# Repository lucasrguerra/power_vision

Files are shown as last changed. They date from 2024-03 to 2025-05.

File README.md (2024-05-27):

# Power Vision

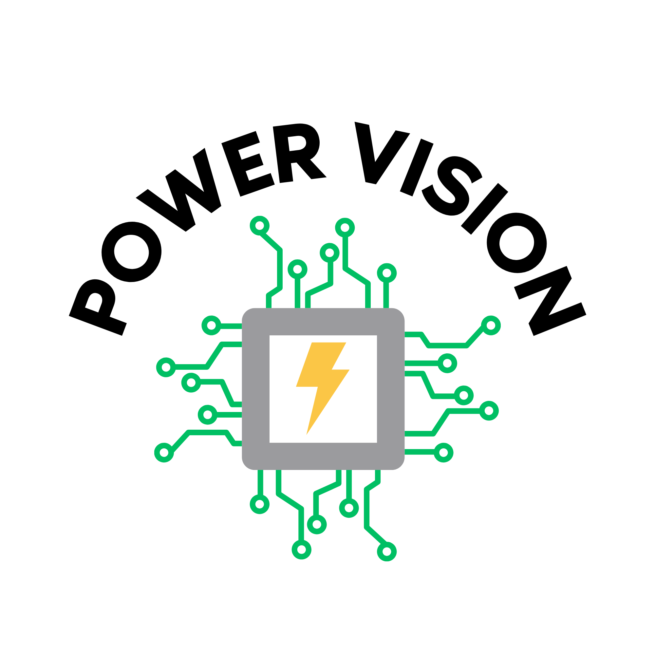
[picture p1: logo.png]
Power Vision


## Descrição

O Power Vision é um projeto de código aberto destinado ao desenvolvimento de um analisador de qualidade da energia elétrica em tempo real utilizando um hardware de baixo custo com o microcontrolador ESP32-S3. Este analisador é capaz de medir e calcular uma variedade de parâmetros elétricos em sistemas monofásicos e trifásicos, fornecendo informações cruciais para análise e monitoramento de consumo de energia.

O projeto foi desenvolvido como Trabalho de Conclusão de Curso (TCC) do curso de Ciência da Computação da Universidade Federal Rural de Pernmabuco (UFRPE) e orientado pelo Prof. Dr. Abner Corrêa Barros. O projeto tem como objetivo principal a implementação de um analisador de energia elétrica de baixo custo e alta precisão, que possa ser utilizado em residências, empresas e indústrias para monitoramento e análise de consumo de energia.

## Funcionalidades

O Power Vision atualmente tem na teoria as seguintes funcionalidades:

- **Frequência (Hz)**: Medição da frequência do sistema.
- **Tensão True RMS (Vac)**: Medição precisa da tensão eficaz do sistema.
- **Corrente True RMS (A)**: Medição precisa da corrente eficaz do sistema.
- **Potência Aparente (kVA)**: Cálculo da potência aparente do sistema.
- **Distorção Harmônica Total (%)**: Avaliação da distorção harmônica no sistema.
- **Cosseno φ**: Cálculo do cosseno do ângulo de fase.
- **Fator de Potência (%)**: Determinação do fator de potência do sistema.
- **Potência Ativa (kW)**: Cálculo da potência ativa consumida pelo sistema.
- **Potência Reativa (kVAr)**: Cálculo da potência reativa do sistema.
- **Potência de Distorção (kVAD)**: Cálculo da potência de distorção do sistema.

## Limites de medição

Assim como qualquer equipamento de medição, o Power Vision possui limites de medição para cada parâmetro elétrico. Abaixo estão os limites de medição que este projeto visa alcançar:

### Frequência
O dispositivo possiu uma forma versátil de calcular a frequência, se mas o intervalo de leitura esperado é entre 45Hz e 60Hz.

### Tensão
O dispositivo é destinado a medições em sistemas residenciais, comerciais e industriais de pequeno e médio porte, para isso, o dispositivo conta com 4 níveis possíveis de tensão de fase (não confundir com tensão de linha, que é a tensão entre fases), sendo eles:

Nível 0 = 0-475Vac (Padrão 440V)  
Nível 1 = 0-440Vac (Padrão 380V)  
Nível 2 = 0-275Vac (Padrão 220V)  
Nível 3 = 0-175Vac (Padrão 127V)  

### Corrente
O dispositivo é destinado a medições em sistemas residenciais, comerciais e industriais de pequeno e médio porte, para isso, o dispositivo conta com 7 níveis possíveis de corrente, sendo eles:

Nível 0 = Até 1000A  
Nível 1 = Até 750A  
Nível 2 = Até 500A  
Nível 3 = Até 300A  
Nível 4 = Até 200A  
Nível 5 = Até 120A  
Nível 6 = Até 80A  

## Estrutura do Projeto

O projeto está organizado da seguinte forma:

- **[`src/`](./src/)**: Contém o código fonte principal do analisador de energia, que vai no Microcontrolador. (Em desenvolvimento 🛠️)

- **[`docs/`](./docs/)**: Documentação do projeto, incluindo manuais de usuário, especificações técnicas e outras informações relevantes.

- **[`theory/`](./theory/)**: Esta pasta contém implementações em Python das fórmulas utilizadas antes de serem integradas ao código principal do microcontrolador. (Sendo atualizado para a transformada Wavelet 🛠️)

- **[`boards/`](./boards/)**: Contém informações sobre as placas desenvolvidas para o projeto e os arquivos de fabricação no formato Gerber.

## Como Contribuir

Sinta-se à vontade para contribuir com o projeto! Você pode:

- Reportar problemas encontrados.
- Propor melhorias e novas funcionalidades.
- Enviar correções ou otimizações de código.
- Compartilhar suas experiências e ideias.

## Como Utilizar

Para utilizar o Power Vision, siga estas etapas:

1. Clone o repositório para o seu ambiente de desenvolvimento com o PlatformIO instalado.
2. Instale as dependências necessárias:
    (Atenção: Este projeto ainda não possui dependências)
3. Compile e carregue o código no seu ESP32-S3.
4. Monte o circuito conforme o esquemático disponível na pasta [`docs/`](./docs/).
4. Conecte o analisador de energia ao sistema que deseja analisar.
5. Inicie o analisador e visualize os resultados pela interface serial.

## Créditos

Este projeto foi criador por [Lucas Rayan](https://www.linkedin.com/in/lucasrguerra/) (vulgo "eu") e continua sendo mantido por ele.

## Agradecimentos

A minha mãe, que sempre lutou muito para que eu e minha irmã tivéssemos uma boa educação, e que sempre me apoiou em todas as minhas decisões. E que é sem dúvida a pessoa mais importante da minha vida.

Ao [Prof. Dr. Abner Corrêa Barros](https://www.linkedin.com/in/abner-barros-5b86409/), meu orientador, que sempre esteve disposto a ajudar e doar seu tempo e conhecimento para contribuir com o desenvolvimento do projeto.

A minha grande amiga e companheira de vida, [Vitória das Dores](https://www.linkedin.com/in/vitoria-das-dores/), que sempre esteve ao meu lado me apoiando e me ajudando a superar todos os desafios.

Ao meu grande amigo e grande Engenheiro Eletrônico, [João Pontes](https://www.linkedin.com/in/joão-victor-b-pontes-b37006116/), que sempre esteve disposto a ajudar e ouvir minhas ideias e dúvidas.

## Licença

Este projeto está licenciado sob a Licença MIT. Consulte o arquivo [LICENSE](./LICENSE) para obter mais detalhes.

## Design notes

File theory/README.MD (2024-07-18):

# Teoria do Power Vision

Bem-vindo à documentação da teoria por trás do Power Vision. Este documento fornece informações detalhadas sobre a matemática e os cálculos utilizados no projeto para medir e calcular parâmetros elétricos, como tensão, corrente, potência ativa, potência reativa, fator de potência e muito mais.

## Componentes de Hardware

### Resistores para a corrente (Rcurr)

Para calcular a corrente do sistema, é necessário utilizar resistores de baixa resistência, e essa resistência é calculada levando em consideração a tensão máxima que pode ser medida pelo microcontrolador com uma margem de erro. Para simplificar os cálculos, o Jupyter Notebook [calculate_limits_of_current.ipynb](./calculate_limits_of_current.ipynb) foi criado para calcular os parâmetros de acordo com os resistores utilizados.

| Corrente Máxima do Sistema | Relação do Sensor | Corrente no Secundário | Tensão Pico a Pico no Secundário | Resistência (±1%) | Relação da Transformação |
| --- | --- | --- | --- | --- | --- |
| 1000A | 3000:1 | 0.33333A | 2.3094V  | 2Ω | 1500 |
| 750A  | 3000:1 | 0.25A | 2.33827V | 2.7Ω | 1111.11 |
| 500A  | 3000:1 | 0.16667A | 2.48261V | 4.3Ω | 697.674 |
| 300A  | 3000:1 | 0.1A | 2.35559V | 6.8Ω | 441.176 |
| 200A  | 3000:1 | 0.06667A | 2.3094V  | 10Ω  | 300 |
| 120A  | 3000:1 | 0.04A | 2.49415V | 18Ω  | 166.667 |
| 80A | 3000:1 | 0.02667A | 2.49415V | 27Ω  | 111.111 |
| 100A  | 2000:1 | 0.05A | 2.07846V | 12Ω  | 166.667 |
| 20A | 2000:1 | 0.01A | 2.35559V | 68Ω  | 29.4118 |

### Resistores para a tensão (Rvolt)

Para calcular a tensão do sistema, é necessário utilizar resistores de baixa e alta resistência, e essa resistência é calculada levando em consideração a tensão máxima que pode ser medida pelo microcontrolador com uma margem de erro e respeitando os limites do transfomador utilizado. Para simplificar os cálculos, o Jupyter Notebook [calculate_limits_of_voltage.ipynb](./calculate_limits_of_voltage.ipynb) foi criado para calcular os parâmetros de acordo com os resistores utilizados.

_**Nota:** Os valores de resistência foram calculados considerando o transformador de corrente ZMPT101B com uma relação de transformação de 2mA:2mA._

#### Resistores para o Primário (RPvolt) do Transformador de Tensão

| Tensão do Sistema | Tensão Máxima do Sistema | Corrente no Transformador | Resistência RPvolt (±1%) | Tensão Pico a Pico no Secundário | Relação da Transformação |
| --- | --- | --- | --- | --- | --- | --- |
| 440Vac | 475Vac | 0.00161A | 510kΩ | 2.40294V | 1186.05 |
| 380Vac | 440Vac | 0.00162A | 470kΩ | 2.41532V | 1093.02 |
| 220Vac | 275Vac | 0.00159A | 300kΩ | 2.365V | 697.674 |
| 127Vac | 175Vac | 0.00168A | 180kΩ | 2.50833V | 418.605 |

## Matemática por trás do projeto

O Power Vision utiliza uma série de fórmulas e conceitos matemáticos para calcular com precisão os parâmetros elétricos do sistema. Abaixo estão alguns dados sobre os cálculos utilizados no projeto e as suas versões convertidas em funções na linguagem de programação Python.

_**Nota:** As fórmulas e cálculos a utilizados consideram que você tenha a mesma quantidade de amostras da tensão e da corrente. E que essa quantidade de amostras sejam um multiplo de 2, para ficilitar a utilização da FFT._

### Filtragem do sinal

Para remover os ruídos do sinal de corrente e tensão, é utilizado um filtro digital de média móvel. A função para calcular a média móvel é dada por:

```python
def filtro_media_movel(sinal, janela):
    sinal_filtrado = []
    fator_de_normalizacao = 1.0 / janela
    quantidade_de_amostras = len(sinal)

    for i in range(quantidade_de_amostras):
        inicio = max(0, i - (janela // 2))
        fim = min(quantidade_de_amostras, i + (janela // 2))
        media = sum(sinal[inicio:fim]) * fator_de_normalizacao
        sinal_filtrado.append(media)

    return sinal_filtrado
```

### Frequência (Hz)

A frequência é a quantidade de ciclos por segundo em um sinal elétrico. A função para calcular a frequência é dada por:

```python
def frequencia(sinal, milissegundos_entre_amostras):
    quantidade_de_amostras = len(sinal)
    duracoes_dos_ciclos = []
    momento_da_ultima_amostra = 0

    for i in range(quantidade_de_amostras):
        amostra = sinal[i]

        if amostra > 0 :
            momento_atual = i * milissegundos_entre_amostras
            if momento_da_ultima_amostra >= 0 and sinal[i - 1] < 0:
                duracoes_dos_ciclos.append(momento_atual - momento_da_ultima_amostra)
                momento_da_ultima_amostra = momento_atual

    return 1000 / (sum(duracoes_dos_ciclos) / len(duracoes_dos_ciclos))
    
```

### Tensão True RMS (Vac)

A tensão eficaz é a calculada pela raiz quadrada da média dos quadrados das amostras do sinal de tensão, em inglês conhecida como Root Mean Square (RMS). A função para calcular a tensão eficaz é dada por:

```python
def tensao_rms(sinal_da_tensao):
    return math.sqrt(sum([amostra ** 2 for amostra in sinal_da_tensao]) / len(sinal_da_tensao))
```

### Corrente True RMS (A)

A corrente eficaz é a calculada pela raiz quadrada da média dos quadrados das amostras do sinal de corrente, ou em inglês, Root Mean Square (RMS). A função para calcular a corrente eficaz é dada por:

```python
def corrente_rms(sinal_da_corrente):
    return math.sqrt(sum([amostra ** 2 for amostra in sinal_da_corrente]) / len(sinal_da_corrente))
```

### Potência Aparente (VA)

A potência aparente é a potência total em um circuito elétrico, e é dada pelo produto da tensão eficaz e da corrente eficaz. A função para calcular a potência aparente é dada por:

```python
def potencia_aparente(tensao_eficaz, corrente_eficaz):
    return tensao_eficaz * corrente_eficaz
```

### Distorção Harmônica Total (THD)

A distorção harmônica total é uma medida da distorção harmônica em um sinal elétrico. E no projeto é calculada pelo sinal da corrente. Para fazer a análisa da distorção harmônica total, é necessário transformar o sinal do domínio do tempo para o domínio da frequência, e para isso foi utilizado a Transformada Rápida de Fourier, ou em inglês, Fast Fourier Transform (FFT). A função para calcular a distorção harmônica total é dada por:

```python
def thd(sinal_da_corrente, frequencia, corrente_eficaz, quantidade_de_harmonicas_analisadas, amplitude_minima_da_harmonica):
    quantidade_de_amostras = len(sinal_da_corrente)
    fft_da_corrente = np.fft.fft(sinal_da_corrente)
    amplitudes_da_fft_da_corrente = (2 / quantidade_de_amostras) * np.abs(fft_da_corrente)
    integral_do_quadrado_das_correntes = []

    segunda_harmonica = 2
    for i in range(segunda_harmonica, quantidade_de_harmonicas_analisadas + 2):
        frequencia_da_harmonica = int(i * frequencia)
        frequecias_proximas = [
            amplitudes_da_fft_da_corrente - 2,
            amplitudes_da_fft_da_corrente - 1,
            amplitudes_da_fft_da_corrente,
            amplitudes_da_fft_da_corrente + 1,
            amplitudes_da_fft_da_corrente + 2
        ]
        hamonica_real = max(frequencias_proximas)

        if hamonica_real > amplitude_minima_da_harmonica:
            integral_do_quadrado_das_correntes.append(hamonica_real ** 2)

    return math.sqrt(integral_do_quadrado_das_correntes) / corrente_eficaz
```

### Potência Ativa (W)

A potência ativa é a potência que se converte em trabalho útil, e é dada pela soma do produto das amostras do sinal de tensão e corrente dividido pelo número de amostras. A função para calcular a potência ativa é dada por:

```python
def potencia_ativa(tensao, corrente):
    return sum([tensao[i] * corrente[i] for i in range(len(tensao))]) / len(tensao)
```

### Cosseno da Fase (cos(θ))

O cosseno da fase é a medida do deslocamento angular entre a tensão e a corrente em um circuito elétrico. A função para calcular o cosseno da fase é dada por:

```python
def cosseno_da_fase(potenca_ativa, potencia_aparente):
    return potencia_ativa / potencia_aparente
```

### Fator de Potência (FP)

O fator de potência é a medida da eficiência de um circuito elétrico, e é dada pelo cosseno da fase. A função para calcular o fator de potência é dada por:

```python
def fator_de_potencia(cosseno_da_fase, distorcao_harmonica_total):
    return cosseno_da_fase / math.sqrt(1 + distorcao_harmonica_total ** 2)
```

### Potência Reativa (VAr)

A potência reativa é a potência que não se converte em trabalho útil, mas é necessária para manter os campos eletricos e magnéticos em um circuito elétrico. A função para calcular a potência reativa é dada por:

```python
def potencia_reativa(potencia_aparente, fator_de_potencia):
    return math.sin(math.acos(fator_de_potencia)) * potencia_aparente
```

### Potência de Distorsão (VAD)

A potência de distorção é a potência que é perdida devido a distorção harmônica em um circuito elétrico. A função para calcular a potência de distorção é dada por:

```python
def potencia_de_distorsao(potencia_aparente, potencia_ativa, potencia_reativa):
    return math.sqrt(abs((potencia_aparente ** 2) - (potencia_ativa ** 2) - (potencia_reativa ** 2)))
```

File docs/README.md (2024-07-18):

# Documentação do Power Vision

Bem-vindo à documentação oficial do Power Vision. Este documento fornece informações detalhadas sobre como usar, configurar e estender o analisador de energia de baixo custo desenvolvido com o microcontrolador ESP32-S3.

## Conteúdo

1. [Introdução](#introdução)
2. [Simulação do Circuito](#simulação-do-circuito)
3. [Configuração do Ambiente de Desenvolvimento](#configuração-do-ambiente-de-desenvolvimento)
4. [Componentes utilizados](#componentes-utilizados)
5. [Diagrama esquemático](#diagrama-esquemático)
6. [Placa do projeto](#placa-do-projeto)

## Introdução

O Power Vision é um projeto de código aberto que visa fornecer uma solução acessível e eficaz para análise de energia em sistemas elétricos. Ele busca oferecer uma variedade de funcionalidades para medição e cálculo de parâmetros elétricos, como tensão, corrente, potência ativa, potência reativa, fator de potência e muito mais com um custo acessível. O projeto é baseado no microcontrolador ESP32-S3 e utiliza sensores de corrente e tensão populares e de baixo custo para realizar as medições.

## Simulação do Circuito

Para simular o circuito do Power Vision, você pode usar o software [Falstad Circuit Simulator](https://www.falstad.com/circuit/). Basta abrir o arquivo [simulation.falstad](./simulation.falstad) no simulador e você poderá visualizar e simular o circuito do projeto.

## Configuração do Ambiente de Desenvolvimento

Para configurar o ambiente de desenvolvimento e começar a trabalhar com o Power Vision, basta ter o [PlatformIO](https://platformio.org) instalado em seu ambiente de desenvolvimento. Eu recomendo usar o [VSCode](https://code.visualstudio.com) com a extensão PlatformIO.

Depois de instalar o PlatformIO, basta clonar este repositório e abrir o projeto no VSCode. O PlatformIO irá instalar automaticamente todas as dependências necessárias para o projeto.

## Componentes utilizados (Considerando um sistema com 3 fases e 1 neutro)

- **1x Microcontrolador - ESP32-S3 DevKitC**
- **8x Amplificador Operacional - TL082**
- **8x Socket DIP-8**
- **4x Tranformador de corrente (não invasivo) - 3000:1 (Até 1000A)**
- **3x Tranformador de potencial - ZMPT101B**
- **1x Regulador de Tensão - LM1117T-3.3**
- **1x Fonte de Tensão - HLK-5M12**
- **6x Terminal de parafuso - 2 Pinos P5.08mm**
- **1x Microswitch - SS-12D00G4**
- **1x Capacitor de Tântalo 35v 47uF**
- **1x Capacitor de Tântalo 16v 100uF**
- **14x Diodo Zener 3V3 1W - IN4733A**
- **1x Pin Header 2.54mm (01x01P)**
- **2x Pin Header 2.54mm (01x03P)**
- **1x Pin Header 2.54mm (01x04P)**
- **1x Pin Header 2.54mm (01x06P)**
- **2x Pin Socket 2.54mm (01x22P)**
- **4x Resistor (Rcurr) - 1/4W 1%**
- **3x Resistor (RPvolt) - 1/4W 1%**
- **3x Resistor (RSvolt) - 1/4W 1%**
- **2x Resistor 10kΩ - 1/4W 0.1%**
- **7x Resistor 50Ω - 1/4W 1%**
- **1x Cartão microSD - Módulo de Cartão SD (SPI) - Opcional**

### Tabelas Importantes

#### Tipo de Sistema Elétrico (SYSTEM_TYPE)

| Tipo de Sistema | Valor da Variável (SYSTEM_TYPE) |
| --- | --- |
| Monofásico (P+N) | 0 |
| Bifásico (2P) | 0 |
| Bifásico (2P+N)  | 1 |
| Trifásico (3P+N) | 2 |

_**Nota:** Lembre-se de mudar o valor da variável `SYSTEM_TYPE` no código do projeto para o valor correspondente na tabela acima_

#### Resistores para a corrente (Rcurr)

| Corrente Máxima (A) | Relação do Sensor | Resistência (Ω) | Valor da Variável (CURRENT_TYPE) |
| --- | --- | --- | --- |
| 1000 | 3000:1 | 2 | 0 |
| 750  | 3000:1 | 2.7 | 1 |
| 500  | 3000:1 | 4.3 | 2 |
| 300  | 3000:1 | 6.8 | 3 |
| 200  | 3000:1 | 10  | 4 |
| 120  | 3000:1 | 28  | 5 |
| 80 | 3000:1 | 27  | 6 |
| 100  | 2000:1 | 12  | 7 |
| 20 | 2000:1 | 68  | 8 |

_**Nota:** Lembre-se de mudar o valor da variável `CURRENT_TYPE` no código do projeto para o valor correspondente na tabela acima_

#### Resistores para a tensão (RPvolt)

| Tensão de Operação (Vac) | Resistência do Primário (Ω) | Valor da Variável (VOLTAGE_TYPE) |
| --- | --- | --- |
| 440 | 510k | 0 |
| 380 | 470k | 1 |
| 220 | 300k | 2 |
| 127 | 180k | 3 |

_**Nota:** Lembre-se de mudar o valor da variável `VOLTAGE_TYPE` no código do projeto para o valor correspondente na tabela acima_

## Diagrama esquemático

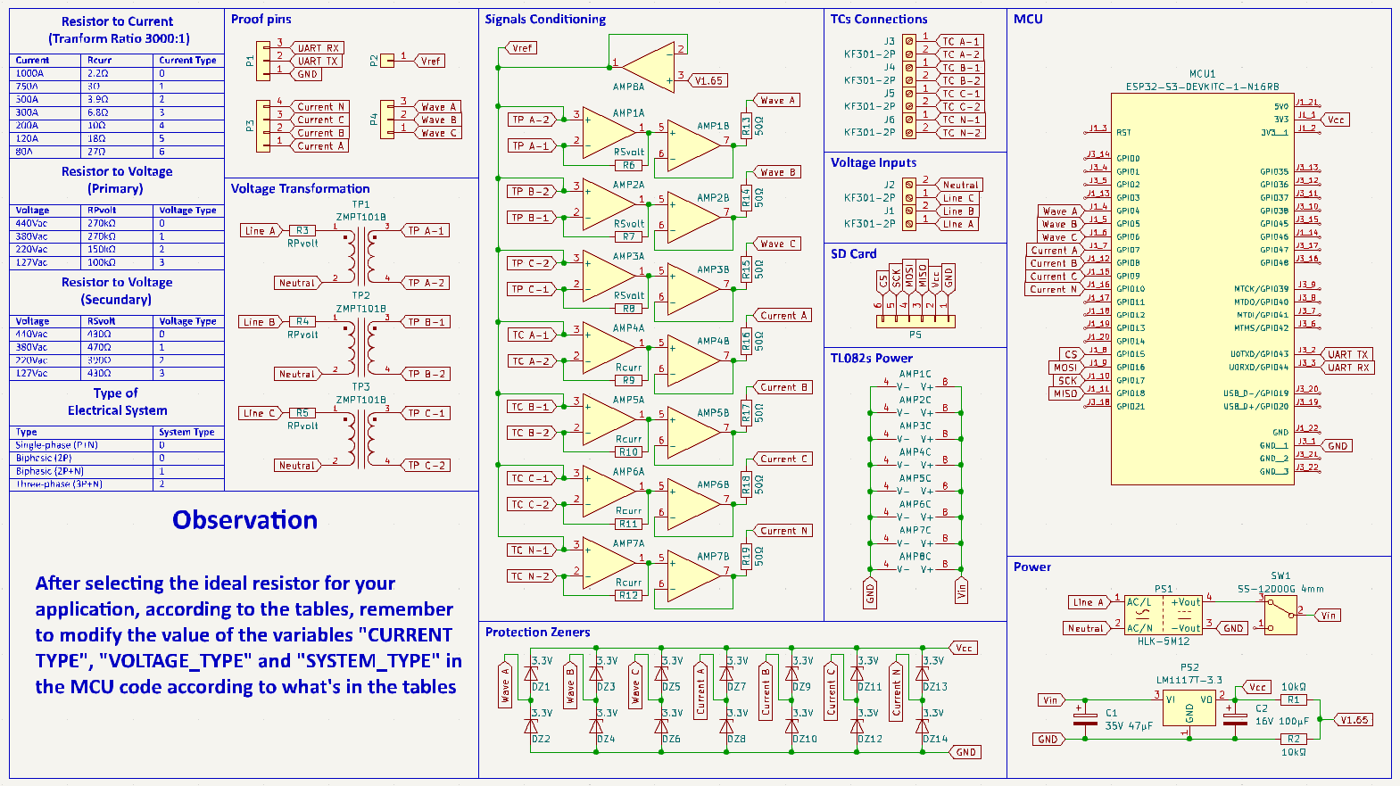
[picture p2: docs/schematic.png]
Diagrama esquemático


## Placa do projeto

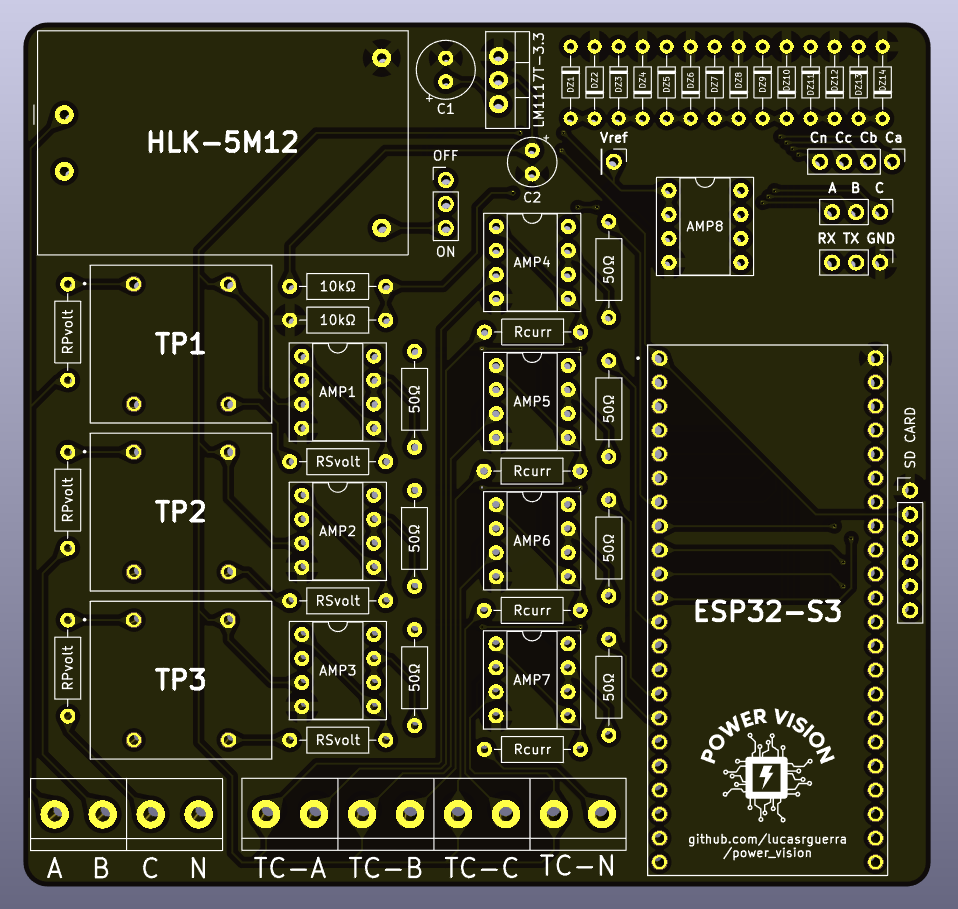
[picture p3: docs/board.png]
Placa do projeto


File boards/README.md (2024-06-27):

# Placas do projeto

## Descrição

Nesta pasta estão todos os arquivos das placas desenvolvidas para este projeto utilizando o software KiCAD. Dentre esses arquivos, estão o esquemático, o layout da placa e seus arquivos de fabricação no formato Gerber.

## Versões Disponíveis

- **[`v4.0`](./v4.0/)**: Essa é a 12ª versão da placa e no modelo SMT (Surface-Mount Technology).
- **[`v3.4`](./v3.4/)**: Essa é a 11ª versão da placa e no modelo SMT (Surface-Mount Technology).
- **[`v3.3`](./v3.3/)**: Essa é a 10ª versão da placa e no modelo THT (Through-Hole Technology).
- **[`v3.2`](./v3.2/)**: Essa é a 9ª versão da placa e no modelo THT (Through-Hole Technology).
- **[`v3.1`](./v3.1/)**: Essa é a 8ª versão da placa e no modelo THT (Through-Hole Technology).
- **[`v3.0`](./v3.0/)**: Essa é a 7ª versão da placa e no modelo THT (Through-Hole Technology).
- **[`v2.1`](./v2.1/)**: Essa é a 6ª versão da placa e no modelo THT (Through-Hole Technology).
- **[`v2.0`](./v2.0/)**: Essa é a 5ª versão da placa e no modelo THT (Through-Hole Technology).
- **[`v1.1`](./v1.1/)**: Essa é a 4ª versão da placa e no modelo THT (Through-Hole Technology).
- **[`v1.0`](./v1.0/)**: Essa é a 3ª versão da placa e no modelo THT (Through-Hole Technology).
- **[`v0.7`](./v0.7/)**: Essa é a 2ª versão da placa e no modelo SMT (Surface-Mount Technology).
- **[`v0.5`](./v0.5/)**: Essa é a 1ª versão da placa e no modelo THT (Through-Hole Technology).

## Dados das Placas

### Placa v4.0 (SMT) - 75,438mm de largura x 74,930mm de altura

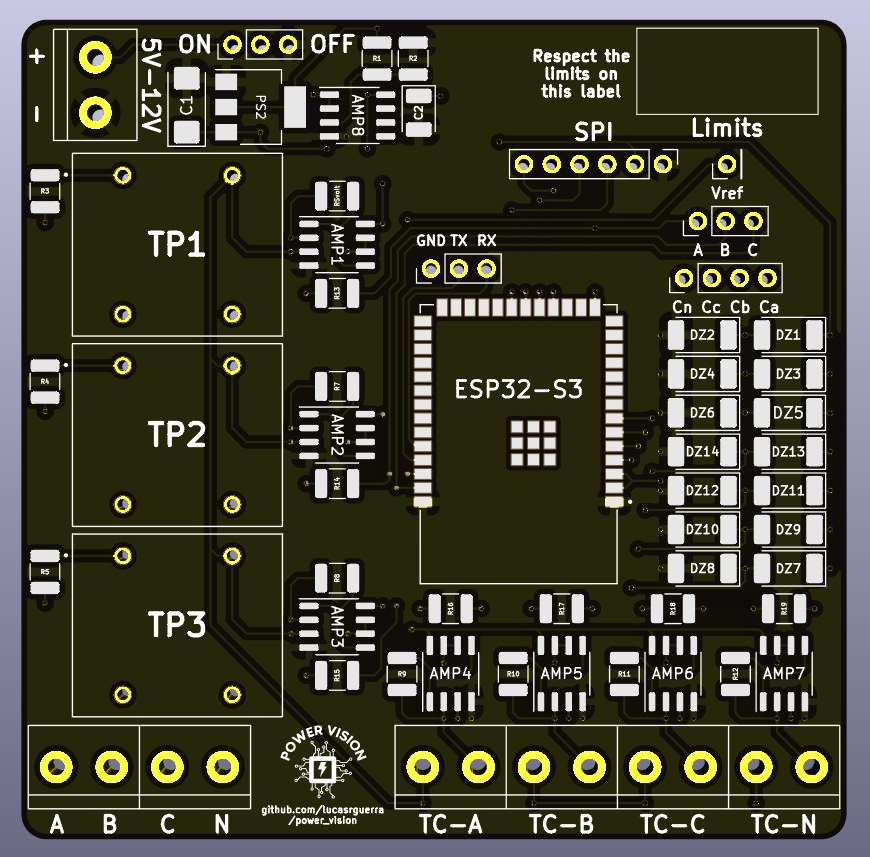
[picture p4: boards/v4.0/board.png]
Placa v4.0


Essa placa foi desenvolvida com um design mais compacto e organizado da versão anterior. Ela possui apenas 2 camadas de cobre para manter o baixo custo. Essa placa pussui ainda mais cuidado com a simetria das trilhas diferenciais para garantir o menor erro de impedância o possível nas medições. Além disso, a possui o plano terra em ambas as camadas, garantindo uma melhor dissipação de calor e reduzindo a interferência eletromagnética. Por fim, a fonte de alimentação interna foi removida, pois ela era um limitante de tensão de operação do circuito.

### Placa v3.4 (SMT) - 77,6358mm de largura x 89,3210mm de altura

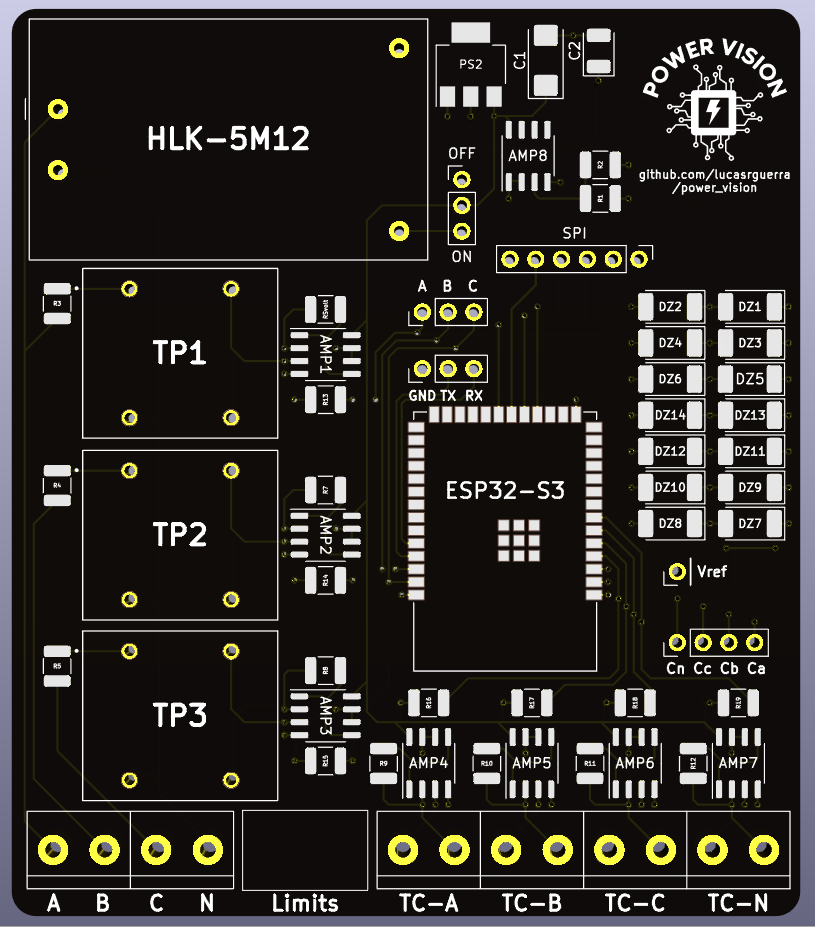
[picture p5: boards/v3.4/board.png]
Placa v3.4


Essa placa foi desenvolvida com um design mais compacto e organizado da versão anterior. Ela possui 4 camadas de cobre, tornando mínima a impedância do GND e da tensão de referência para as medições. Essa placa também possui um cuidado com a simetria das trilhas diferenciais para garantir o menor erro de impedância o possível nas medições. Além disso, a possui uma camada dedicada ao plano terra, garantindo uma melhor dissipação de calor e reduzindo a interferência eletromagnética.

### Placa v3.3 (THT) - 96,012mm de largura x 91,440mm de altura (Atual THT)

Placa v3.3

Essa placa foi desenvolvida mantendo o design compacto e organizado da versão anterior. Ela possui além dos circuitos de transimpedância, os buffers de tensão, garantindo uma maior precisão nas medições. A placa também possui resistores de 50Ω para aumentar a estabilidade dos sinais vindos dos buffers de tensão e limitar a corrente que passa pelos diodos zener de proteção. Além disso, a placa é a primeira a possuir um plano de terra, garantindo uma melhor dissipação de calor e reduzindo a interferência eletromagnética.

### Placa v3.2 (THT) - 94,448mm de largura x 92,710mm de altura

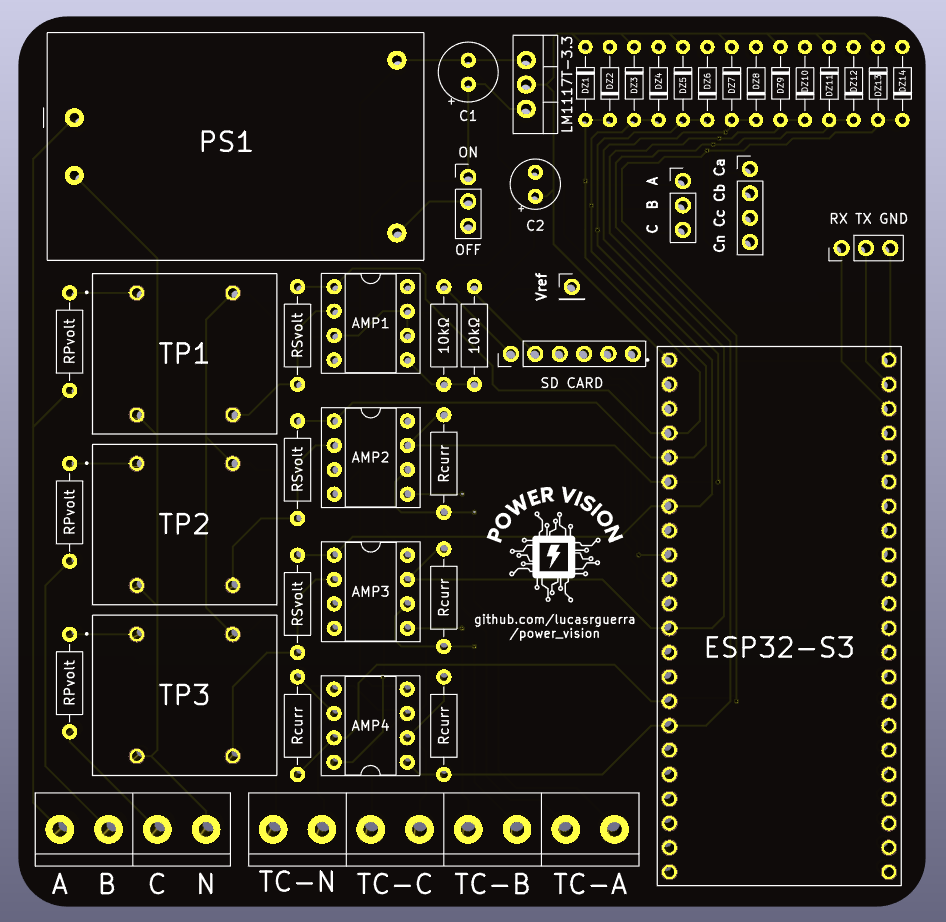
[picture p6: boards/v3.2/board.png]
Placa v3.2


Essa placa foi desenvolvida para ser mais compacta e organizada que a anterior. Ela não usa mais os buffers de tensão, que foram substituidos pelo mesmo amplificadores operacionais, mas agora em uma configuração de transimpedância, garantiando uma maior precisão nas medições. A placa também não necessita mais do circuito de seleção do tipo de sistema elétrico, deixando essa opção para o software. Além disso, a placa possui um layout mais compacto e organizado que as anteriores.

### Placa v3.1 (THT) - 99,842mm de largura x 91,948mm de altura

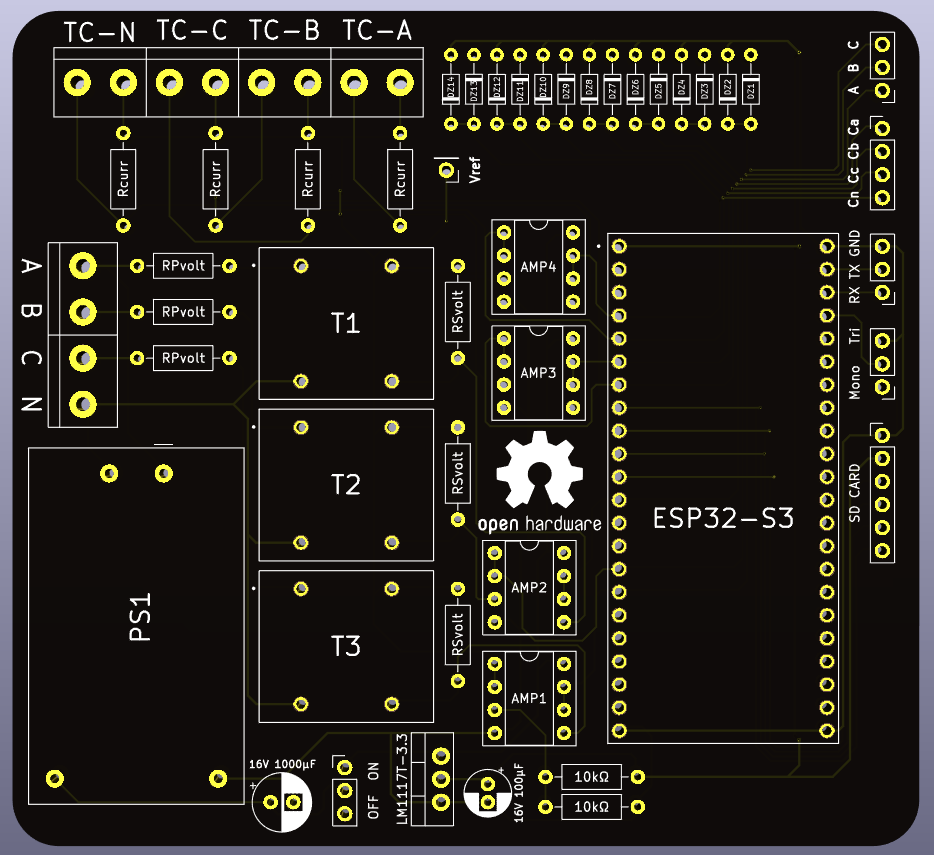
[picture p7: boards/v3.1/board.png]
Placa v3.1


Essa placa foi desenvolvida sem a necessidade da leitura das tensões de linha. Ela possui em seu esquemático as tabelas de resistores para cada nível de tensão e corrente no qual se deseja operar. Vale ressaltar que todos os resistores shunt utilizados foram recalculados para melhorar a precisão das medições e aproveitar melhor a faixa de operação do ADC do ESP32-S3, assim como, todos os sinais agora estão conectados a canais do ADC 1 do ESP32-S3, trazendo uma maior precisão as leituras. Além disso, a placa possui um layout mais compacto que as anteriores.

### Placa v3.0 (THT) - 113,284mm de largura x 98,044mm de altura

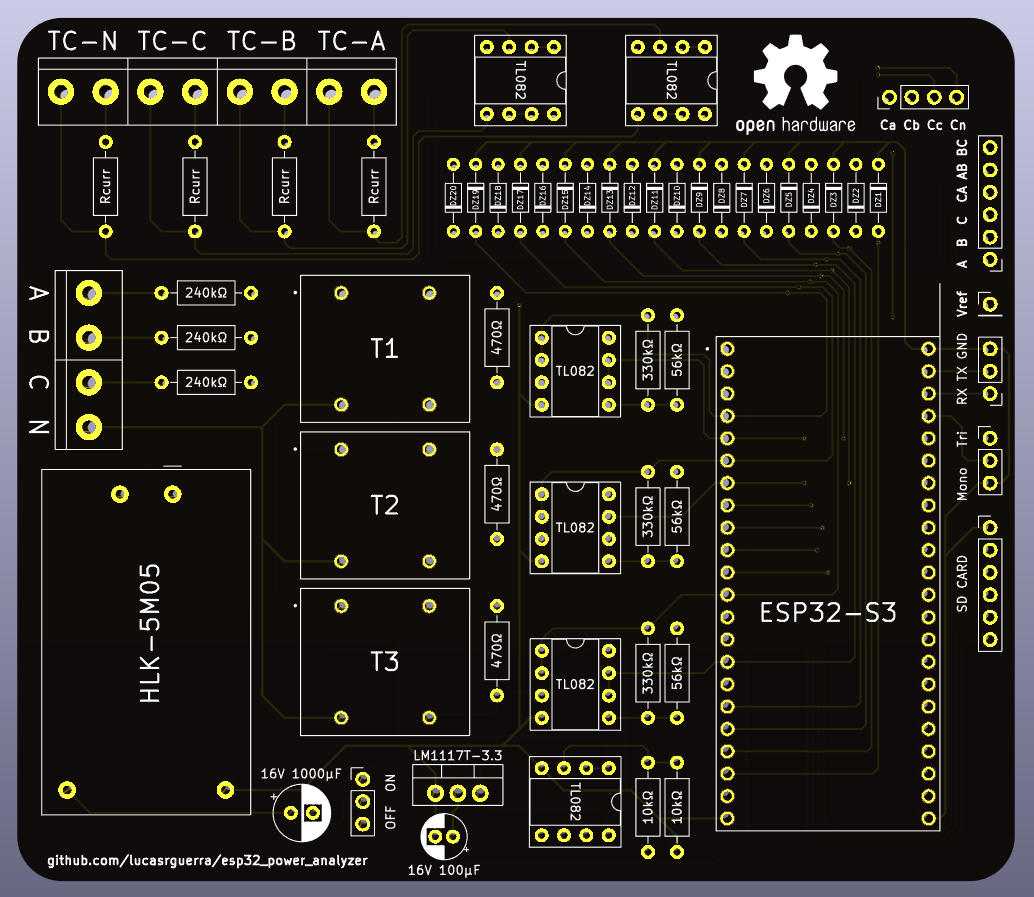
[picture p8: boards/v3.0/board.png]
Placa v3.0


Essa placa foi desenvolvida para ser condicionar melhor os sinais de corrente e tensão, utilizando diversos buffers para isso. Ela não possui mais um circuito de seleção de níveis de corrente, operando de acordo com a resistor shunt utilizado. Ela também não possui mais um circuito de gerenciamento de bateria. Vale ressaltar que todos os resistores shunt utilizados foram recalculados para melhorar a precisão das medições e aproveitar melhor a faixa de operação do ADC do ESP32-S3. Além disso, a placa possui um layout mais compacto e organizado que as anteriores.

### Placa v2.1 (THT) - 139,700mm de largura x 116,840mm de altura

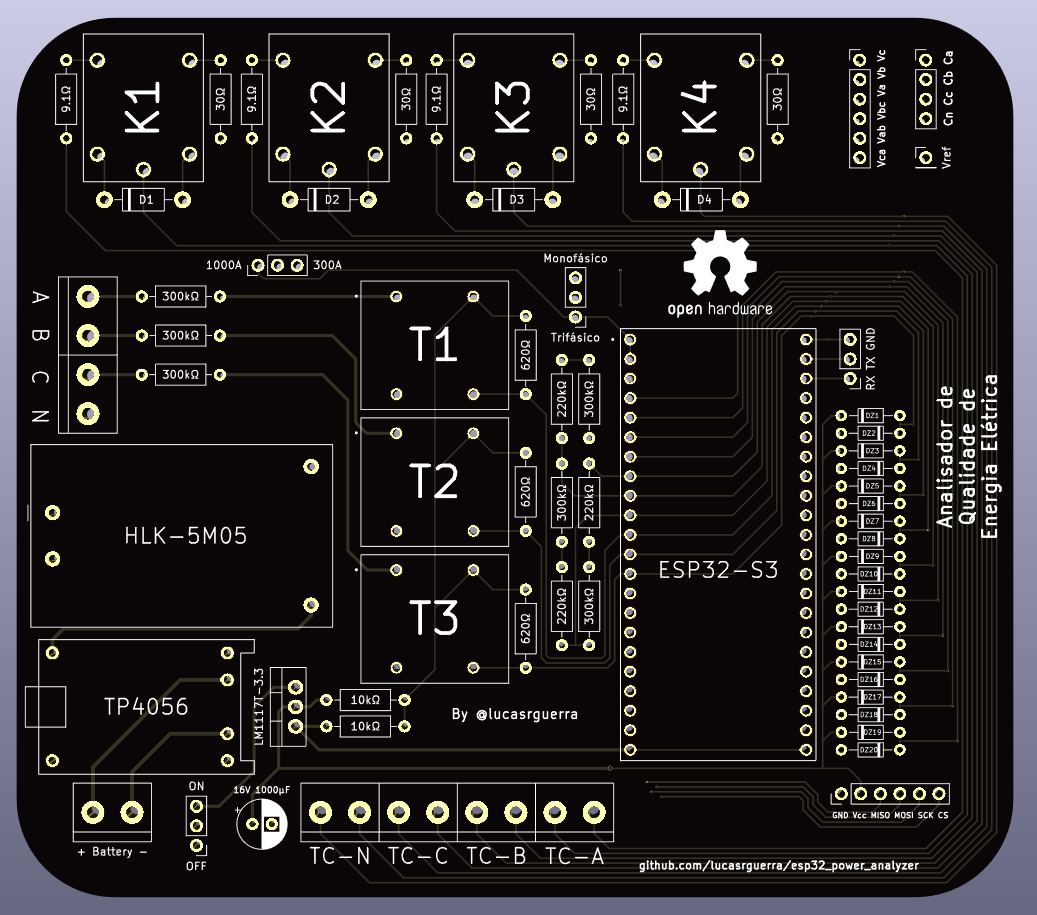
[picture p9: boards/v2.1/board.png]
Placa v2.1


Essa placa foi desenvolvida para ser mais compacta e organizada que a anterior. Além disso, ela possui pequenas correções, como a seleção manual do nível de corrente a ser utilizado nas medições e também  a largura de cada trilha da placa, aumentando a largura de trilhas com maior corrente. Nessa placa a cor da placa também foi alterada para preto.

### Placa v2.1 (THT) - 144,780mm de largura x 101,419mm de altura

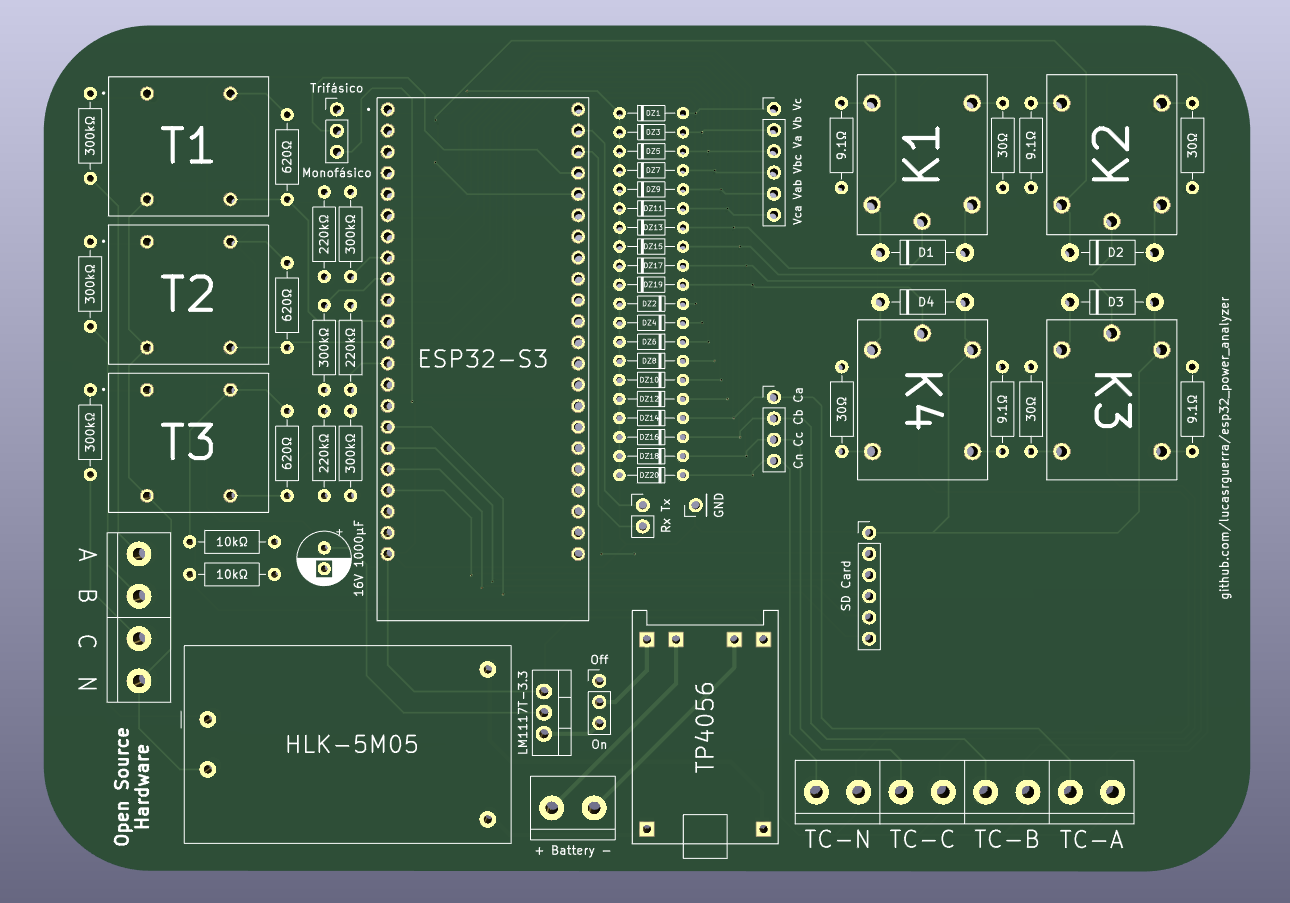
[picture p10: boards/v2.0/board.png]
Placa v2.0


Essa placa possui um menos transformadores de potencial, mas tem agora um circuito resposável pelo gerenciamento da energia utilizada na placa, com suporte para baterias 18650 de Ion-Lítion, um seleção de níveis de corrente, sendo eles 300A e 1000A, e suporte a módulos de cartão SD. Além disso, a placa possui um layout mais organizado que as anteriores. Além disso, ela possui pequenas correções, como a adição de um diodo retificador para proteção do circuito de seleção de níveis de corrente e a correção do identificador de todos os componentes no Footprint.

### Placa v1.1 (THT) - 143,510mm de largura x 73,025mm de altura

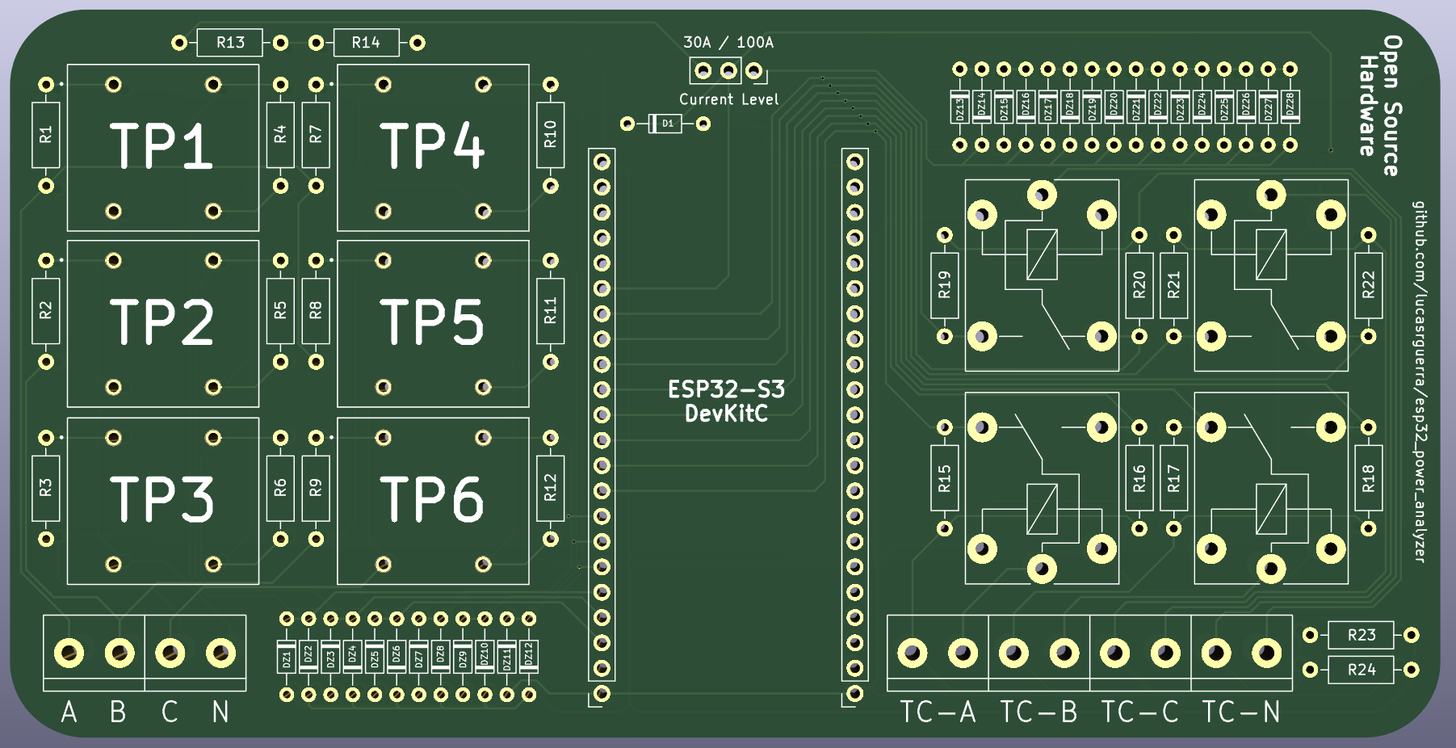
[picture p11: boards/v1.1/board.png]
Placa v1.1


Essa placa possui o mesmo layout da anterior. Porém, foram corrigidos os nomes dos Diodos Zener no Footprint e foi adicionado um Diodo Retificador para proteção do circuito de seleção de níveis de corrente.

### Placa v1.0 (THT) - 143,510mm de largura x 73,025mm de altura

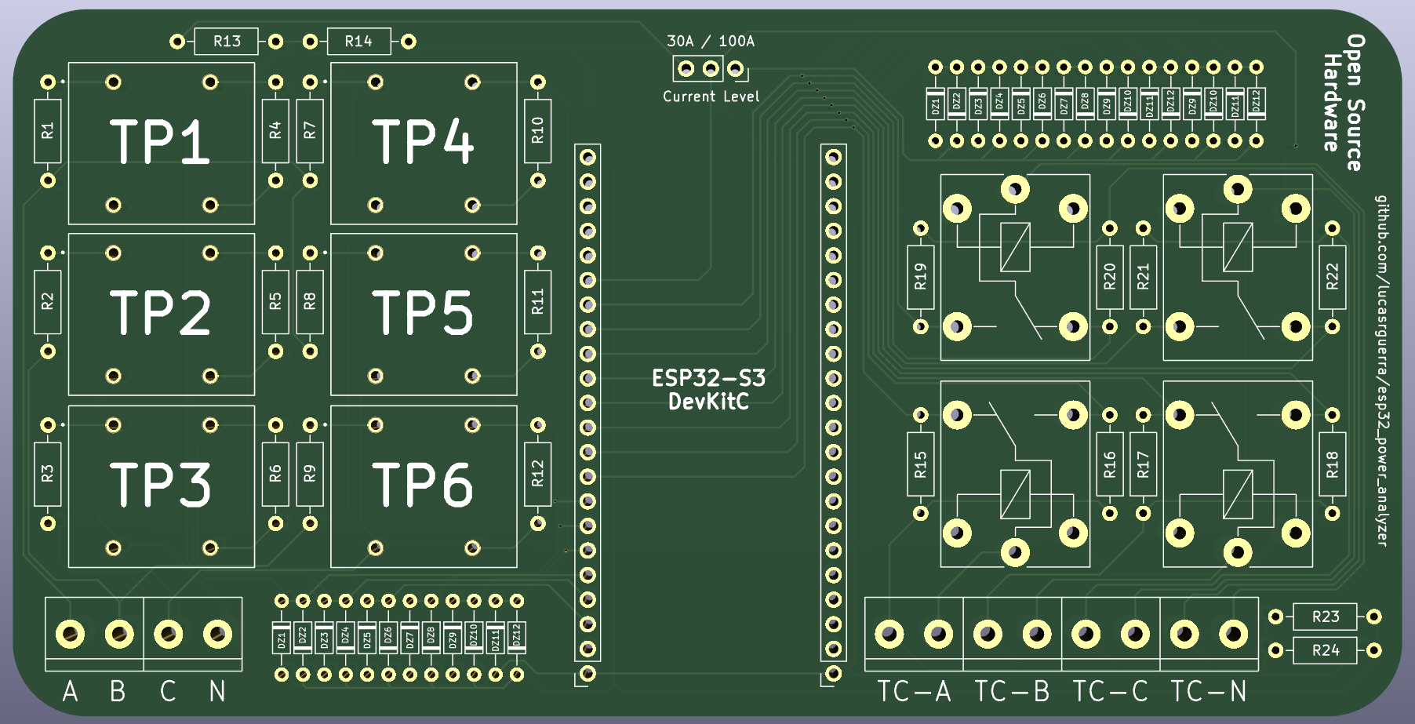
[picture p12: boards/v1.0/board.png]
Placa v1.0


Essa placa possui um layout mais compacto e organizado que as anteriores, além de ter a conexão entre o ESP32-S3 e o módulo de interrupção de níveis de corrente. E os níveis de corrente dessa placa são 30A e 100A, possibilitando uma leiura mais precisa e adequada ao sensor utilizado, especialmente em baixas correntes.

### Placa v0.7 (SMT) - 90,170mm de largura x 82,423mm de altura

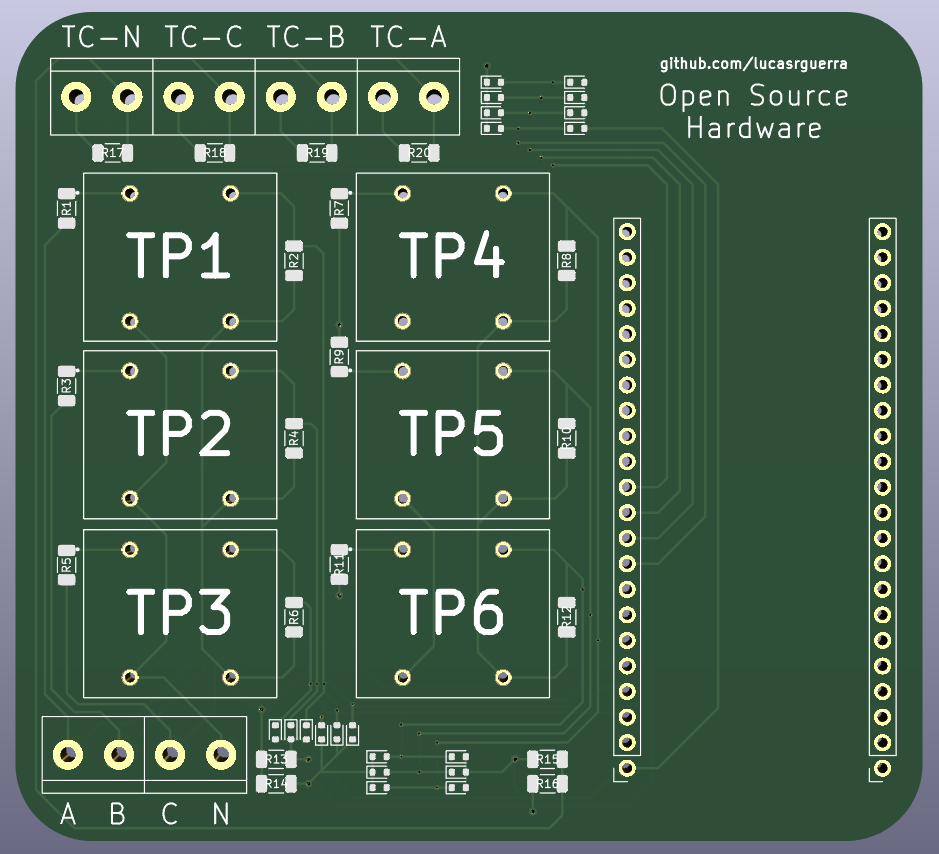
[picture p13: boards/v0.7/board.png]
Placa v0.7


Essa placa possui um layout mais compacto e organizado que a primeira versão. Porém, ele não possui a seleção de níveis de corrente, lendo apenas na escala de 100A.

### Placa v0.5 (THT) - 119,380mm de largura x 116,840mm de altura

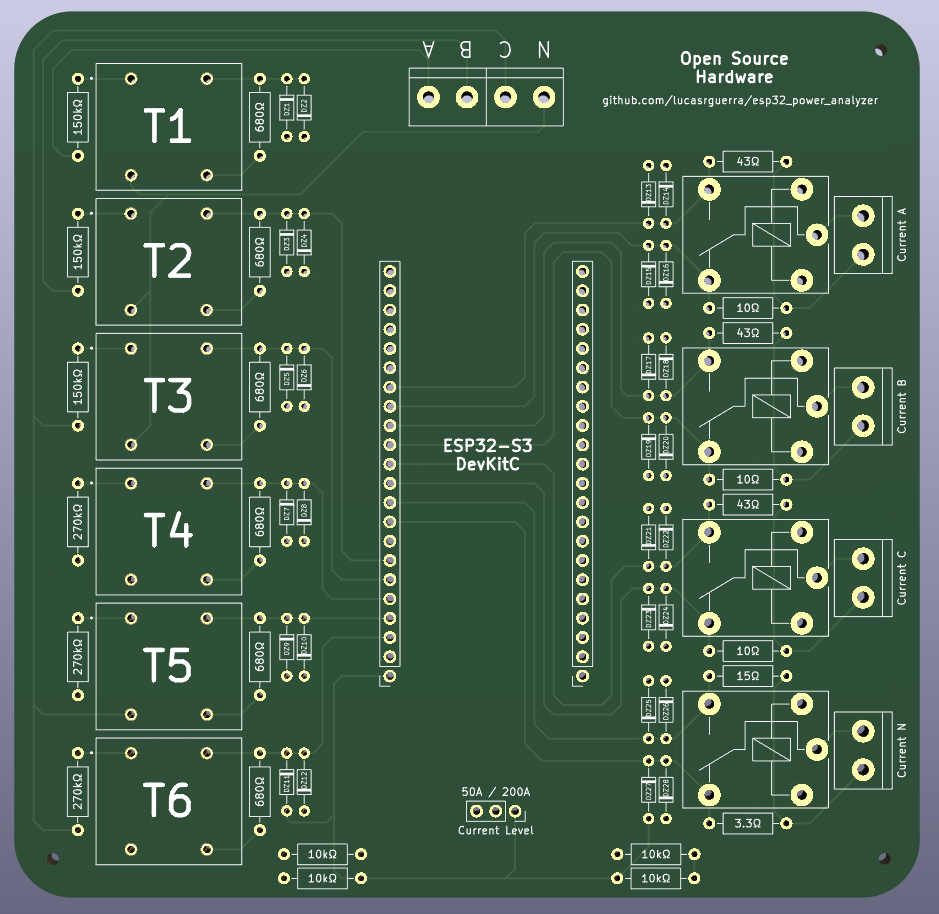
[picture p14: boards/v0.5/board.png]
Placa v0.5


Essa placa possui um layout menos compacto e organizado. Além disso, ela possui a seleção de níveis de corrente, lendo na escala de 50A e 200A.

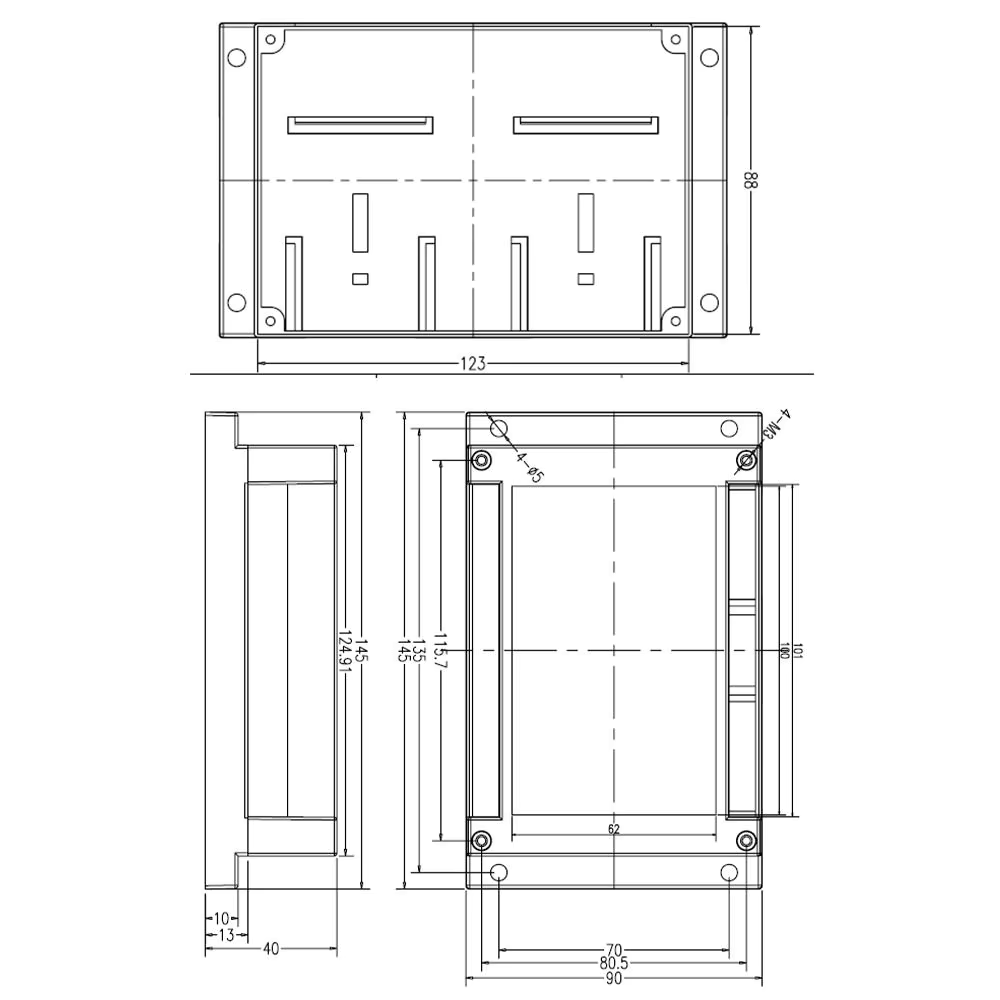
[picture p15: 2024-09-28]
docs/case.png

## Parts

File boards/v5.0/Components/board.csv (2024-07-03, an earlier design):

Id | Designador | Footprint | Quantidade | Designação | Fornecedor e referência
1 | R20,R16,R17,R18,R19,R15,R13,R14 | R_1210_3225Metric | 8 | 50Ω | Resistor 50Ω 1% 1210
2 | AMP3,AMP8,AMP6,AMP4,AMP7,AMP5,AMP2,AMP1 | SO-8_3.9x4.9mm_P1.27mm | 8 | TL082 | TL082C
3 | DZ14,DZ2,DZ13,DZ6,DZ5,DZ11,DZ3,DZ12,DZ9,DZ7,DZ4,DZ1,DZ8,DZ10 | D_MELF | 14 | 3.3V | Diode Zener ZM4728 3.3V
4 | R9,R11,R10,R12 | R_1210_3225Metric | 4 | Rcurr | Resistor 24Ω 1% 1210
5 | TP2,TP1,TP3 | XFMR_ZMPT101B | 3 | ZMPT101B | ZMPT101B
6 | R7,R6,R8 | R_1210_3225Metric | 3 | RSvolt | Resistor 620Ω 1% 1210
7 | MCU1 | XCVR_ESP32-S3-WROOM-2-N32R8V | 1 | ESP32-S3-WROOM-1-N16R8 | ESP32-S3-WROOM-1-N16R8
8 | J7,J4,J3,J6,J2,J5,J1 | TerminalBlock_bornier-2_P5.08mm | 7 | KF301-2P | KF301-2P
9 | R4,R3,R5 | R_1210_3225Metric | 3 | RPvolt | Resistor 180kΩ 1% 1210
10 | P1,P4 | PinHeader_1x03_P2.54mm_Vertical | 2 | Pin Header | Pin Header 1x03 2.54mm
11 | R2,R1 | R_1210_3225Metric | 2 | 10kΩ | Resistor 10kΩ 0.1% 1210
12 | SW1 | PinHeader_1x03_P2.54mm_Vertical | 1 | SS-12D00G 4mm | SS-12D00G 4mm Switch
13 | C2 | CP_EIA-3528-15_AVX-H | 1 | 10V 100µF | Tantalum Capacitor 10V 100µF 3528
14 | P5 | PinHeader_1x06_P2.54mm_Vertical | 1 | Pin Header | Pin Header 1x06 2.54mm
15 | P3 | PinHeader_1x04_P2.54mm_Vertical | 1 | Pin Header | Pin Header 1x04 2.54mm
16 | C1 | CP_EIA-6032-20_AVX-F | 1 | 25V 47µF | Tantalum Capacitor 25V 47µF 6032
17 | P2 | PinHeader_1x01_P2.54mm_Vertical | 1 | Pin Header | Pin Header 1x01 2.54mm
18 | PS1 | SOT-223-3_TabPin2 | 1 | AMS1117-3.3 | AMS1117 1A Fixed 3.3V

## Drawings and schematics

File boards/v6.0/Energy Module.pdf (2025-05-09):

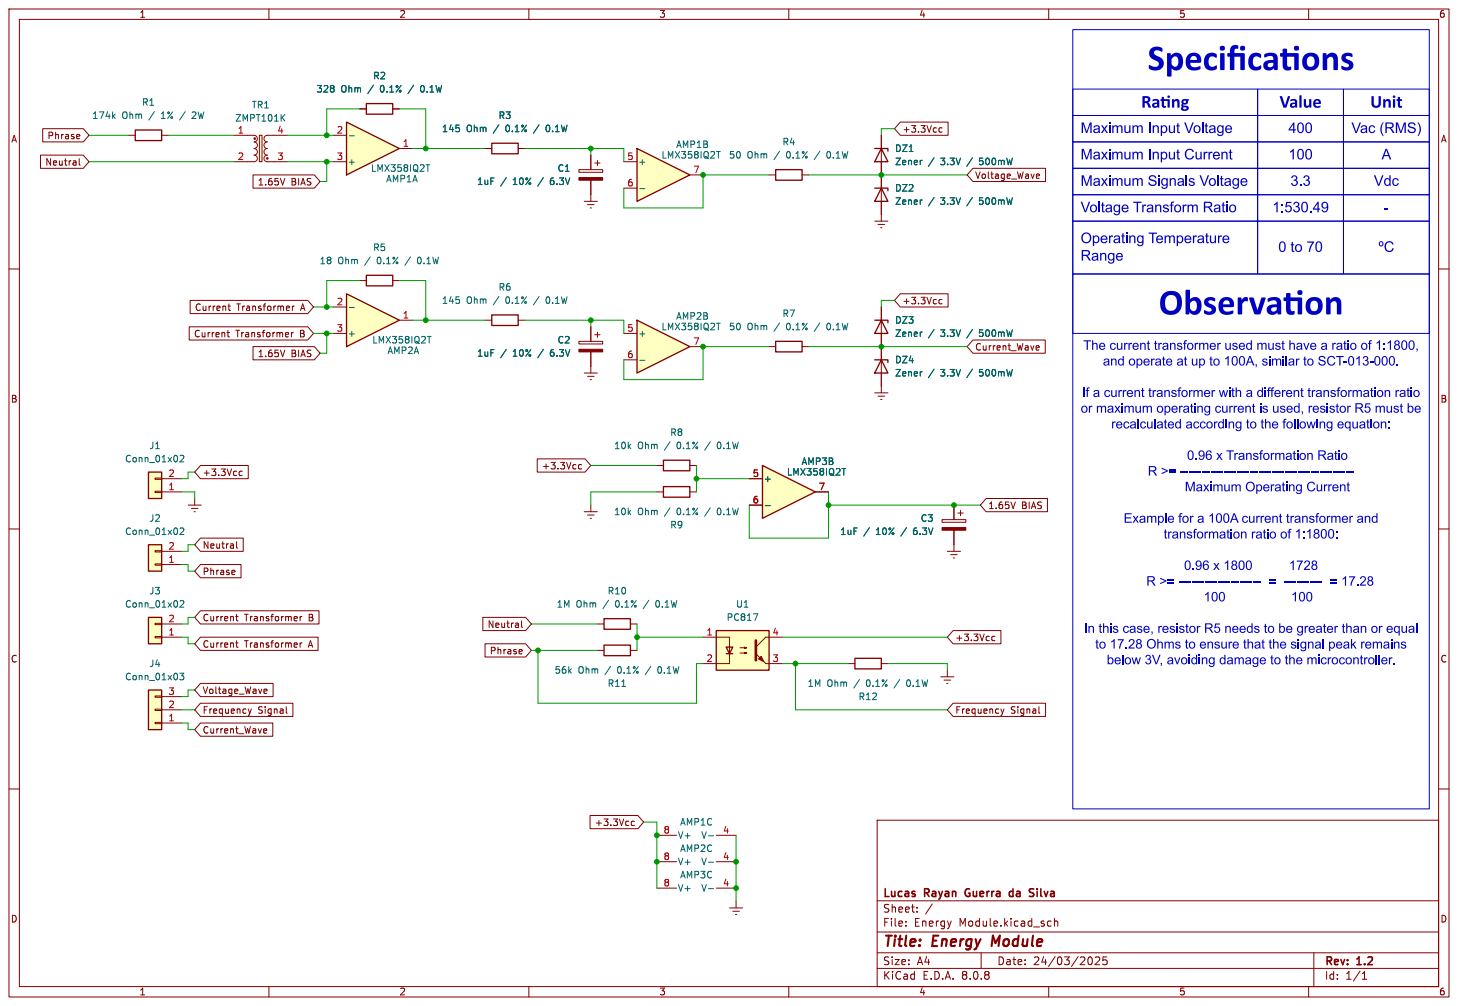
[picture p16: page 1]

The current transformer used must have a ratio of 1:1800,
and operate at up to 100A, similar to SCT-013-000.

If a current transformer with a different transformation ratio
or maximum operating current is used, resistor R5 must be
recalculated according to the following equation:

Example for a 100A current transformer and
transformation ratio of 1:1800:

In this case, resistor R5 needs to be greater than or equal
to 17.28 Ohms to ensure that the signal peak remains
below 3V, avoiding damage to the microcontroller.

Id: 1/1 Title: Energy Module

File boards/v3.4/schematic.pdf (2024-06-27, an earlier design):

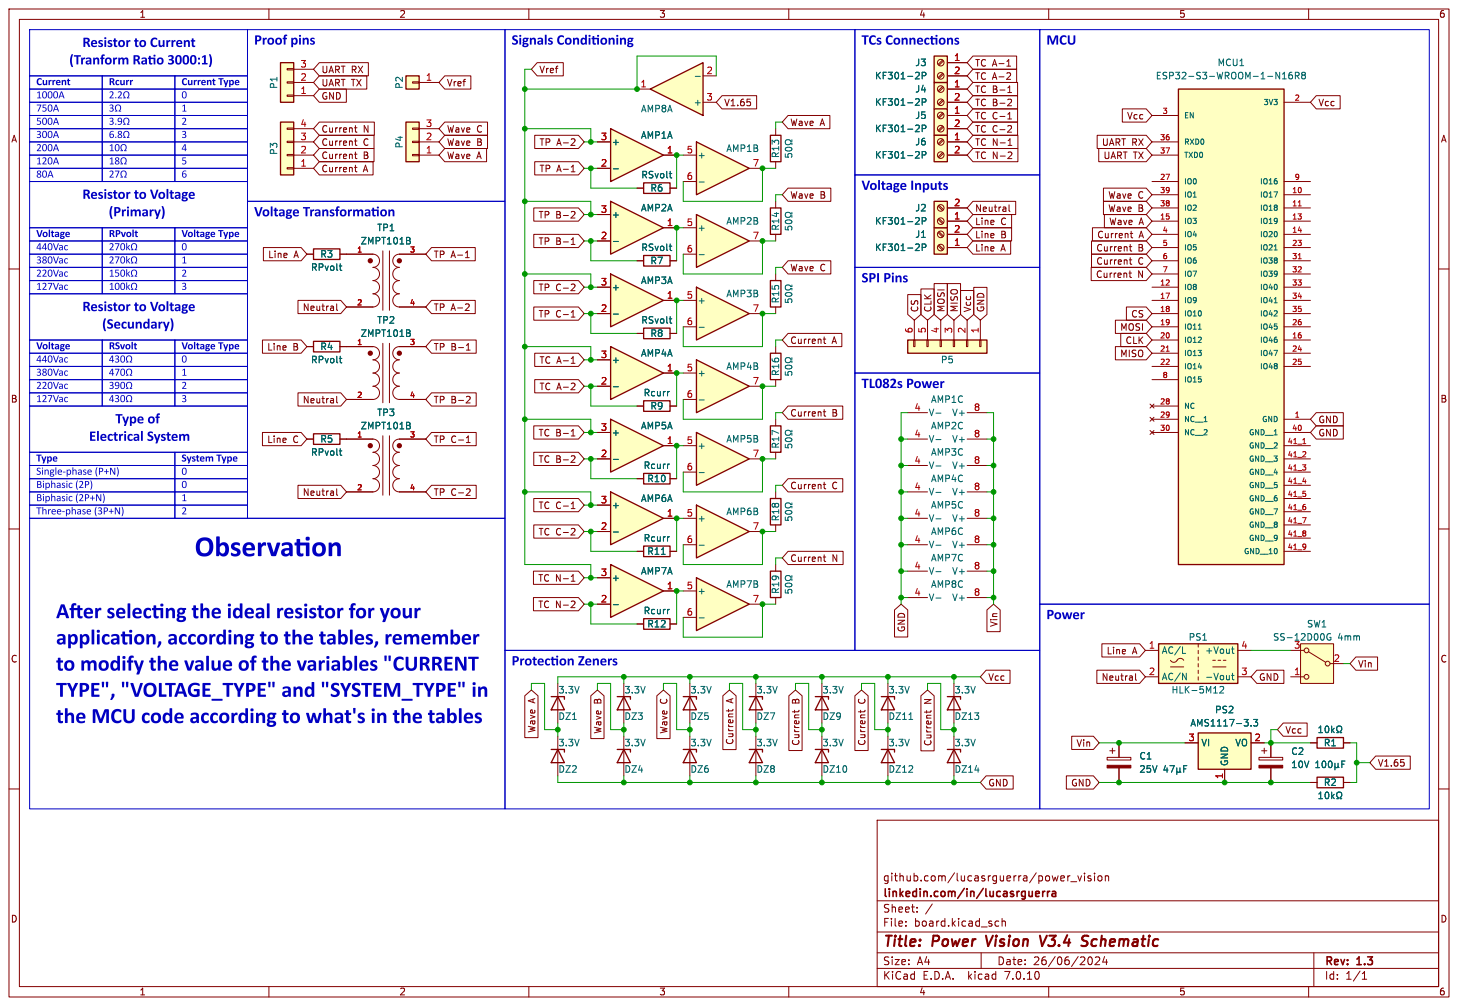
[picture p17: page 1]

TC C-1 TC N-2 TC C-2 Current N
Line C Wave B Wave A Wave C

Line A Neutral Current B Current A

Afterselectingtheidealresistorforyour
application,accordingto thetables,remember
to modifythevalueofthevariables"CURRENT
TYPE","VOLTAGE_TYPE" and"SYSTEM_TYPE" in
theMCUcodeaccordingto what'sinthetables

linkedin.com/in/lucasrguerra
File: board.kicad_sch Sheet: /
Id: 1/1 Title: Power Vision V3.4 Schematic

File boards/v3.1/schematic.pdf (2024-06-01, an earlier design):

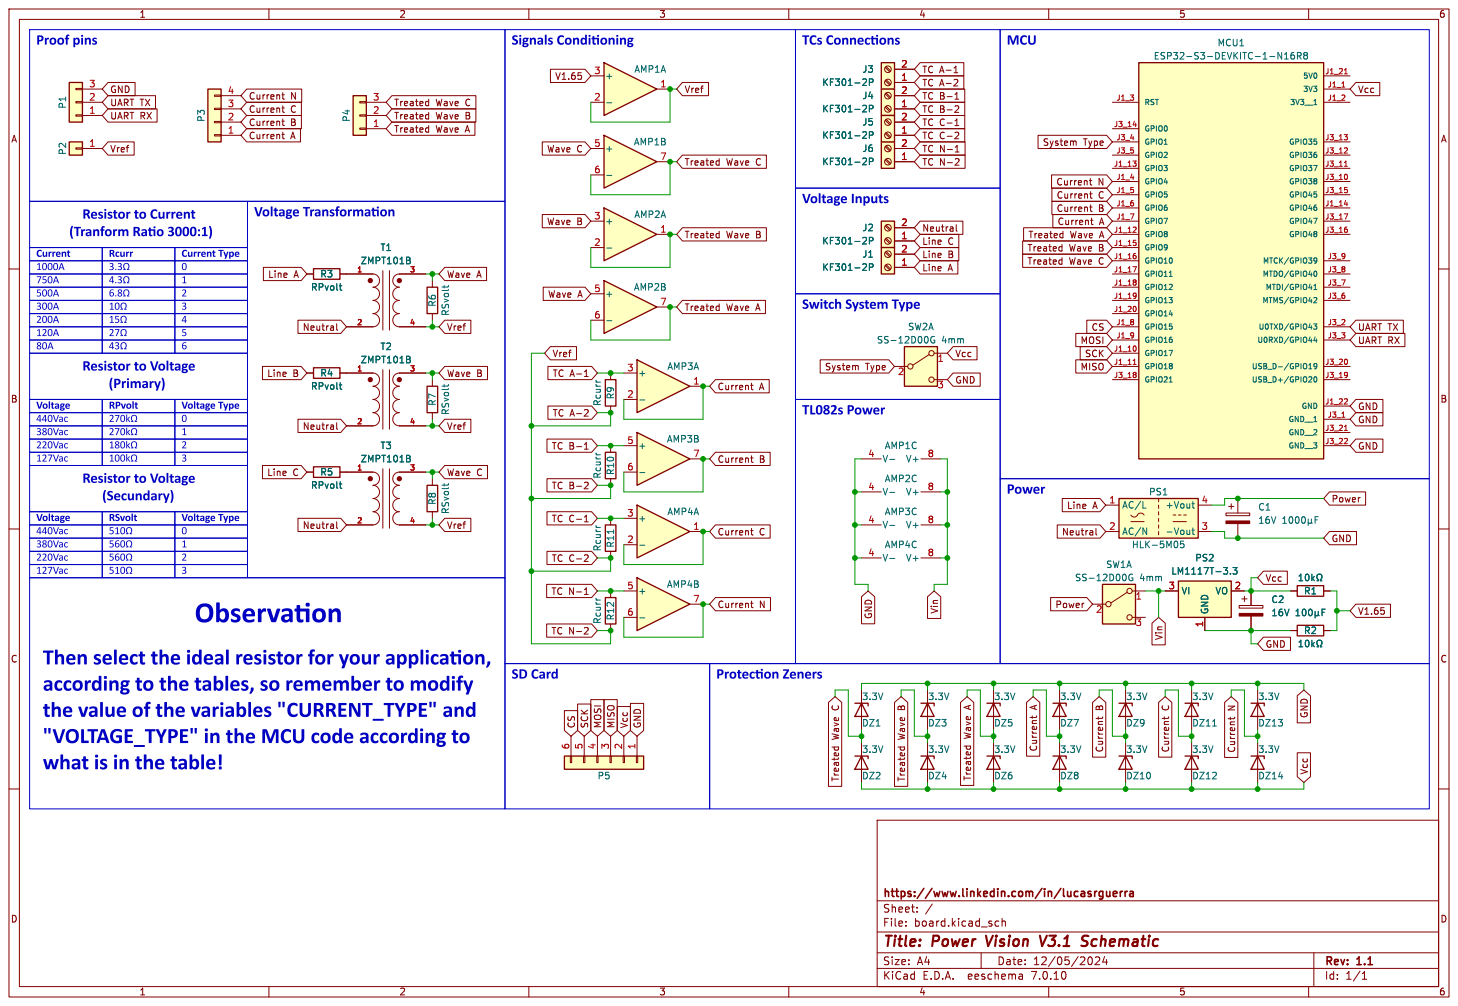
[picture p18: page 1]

1000A Proofpins
TC B-1 TC N-1 TC B-2 TC C-1 Current N

TC C-2 System Type Current B Current N

System Type Treated Wave A

Vcc Current A Wave B Wave C

2 T2 ZMPT101B
Neutral Neutral Neutral Line B

Power Neutral Line A GND

accordingto thetables,sorememberto modify
thevalueofthevariables"CURRENT_TYPE" and
"VOLTAGE_TYPE" intheMCUcodeaccordingto
whatisinthetable!

File: board.kicad_sch Sheet: / https://www.linkedin.com/in/lucasrguerra

Id: 1/1 Title: Power Vision V3.1 Schematic

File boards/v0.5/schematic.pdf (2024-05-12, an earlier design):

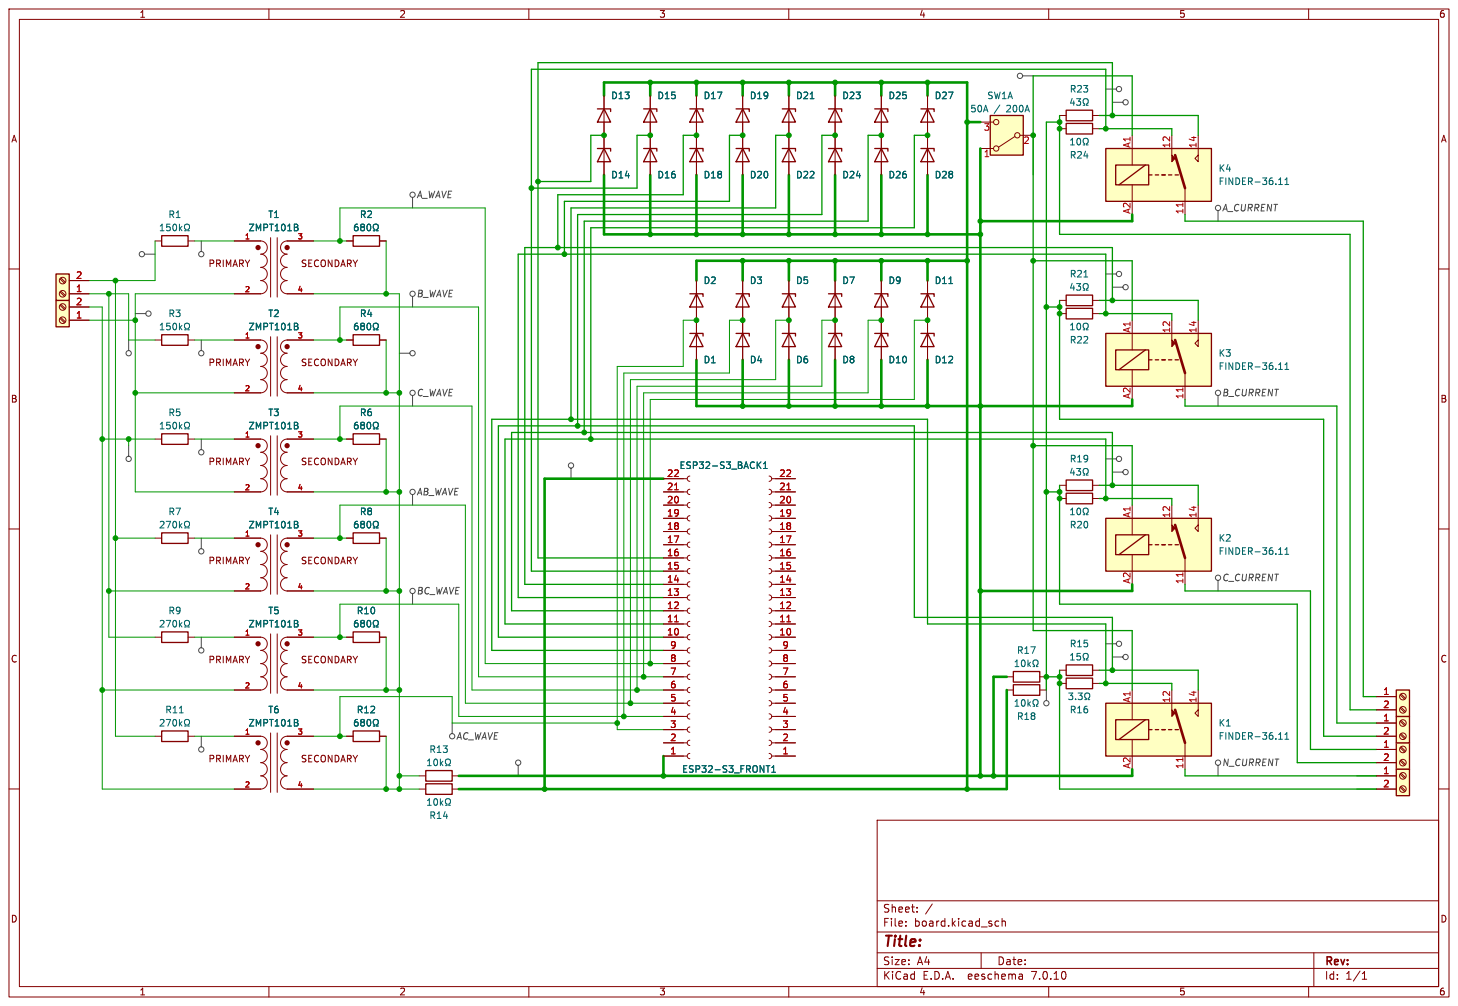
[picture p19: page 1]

Id: 1/1 Title: File: board.kicad_sch Sheet: / R10

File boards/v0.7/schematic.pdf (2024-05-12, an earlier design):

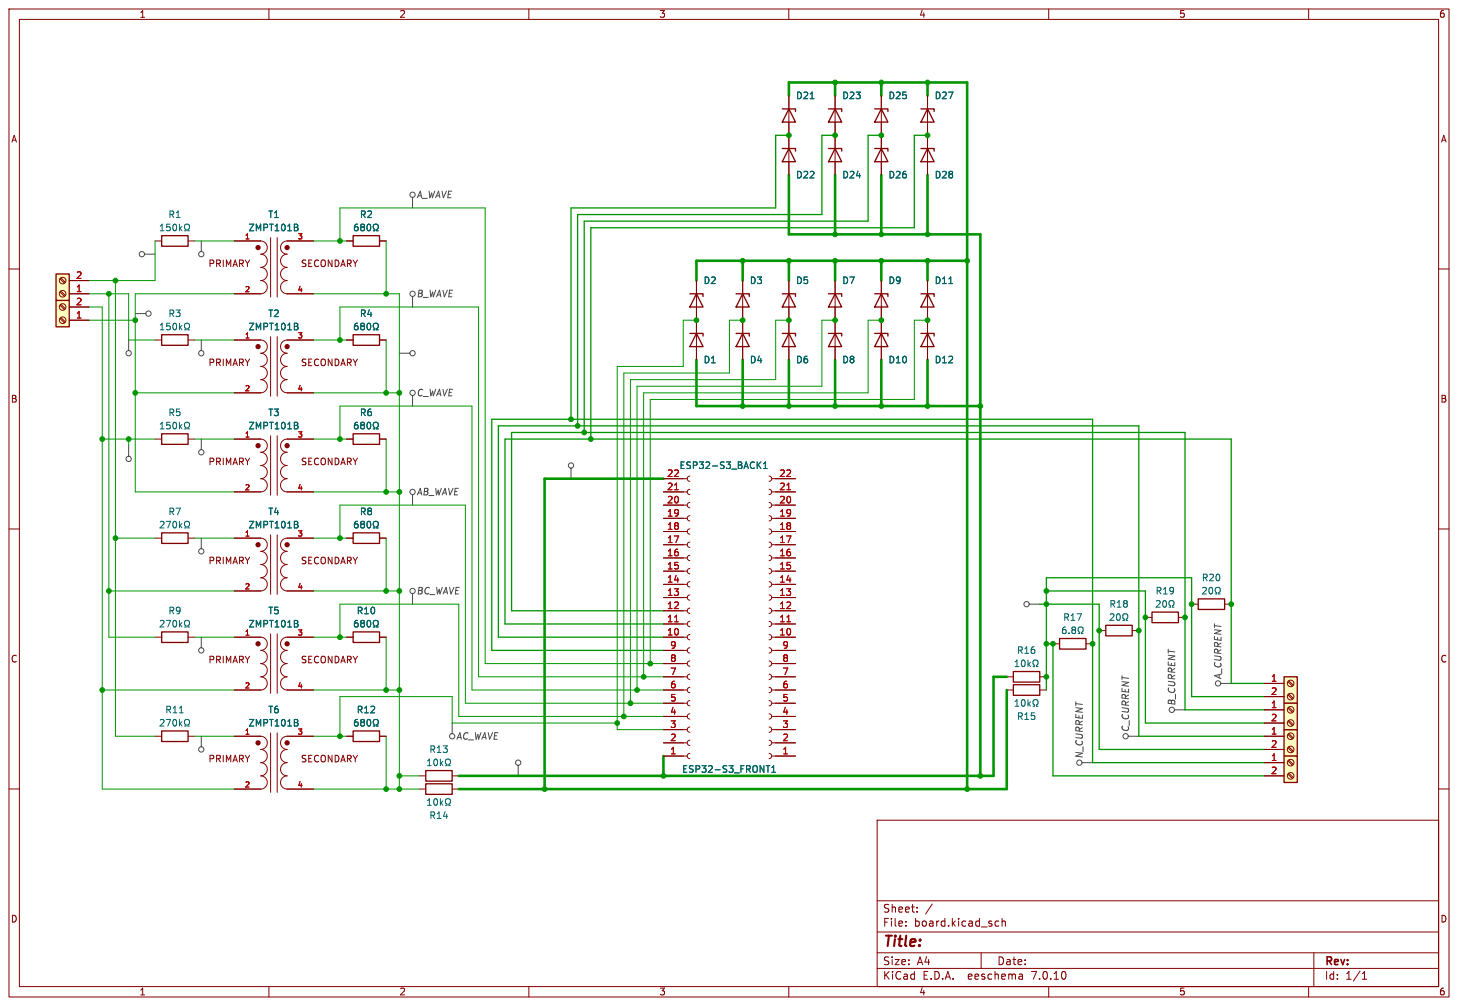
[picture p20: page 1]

Id: 1/1 Title: File: board.kicad_sch Sheet: /

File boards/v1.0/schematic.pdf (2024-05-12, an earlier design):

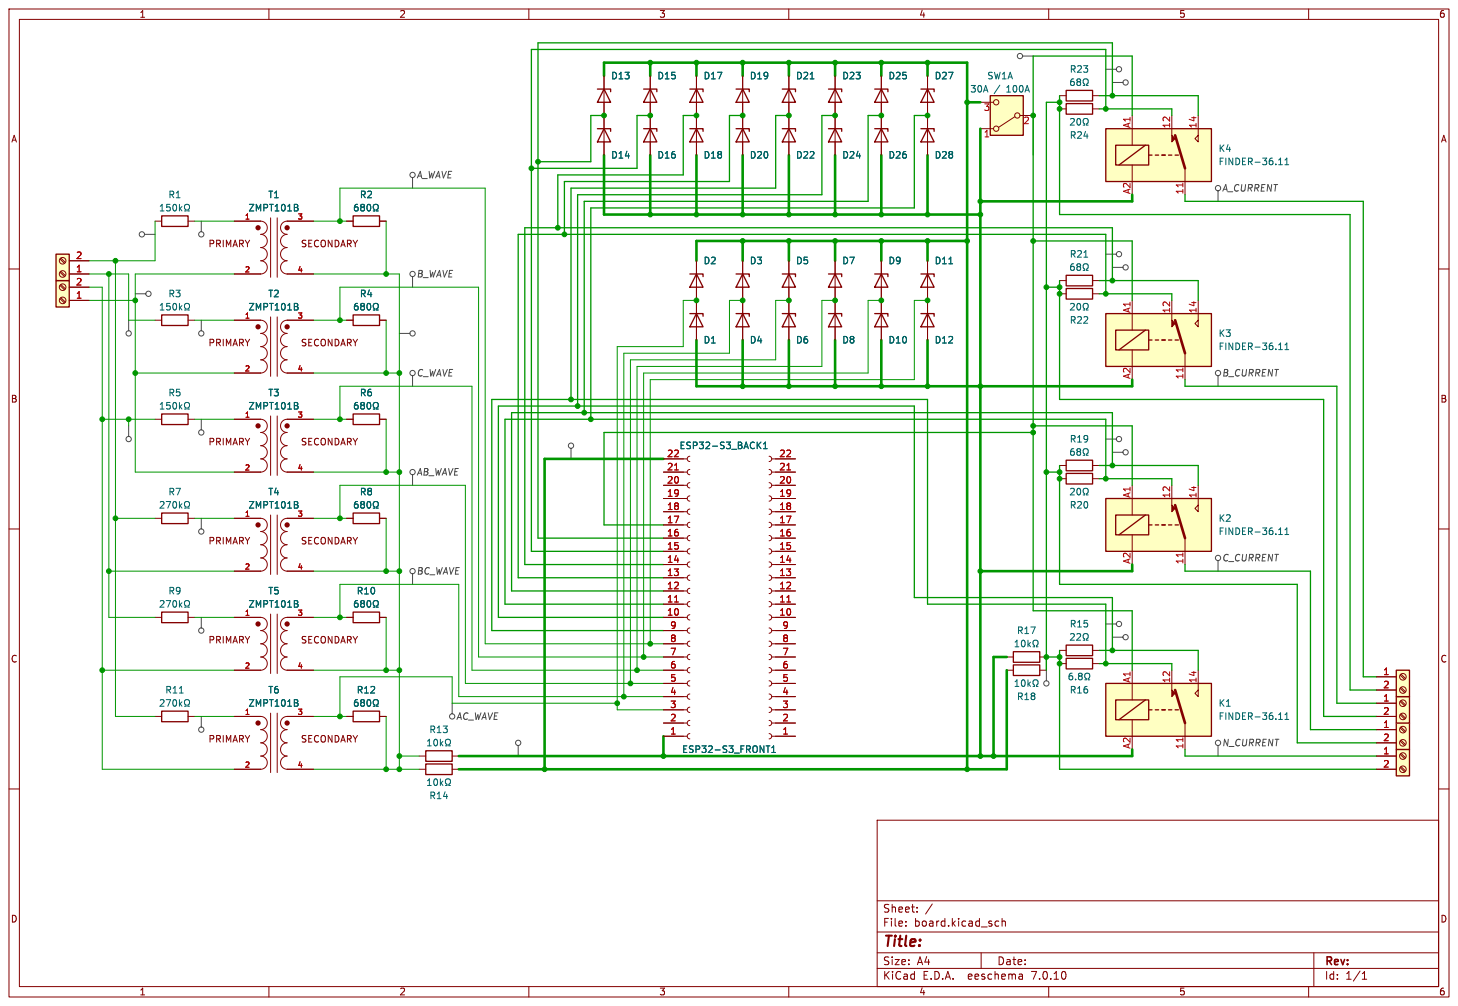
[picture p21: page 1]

Id: 1/1 Title: File: board.kicad_sch Sheet: / R11

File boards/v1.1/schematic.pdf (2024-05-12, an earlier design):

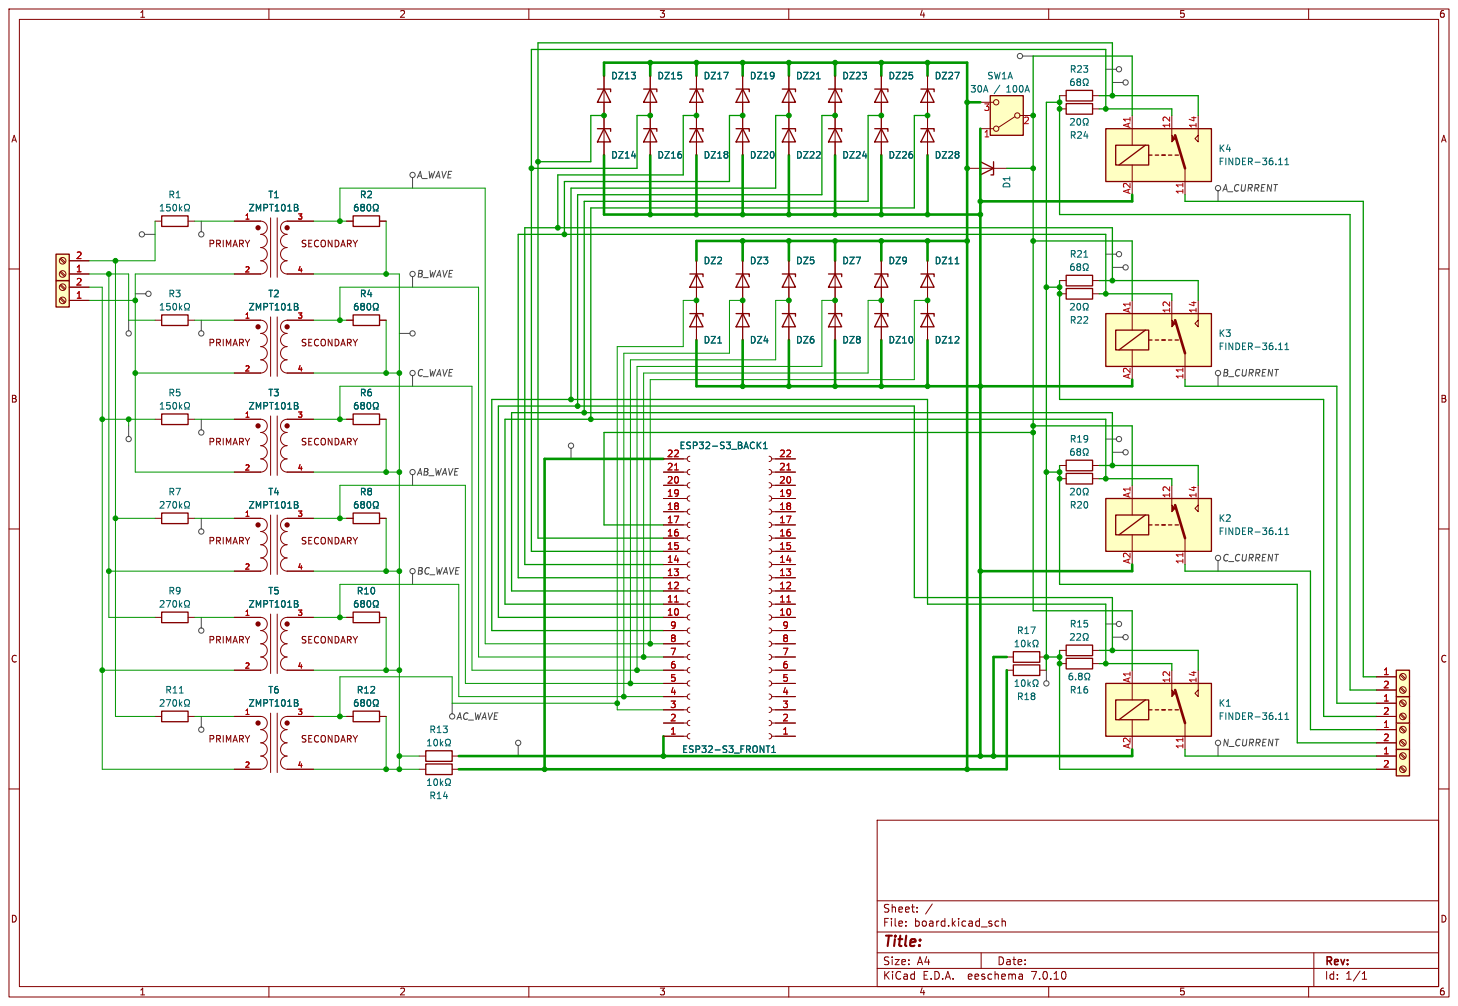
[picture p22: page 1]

Id: 1/1 Title: File: board.kicad_sch Sheet: /

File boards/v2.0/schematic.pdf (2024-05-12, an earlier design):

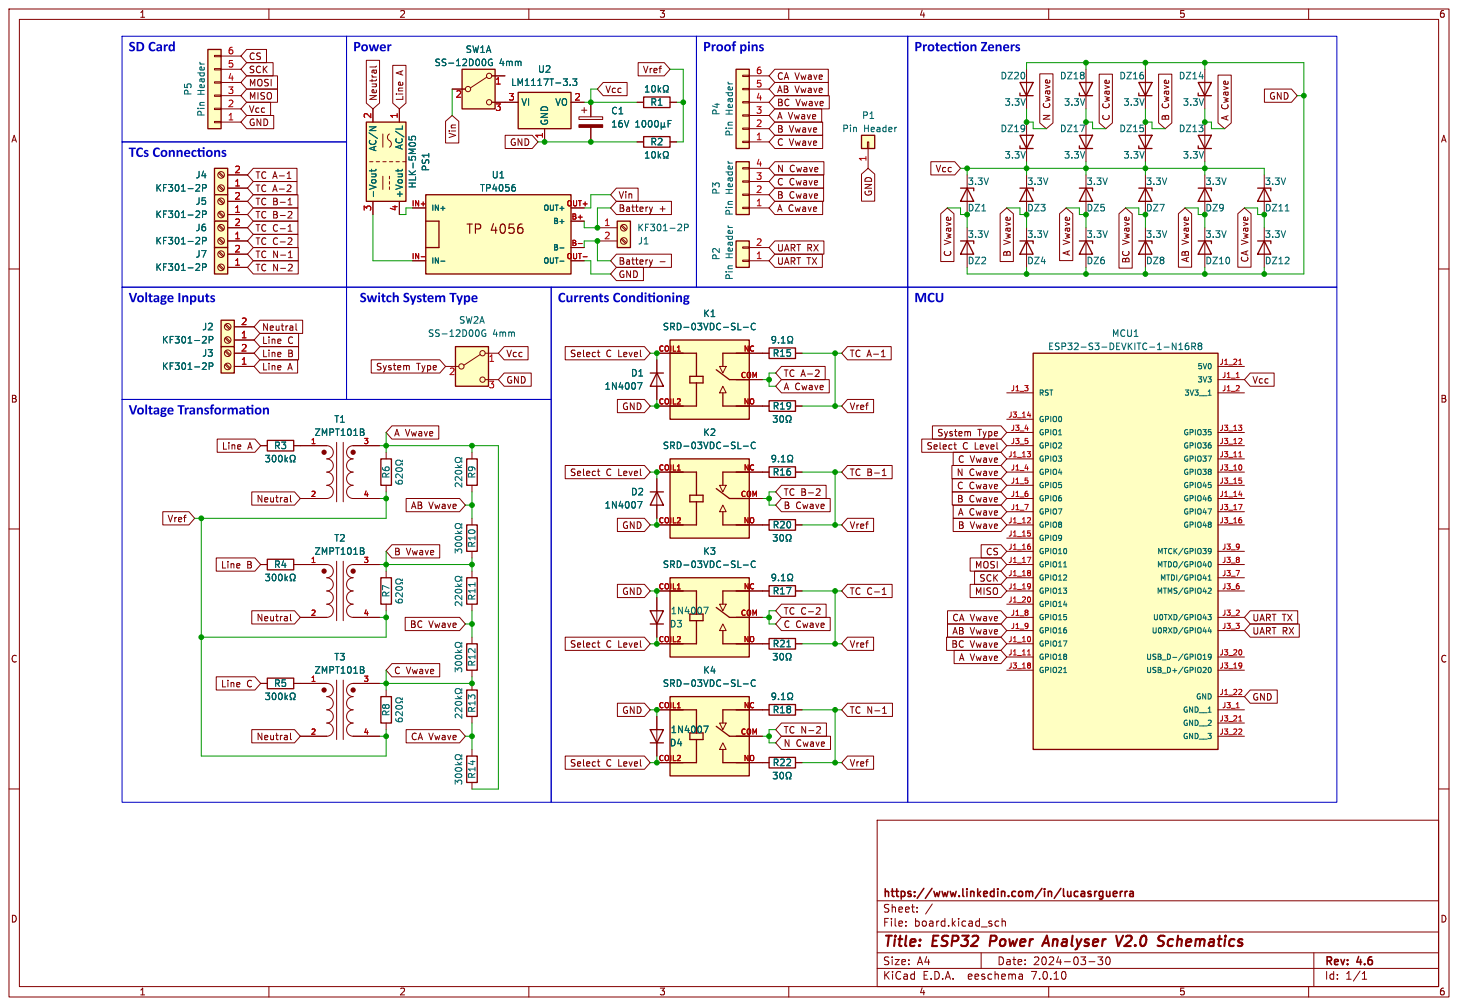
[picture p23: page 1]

CA Vwave AB Vwave ProtectionZeners

N Cwave BC Vwave A Vwave C Vwave B Vwave A Vwave

1 P1 Pin Header R13 þÿ220k© R14 þÿ300k©

2 P2 Pin Header R12 þÿ300k©
Select C Level Select C Level GND GND GND

4 T1 ZMPT101B
C Vwave AB Vwave B Vwave BC Vwave CA Vwave

Select C Level Select C Level GND

File: board.kicad_sch Sheet: / https://www.linkedin.com/in/lucasrguerra

Id: 1/1 Title: ESP32 Power Analyser V2.0 Schematics

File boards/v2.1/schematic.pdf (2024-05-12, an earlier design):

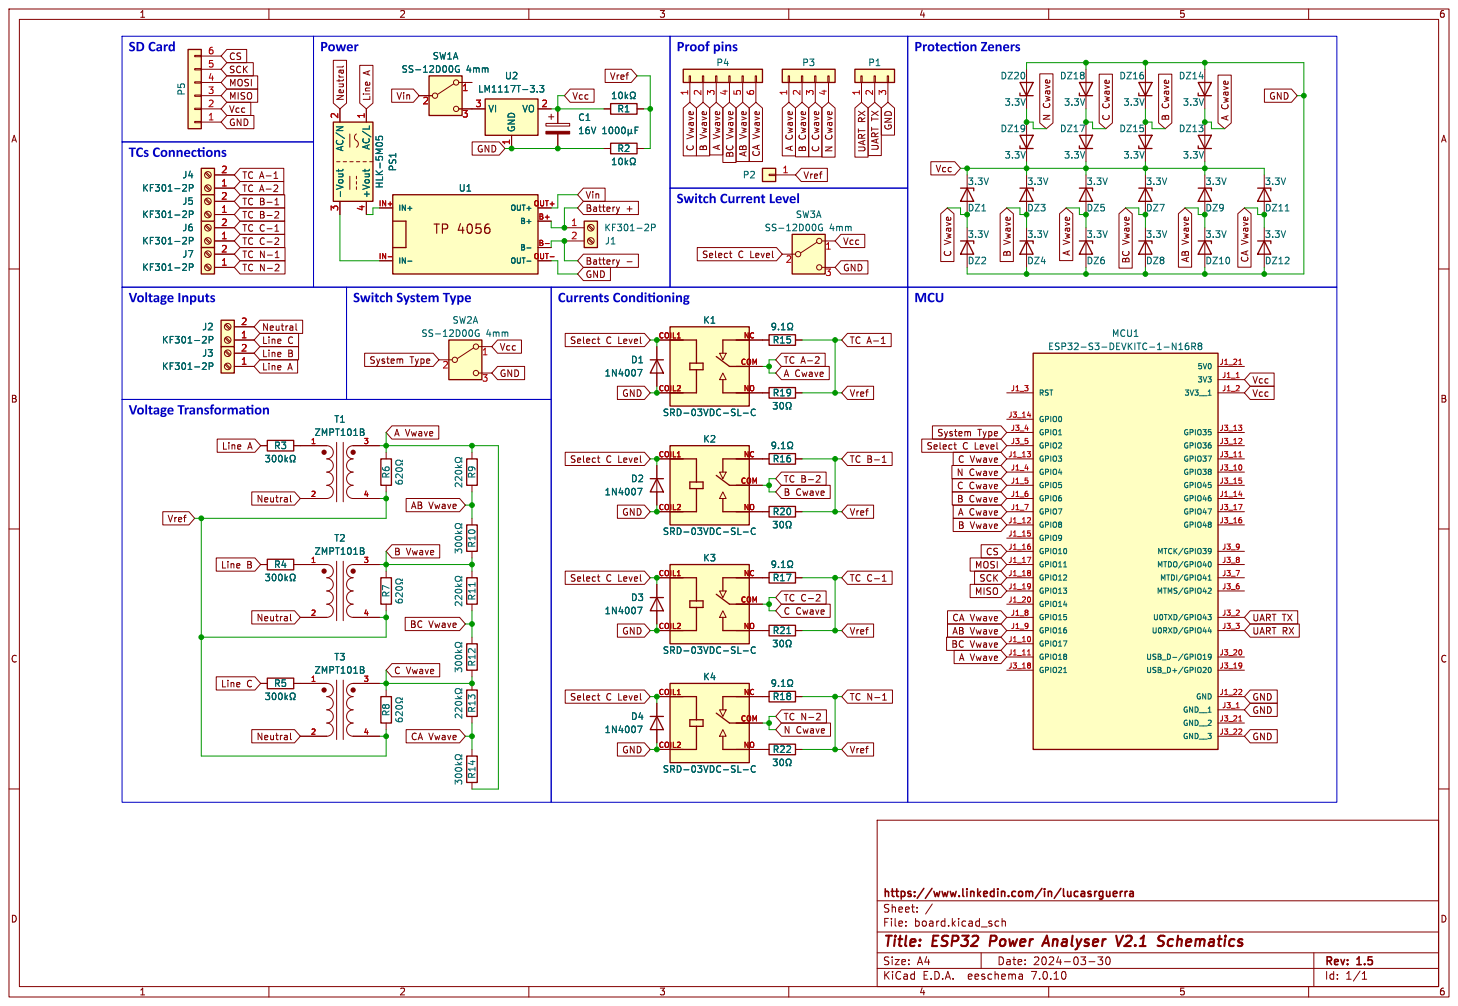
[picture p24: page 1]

A Cwave A Cwave Vref TC B-1 B Cwave TC B-2 Vref TC A-1 UART RX

System Type Select C Level GND

UART TX GND GND

File: board.kicad_sch Sheet: / https://www.linkedin.com/in/lucasrguerra R21

Id: 1/1 Title: ESP32 Power Analyser V2.1 Schematics

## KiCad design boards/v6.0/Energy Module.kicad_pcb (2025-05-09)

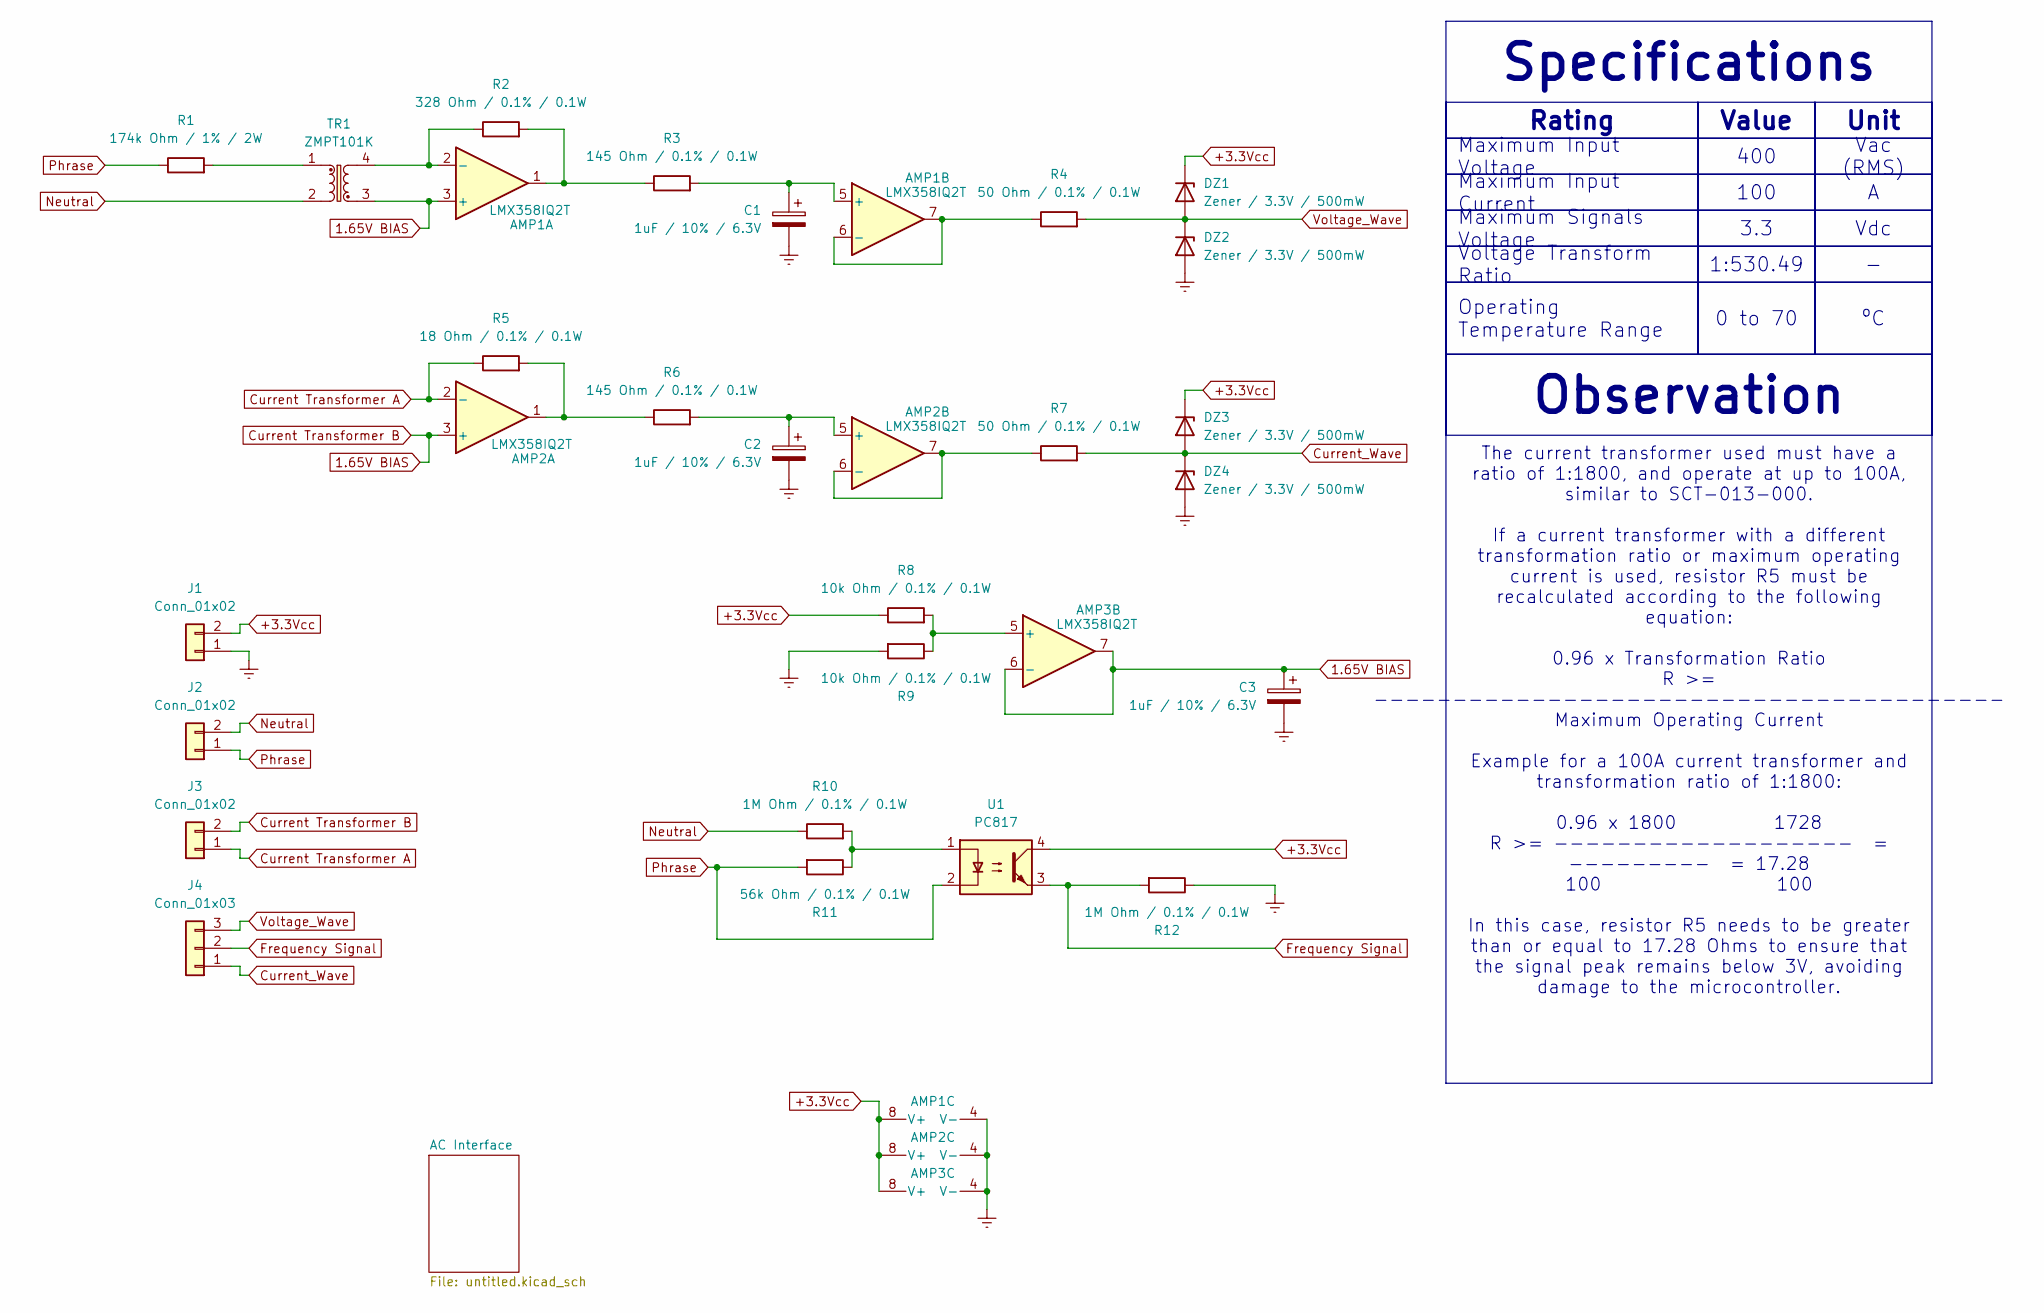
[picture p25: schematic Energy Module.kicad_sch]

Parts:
AMP1, AMP2, AMP3: LMX358IQ2T; DFN-8-1EP_6x5mm_P1.27mm_EP2x2mm
C1, C2, C3: 1uF / 10% / 6.3V; C_0201_0603Metric
DZ1, DZ2, DZ3, DZ4: Zener / 3.3V / 500mW; D_SOD-123
J1: Conn_01x02; PinHeader_1x02_P2.54mm_Vertical
J2, J3: Conn_01x02; PhoenixContact_MC_1,5_2-G-3.81_1x02_P3.81mm_Horizontal
J4: Conn_01x03; PinHeader_1x03_P2.54mm_Vertical
R1: 174k Ohm / 1% / 2W; R_2512_6332Metric
R2: 328 Ohm / 0.1% / 0.1W; R_0603_1608Metric
R3, R6: 145 Ohm / 0.1% / 0.1W; R_0603_1608Metric
R4, R7: 50 Ohm / 0.1% / 0.1W; R_0603_1608Metric
R5: 18 Ohm / 0.1% / 0.1W; R_0603_1608Metric
R8, R9: 10k Ohm / 0.1% / 0.1W; R_0603_1608Metric
R10, R12: 1M Ohm / 0.1% / 0.1W; R_0603_1608Metric
R11: 56k Ohm / 0.1% / 0.1W; R_0603_1608Metric
TR1: ZMPT101K; Transformer_Zeming_ZMPT101K
U1: PC817; DIP-4_W7.62mm_SMDSocket_SmallPads

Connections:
1.65V BIAS: AMP1.3 (+), AMP2.3 (+), AMP3.6 (-), AMP3.7, C3.1, J3.2, TR1.3
+3.3Vcc: AMP1.8 (V+), AMP2.8 (V+), AMP3.8 (V+), DZ1.1 (K), DZ3.1 (K), J1.2, R8.1, U1.4
Current Transformer A: AMP2.2 (-), J3.1, R5.1
Current_Wave: DZ3.2 (A), DZ4.1 (K), J4.1, R7.2
Earth: AMP1.4 (V-), AMP2.4 (V-), AMP3.4 (V-), C1.2, C2.2, C3.2, DZ2.2 (A), DZ4.2 (A), J1.1, R9.2, R12.1
Frequency Signal: J4.2, R12.2, U1.3
unnamed: AMP1.1, R2.2, R3.1
unnamed: AMP1.2 (-), R2.1, TR1.4
unnamed: AMP1.5 (+), C1.1, R3.2
unnamed: AMP1.6 (-), AMP1.7, R4.1
unnamed: AMP2.1, R5.2, R6.1
unnamed: AMP2.5 (+), C2.1, R6.2
unnamed: AMP2.6 (-), AMP2.7, R7.1
unnamed: AMP3.5 (+), R8.2, R9.1
unnamed: R1.2, TR1.1
unnamed: R10.2, R11.1, U1.1
Neutral: J2.2, R10.1, TR1.2
Phrase: J2.1, R1.1, R11.2, U1.2
Voltage_Wave: DZ1.2 (A), DZ2.1 (K), J4.3, R4.2

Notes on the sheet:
Value
Maximum Signals Voltage
1:530.49
Operating Temperature Range
The current transformer used must have a ratio of 1:1800, and operate at up to 100A, similar to SCT-013-000. If a current transformer with a different transformation ratio or maximum operating current is used, resistor R5 must be recalculated according to the following equation: 0.96 x Transformati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
Observation
Maximum Input Voltage
100
Voltage Transform Ratio
Unit
Vac (RMS)
3.3
0 to 70
400
Rating
Specifications
Vdc
Maximum Input Current

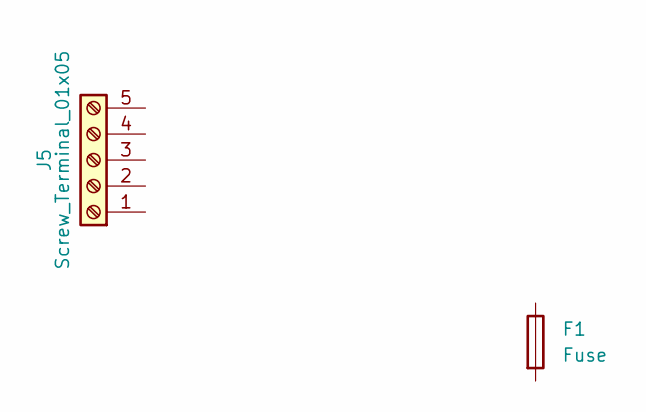
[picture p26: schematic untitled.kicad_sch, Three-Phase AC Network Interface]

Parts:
F1: Fuse; Fuseholder_Clip-5x20mm_Keystone_3512_Inline_P23.62x7.27mm_D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
J5: Screw_Terminal_01x05; TerminalBlock_bornier-5_P5.08mm

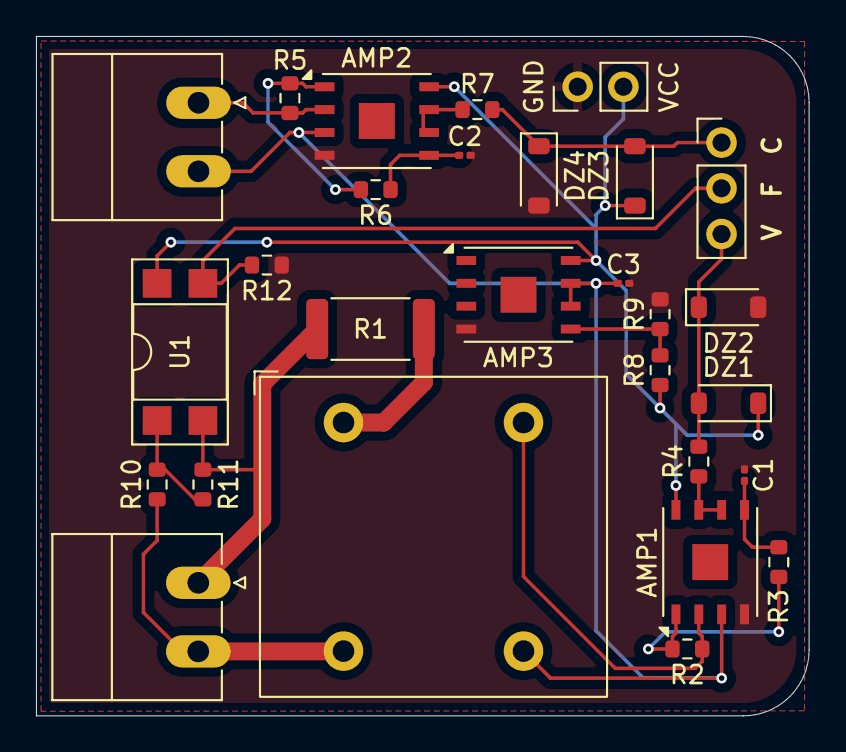
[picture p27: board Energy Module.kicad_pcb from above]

Board: 2 copper layers, 42.9 x 37.7 mm, 28 parts (0 on the bottom side), 19 nets.

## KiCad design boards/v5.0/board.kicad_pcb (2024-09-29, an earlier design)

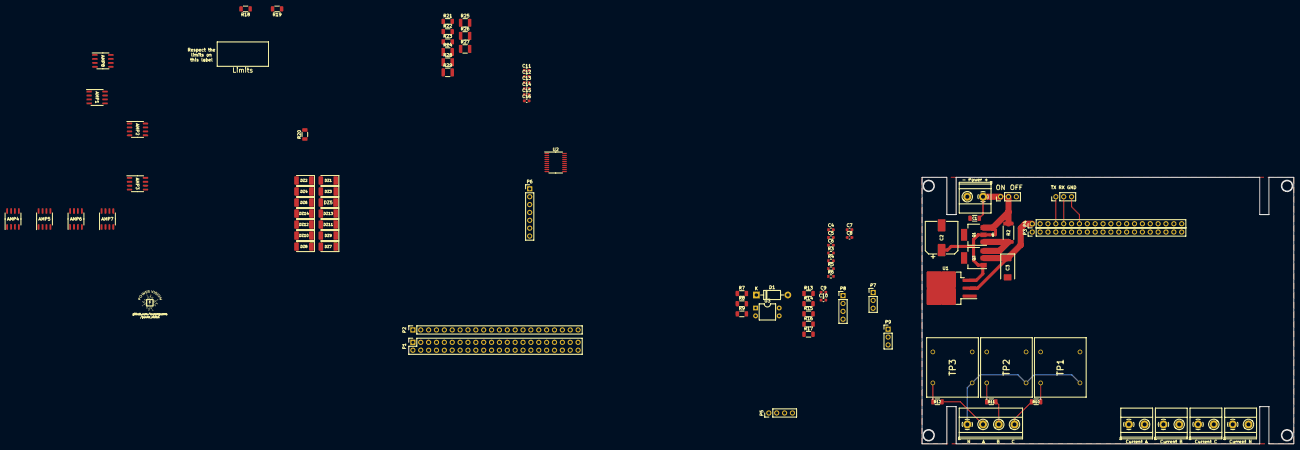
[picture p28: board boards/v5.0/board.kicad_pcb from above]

Board: 2 copper layers, 120.0 x 86.0 mm, 93 parts (0 on the bottom side), 68 nets.

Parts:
AMP1, AMP2, AMP3, AMP4, AMP5, AMP6, AMP7, AMP8: TL082; SO-8_3.9x4.9mm_P1.27mm
C1: 100V 0.1µF; C_1206_3216Metric
C2: 50V 100µF; CP_Elec_10x10
C3: 10V 47µF; CP_EIA-7343-31_Kemet-D
C4, C5, C6, C7, C8: 10V 0.1µF; C_0603_1608Metric
C9, C10, C11, C12, C13, C14, C15, C16: 10V 0.1uF; C_0603_1608Metric
D1: 1N4007; D_DO-41_SOD81_P10.16mm_Horizontal
DZ1, DZ2, DZ3, DZ4, DZ5, DZ6, DZ7, DZ8, DZ9, DZ10, DZ11, DZ12, DZ13, DZ14: 3.3V; D_MELF
J1, J3, J4, J5, J6: Screw_Terminal_01x02; TerminalBlock_Phoenix_MKDS-1,5-2-5.08_1x02_P5.08mm_Horizont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
J2: Screw_Terminal_01x04; TerminalBlock_Phoenix_MKDS-1,5-4-5.08_1x04_P5.08mm_Horizont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
P1: Pin Socket 2.54mm 02x22; PinSocket_2x22_P2.54mm_Vertical
P2: Pin Socket 2.54mm 01x22; PinSocket_1x22_P2.54mm_Vertical
P3, P4: Conn_01x20; PinHeader_1x20_P2.54mm_Vertical
P5, P8: Pin Header; PinHeader_1x04_P2.54mm_Vertical
P6: Conn_01x07; PinHeader_1x07_P2.54mm_Vertical
P7, P9, P10: Pin Header; PinHeader_1x03_P2.54mm_Vertical
Q1, Q2: FZT948TA; SOT-223
R1: 2Ω; R_0603_1608Metric
R2: 0.2Ω; R_2512_6332Metric
R3, R4, R5, R6: 1kΩ; R_0603_1608Metric
R7, R13, R14: 10kΩ; R_1206_3216Metric
R8, R9: 1MΩ; R_1206_3216Metric
R10, R11, R12: RVolt; R_1206_3216Metric
R15, R17, R19, R21, R23: 50Ω; R_1206_3216Metric
R16, R18, R20: 430Ω; R_1206_3216Metric
R22: Rcurr; R_1206_3216Metric
R24, R26, R28: Rcurr; R_1210_3225Metric
R25, R27, R29: 50Ω; R_1210_3225Metric
SW1: SS-12D00G 4mm; PinHeader_1x03_P2.54mm_Vertical
TP1, TP2, TP3: ZMPT101B; XFMR_ZMPT101B
U1: LD1086#50; TO-263-3_TabPin2
U2: TXS0108EPW; TSSOP-20_4.4x6.5mm_P0.65mm
U3: PC817; DIP-4_W7.62mm

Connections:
/Microcomputer/3.3V: C4.1, C6.1, C7.1, DZ2.1 (K), DZ3.1 (K), DZ5.1 (K), DZ7.1 (K), DZ9.1 (K), DZ11.1 (K), DZ13.1 (K), P1.1, P1.2, P1.43, P1.44, P3.1, P3.9, R5.2, R6.1, R13.1, U2.19 (VCCB), U3.4
/Microcomputer/5V: AMP1.8 (V+), AMP2.8 (V+), AMP3.8 (V+), AMP4.8 (V+), AMP5.8 (V+), AMP6.8 (V+), AMP7.8 (V+), AMP8.8 (V+), C3.1, C5.1, C8.1, P1.21, P1.24, P4.1, P4.2, P5.3, P6.6, Q2.2 (C), R3.2, R4.1, U1.2 (OUT), U2.2 (VCCA), U2.10 (OE)
/Microcomputer/I2C SCL_1: P3.3, P5.2
/Microcomputer/I2C SDA_1: P3.2, P5.1
/Microcomputer/RX_0: P4.5, P10.2
/Microcomputer/RX_3: P3.14, U2.1 (A1)
/Microcomputer/SPI CLK: P3.12, P6.3
/Microcomputer/SPI CS: P4.12, P6.2
/Microcomputer/SPI DC: P4.13, P6.1
/Microcomputer/SPI MISO: P3.11, P6.4
/Microcomputer/SPI MOSI: P3.10, P6.5
/Microcomputer/TX_0: P4.4, P10.1
/Microcomputer/TX_3: P4.14, U2.3 (A2)
/Microcontroller/ADC1_0: DZ1.1 (K), DZ2.2 (A), P2.4, P7.1, R17.2
/Microcontroller/ADC1_1: DZ3.2 (A), DZ4.1 (K), P2.5, P7.2, R19.2
/Microcontroller/ADC1_2: DZ5.2 (A), DZ6.1 (K), P1.13, P7.3, R21.2
/Microcontroller/ADC1_3: DZ7.2 (A), DZ8.1 (K), P1.4, P1.32, P8.1, R23.2
/Microcontroller/ADC1_4: DZ11.2 (A), DZ12.1 (K), P1.5, P8.3, R27.2
/Microcontroller/ADC1_5: DZ9.2 (A), DZ10.1 (K), P1.6, P8.2, R25.2
/Microcontroller/ADC1_6: DZ13.2 (A), DZ14.1 (K), P1.7, P8.4, R29.2
/Microcontroller/GPIO_17: P1.8, R9.1, U3.3
/Microcontroller/I2C SCL: R4.2, U2.9 (A8)
/Microcontroller/I2C SDA: R3.1, U2.8 (A7)
/Microcontroller/I2C_SCL: P1.15, P1.30, R6.2, U2.12 (B8)
/Microcontroller/I2C_SDA: P1.12, P1.33, R5.1, U2.13 (B7)
/Microcontroller/RESET: P1.3, P1.42
/Microcontroller/RX_0: P2.3, P9.2
/Microcontroller/RX_1: P1.11, P1.34, U2.18 (B2)
/Microcontroller/TX_0: P2.2, P9.1
/Microcontroller/TX_1: P1.10, P1.35, U2.20 (B1)
/Power/IN+: C1.1, J1.1, SW1.1 (C)
/Signals Acquisition/Line A: D1.1 (K), J2.4, R10.2
/Signals Acquisition/Line B: J2.3, R11.2
/Signals Acquisition/Line C: J2.2, R12.2
/Signals Acquisition/Neutral: J2.1, R7.2, TP1.2, TP2.2, TP3.2, U3.1
/Signals Acquisition/PT A-1: AMP1.3 (+), AMP2.3 (+), AMP3.3 (+), AMP4.3 (+), AMP5.3 (+), AMP6.3 (+), AMP7.3 (+), C9.1, J3.1, J4.2, J5.2, J6.2, R15.1, TP1.3, TP2.3, TP3.3
/Signals Acquisition/PT A-2: AMP1.2 (-), R16.1, TP1.4
/Signals Acquisition/PT B-2: AMP2.2 (-), R18.1, TP2.4
/Signals Acquisition/PT C-2: AMP3.2 (-), R20.1, TP3.4
/Signals Conditioning/CT A-2: AMP4.2 (-), J3.2, R22.2
/Signals Conditioning/CT B-2: AMP5.2 (-), J4.1, R24.2
/Signals Conditioning/CT C-2: AMP6.2 (-), J5.1, R26.2
/Signals Conditioning/CT N-2: AMP7.2 (-), J6.1, R28.2
Earth: AMP1.4 (V-), AMP2.4 (V-), AMP3.4 (V-), AMP4.4 (V-), AMP5.4 (V-), AMP6.4 (V-), AMP7.4 (V-), AMP8.4 (V-), C1.2, C2.2, C3.2, C4.2, C5.2, C6.2, C7.2, C8.2, C9.2, C10.2, C11.2, C12.2, C13.2, C14.2, C15.2, C16.2, DZ1.2 (A), DZ4.2 (A), DZ6.2 (A), DZ8.2 (A), DZ10.2 (A), DZ12.2 (A), DZ14.2 (A), J1.2, P1.22, P1.23, P2.21, P2.22, P3.5, P3.13, P3.20, P4.3, P4.7, P4.10, P4.15, P4.17, P5.4, P6.7, P9.3, P10.3, R9.2, R14.1, SW1.3 (A), U1.1 (ADJ/GND), U2.11 (GND)
unnamed: AMP1.1, AMP1.5 (+), C10.1, R16.2
unnamed: AMP1.6 (-), AMP1.7, R17.1
unnamed: AMP2.1, AMP2.5 (+), C11.1, R18.2
unnamed: AMP2.6 (-), AMP2.7, R19.1
unnamed: AMP3.1, AMP3.5 (+), C12.1, R20.2
unnamed: AMP3.6 (-), AMP3.7, R21.1
unnamed: AMP4.1, AMP4.5 (+), C13.1, R22.1
unnamed: AMP4.6 (-), AMP4.7, R23.1
unnamed: AMP5.1, AMP5.5 (+), C14.1, R24.1
unnamed: AMP5.6 (-), AMP5.7, R25.1
unnamed: AMP6.1, AMP6.5 (+), C15.1, R26.1
unnamed: AMP6.6 (-), AMP6.7, R27.1
unnamed: AMP7.1, AMP7.5 (+), C16.1, R28.1
unnamed: AMP7.6 (-), AMP7.7, R29.1
unnamed: AMP8.3 (+), R13.2, R14.2
unnamed: AMP8.1, AMP8.2 (-), R15.2
unnamed: D1.2 (A), R8.2
unnamed: Q1.1 (B), Q2.3 (E), R2.2
unnamed: C2.1, Q1.2 (C), Q2.1 (B), R1.2, U1.3 (IN)
unnamed: Q1.3 (E), R1.1, R2.1, SW1.2 (B)
unnamed: R7.1, R8.1, U3.2
unnamed: R10.1, TP1.1
unnamed: R11.1, TP2.1
unnamed: R12.1, TP3.1

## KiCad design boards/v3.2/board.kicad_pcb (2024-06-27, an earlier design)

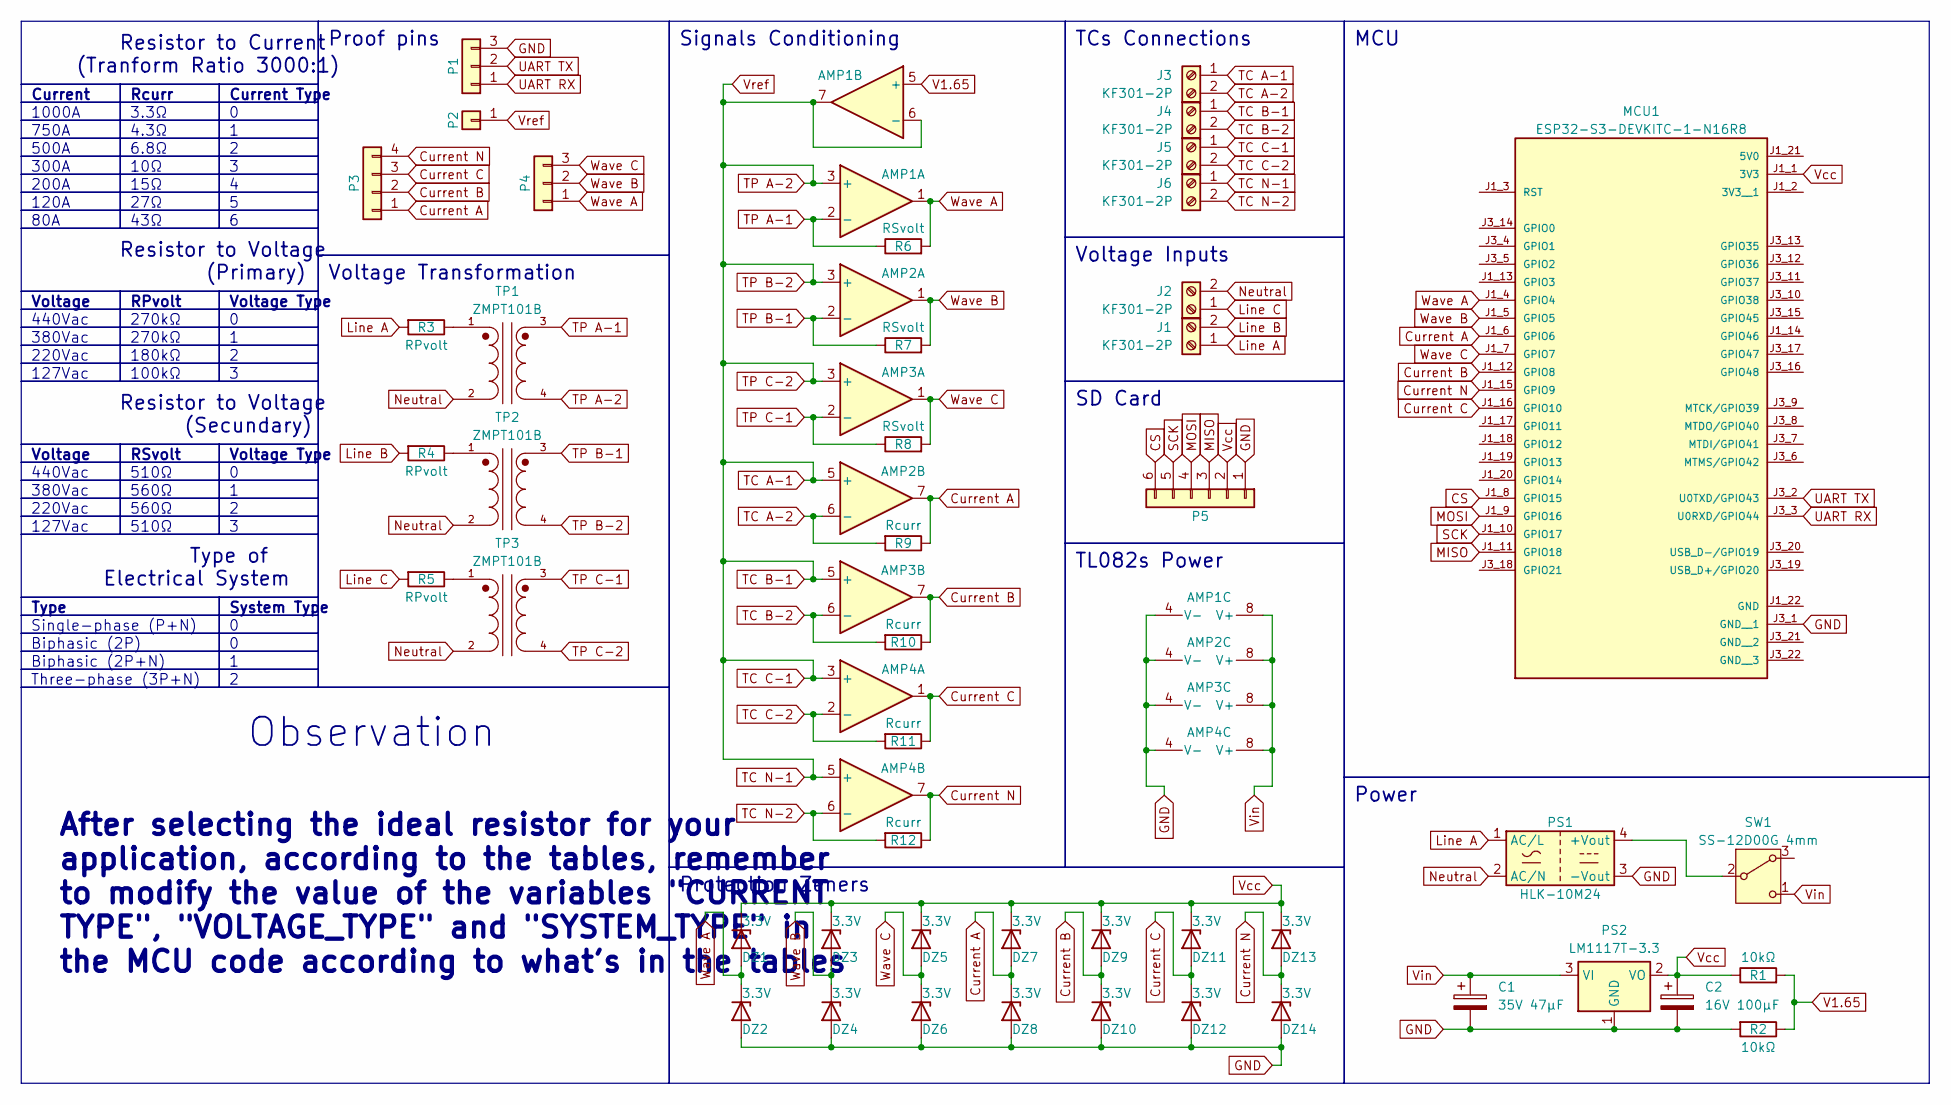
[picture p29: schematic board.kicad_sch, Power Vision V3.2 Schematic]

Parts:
AMP1, AMP2, AMP3, AMP4: TL082; DIP-8_W7.62mm_Socket
C1: 35V 47µF; CP_Radial_Tantal_D6.0mm_P2.50mm
C2: 16V 100µF; CP_Radial_Tantal_D5.0mm_P2.50mm
DZ1, DZ2, DZ3, DZ4, DZ5, DZ6, DZ7, DZ8, DZ9, DZ10, DZ11, DZ12, DZ13, DZ14: 3.3V; D_DO-34_SOD68_P7.62mm_Horizontal
J1, J2, J3, J4, J5, J6: KF301-2P; TerminalBlock_bornier-2_P5.08mm
MCU1: ESP32-S3-DEVKITC-1-N16R8; XCVR_ESP32-S3-DEVKITC-1-N8R2; PARTREV V1
P1, P4: Pin Header; PinHeader_1x03_P2.54mm_Vertical
P2: Pin Header; PinHeader_1x01_P2.54mm_Vertical
P3: Pin Header; PinHeader_1x04_P2.54mm_Vertical
P5: Pin Header; PinHeader_1x06_P2.54mm_Vertical
PS1: HLK-10M24; Converter_ACDC_HiLink_HLK-5Mxx
PS2: LM1117T-3.3; TO-220-3_Vertical
R1, R2: 10kΩ; R_Axial_DIN0207_L6.3mm_D2.5mm_P10.16mm_Horizontal
R3, R4, R5: RPvolt; R_Axial_DIN0207_L6.3mm_D2.5mm_P10.16mm_Horizontal
R6, R7, R8: RSvolt; R_Axial_DIN0207_L6.3mm_D2.5mm_P10.16mm_Horizontal
R9, R10, R11, R12: Rcurr; R_Axial_DIN0207_L6.3mm_D2.5mm_P10.16mm_Horizontal
SW1: SS-12D00G 4mm; PinHeader_1x03_P2.54mm_Vertical
TP1, TP2, TP3: ZMPT101B; XFMR_ZMPT101B; PARTREV NA

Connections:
CS: MCU1.J1_8 (GPIO15), P5.6
Current A: AMP2.7, DZ7.2 (A), DZ8.1 (K), MCU1.J1_6 (GPIO6), P3.1, R9.1
Current B: AMP3.7, DZ9.2 (A), DZ10.1 (K), MCU1.J1_12 (GPIO8), P3.2, R10.1
Current C: AMP4.1, DZ11.2 (A), DZ12.1 (K), MCU1.J1_16 (GPIO10), P3.3, R11.1
Current N: AMP4.7, DZ13.2 (A), DZ14.1 (K), MCU1.J1_15 (GPIO9), P3.4, R12.1
GND: AMP1.4 (V-), AMP2.4 (V-), AMP3.4 (V-), AMP4.4 (V-), C1.2, C2.2, DZ2.2 (A), DZ4.2 (A), DZ6.2 (A), DZ8.2 (A), DZ10.2 (A), DZ12.2 (A), DZ14.2 (A), MCU1.J3_1 (GND__1), P1.3, P5.1, PS1.3 (-Vout), PS2.1 (GND), R2.2
Line A: J1.1, PS1.1 (AC/L), R3.2
Line B: J1.2, R4.2
Line C: J2.1, R5.2
MISO: MCU1.J1_11 (GPIO18), P5.3
MOSI: MCU1.J1_9 (GPIO16), P5.4
unnamed: PS1.4 (+Vout), SW1.2 (B)
unnamed: R3.1, TP1.1
unnamed: R4.1, TP2.1
unnamed: R5.1, TP3.1
Neutral: J2.2, PS1.2 (AC/N), TP1.2, TP2.2, TP3.2
SCK: MCU1.J1_10 (GPIO17), P5.5
TC A-1: AMP1.3 (+), AMP1.6 (-), AMP1.7, AMP2.3 (+), AMP2.5 (+), AMP3.3 (+), AMP3.5 (+), AMP4.3 (+), AMP4.5 (+), J3.1, J4.1, J5.1, J6.1, P2.1, TP1.4, TP2.4, TP3.4
TC A-2: AMP2.6 (-), J3.2, R9.2
TC B-2: AMP3.6 (-), J4.2, R10.2
TC C-2: AMP4.2 (-), J5.2, R11.2
TC N-2: AMP4.6 (-), J6.2, R12.2
TP A-1: AMP1.2 (-), R6.1, TP1.3
TP B-1: AMP2.2 (-), R7.1, TP2.3
TP C-1: AMP3.2 (-), R8.1, TP3.3
UART RX: MCU1.J3_3 (U0RXD/GPIO44), P1.1
UART TX: MCU1.J3_2 (U0TXD/GPIO43), P1.2
V1.65: AMP1.5 (+), R1.2, R2.1
Vcc: C2.1, DZ1.1 (K), DZ3.1 (K), DZ5.1 (K), DZ7.1 (K), DZ9.1 (K), DZ11.1 (K), DZ13.1 (K), MCU1.J1_1 (3V3), P5.2, PS2.2 (VO), R1.1
Vin: AMP1.8 (V+), AMP2.8 (V+), AMP3.8 (V+), AMP4.8 (V+), C1.1, PS2.3 (VI), SW1.1 (C)
Wave A: AMP1.1, DZ1.2 (A), DZ2.1 (K), MCU1.J1_4 (GPIO4), P4.1, R6.2
Wave B: AMP2.1, DZ3.2 (A), DZ4.1 (K), MCU1.J1_5 (GPIO5), P4.2, R7.2
Wave C: AMP3.1, DZ5.2 (A), DZ6.1 (K), MCU1.J1_7 (GPIO7), P4.3, R8.2

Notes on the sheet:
43Ω
Resistor to Voltage (Secundary)
Type
15Ω
220Vac
380Vac
Biphasic (2P)
560Ω
RSvolt
500A
Type of Electrical System
Voltage Type
Current
300A
MCU
4.3Ω
750A
440Vac
6.8Ω
RPvolt
Power
270kΩ
100kΩ
Voltage
Voltage Inputs
System Type
27Ω
10Ω
Resistor to Voltage (Primary)
After selecting the ideal resistor for your application, according to the tables, remember to modify the value of the variables "CURRENT TYPE", "VOLTAGE_TYPE" and "SYSTEM_TYPE" in the MCU code according to what's in the tables
120A
Protection Zeners
127Vac
TL082s Power
180kΩ
Signals Conditioning
1000A
Current Type
Voltage Transformation
200A

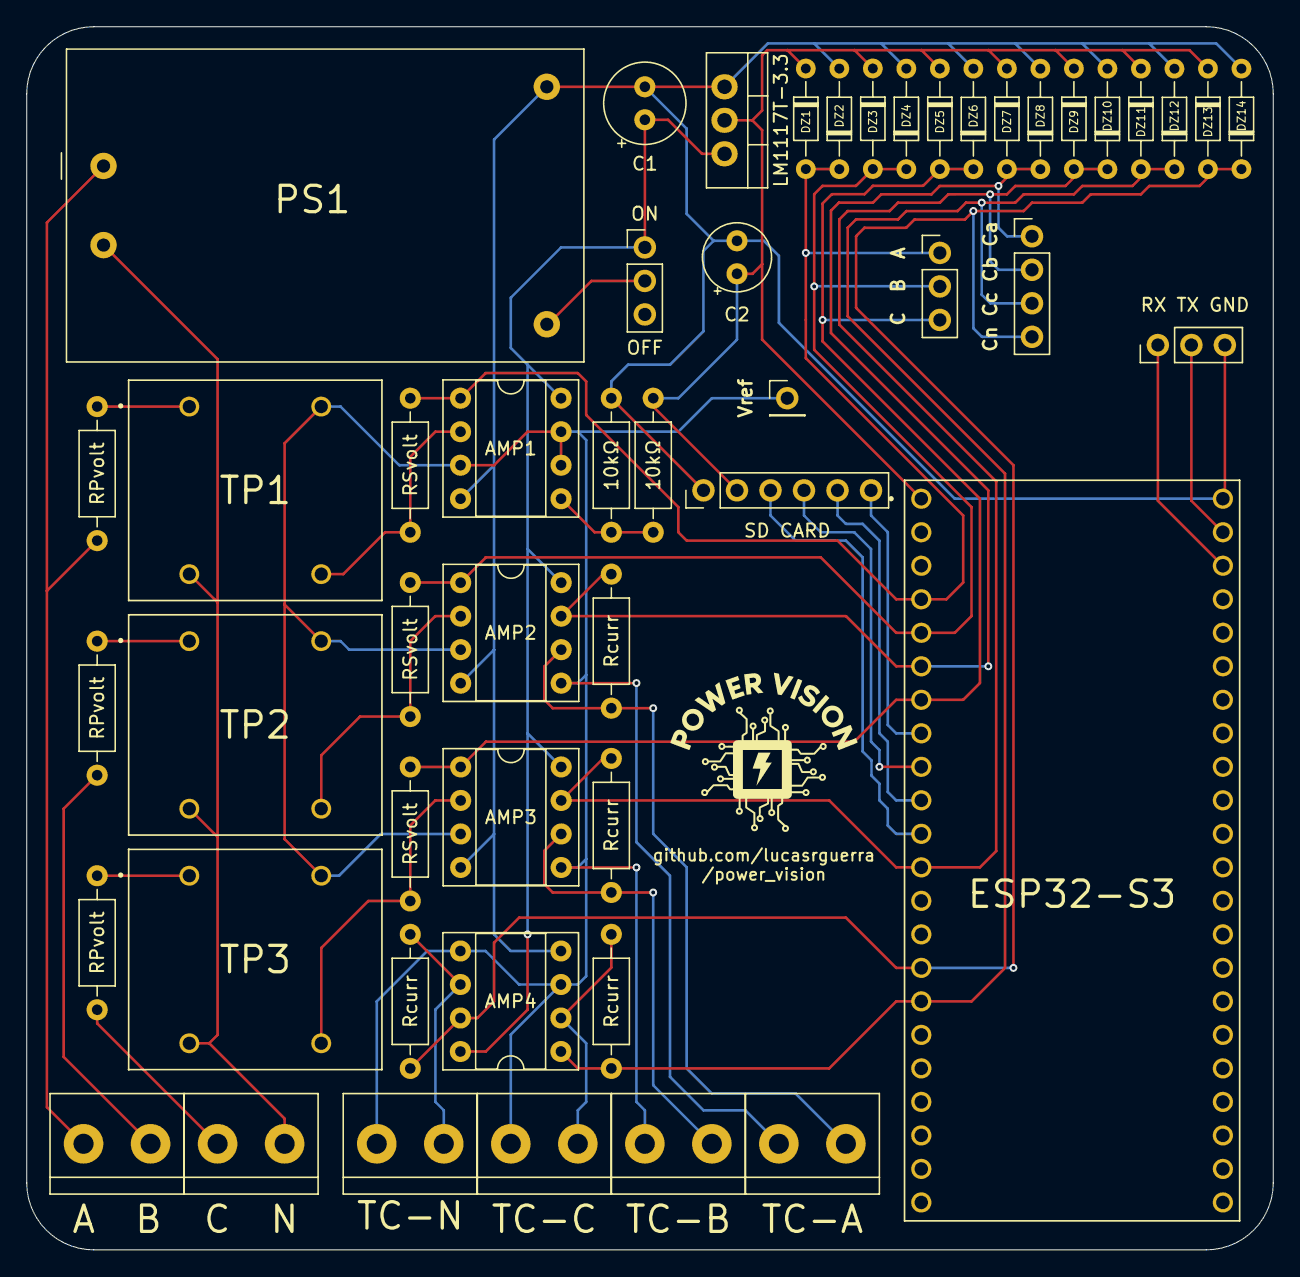
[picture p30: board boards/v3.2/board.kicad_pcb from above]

Board: 2 copper layers, 94.5 x 92.7 mm, 50 parts (0 on the bottom side), 33 nets.

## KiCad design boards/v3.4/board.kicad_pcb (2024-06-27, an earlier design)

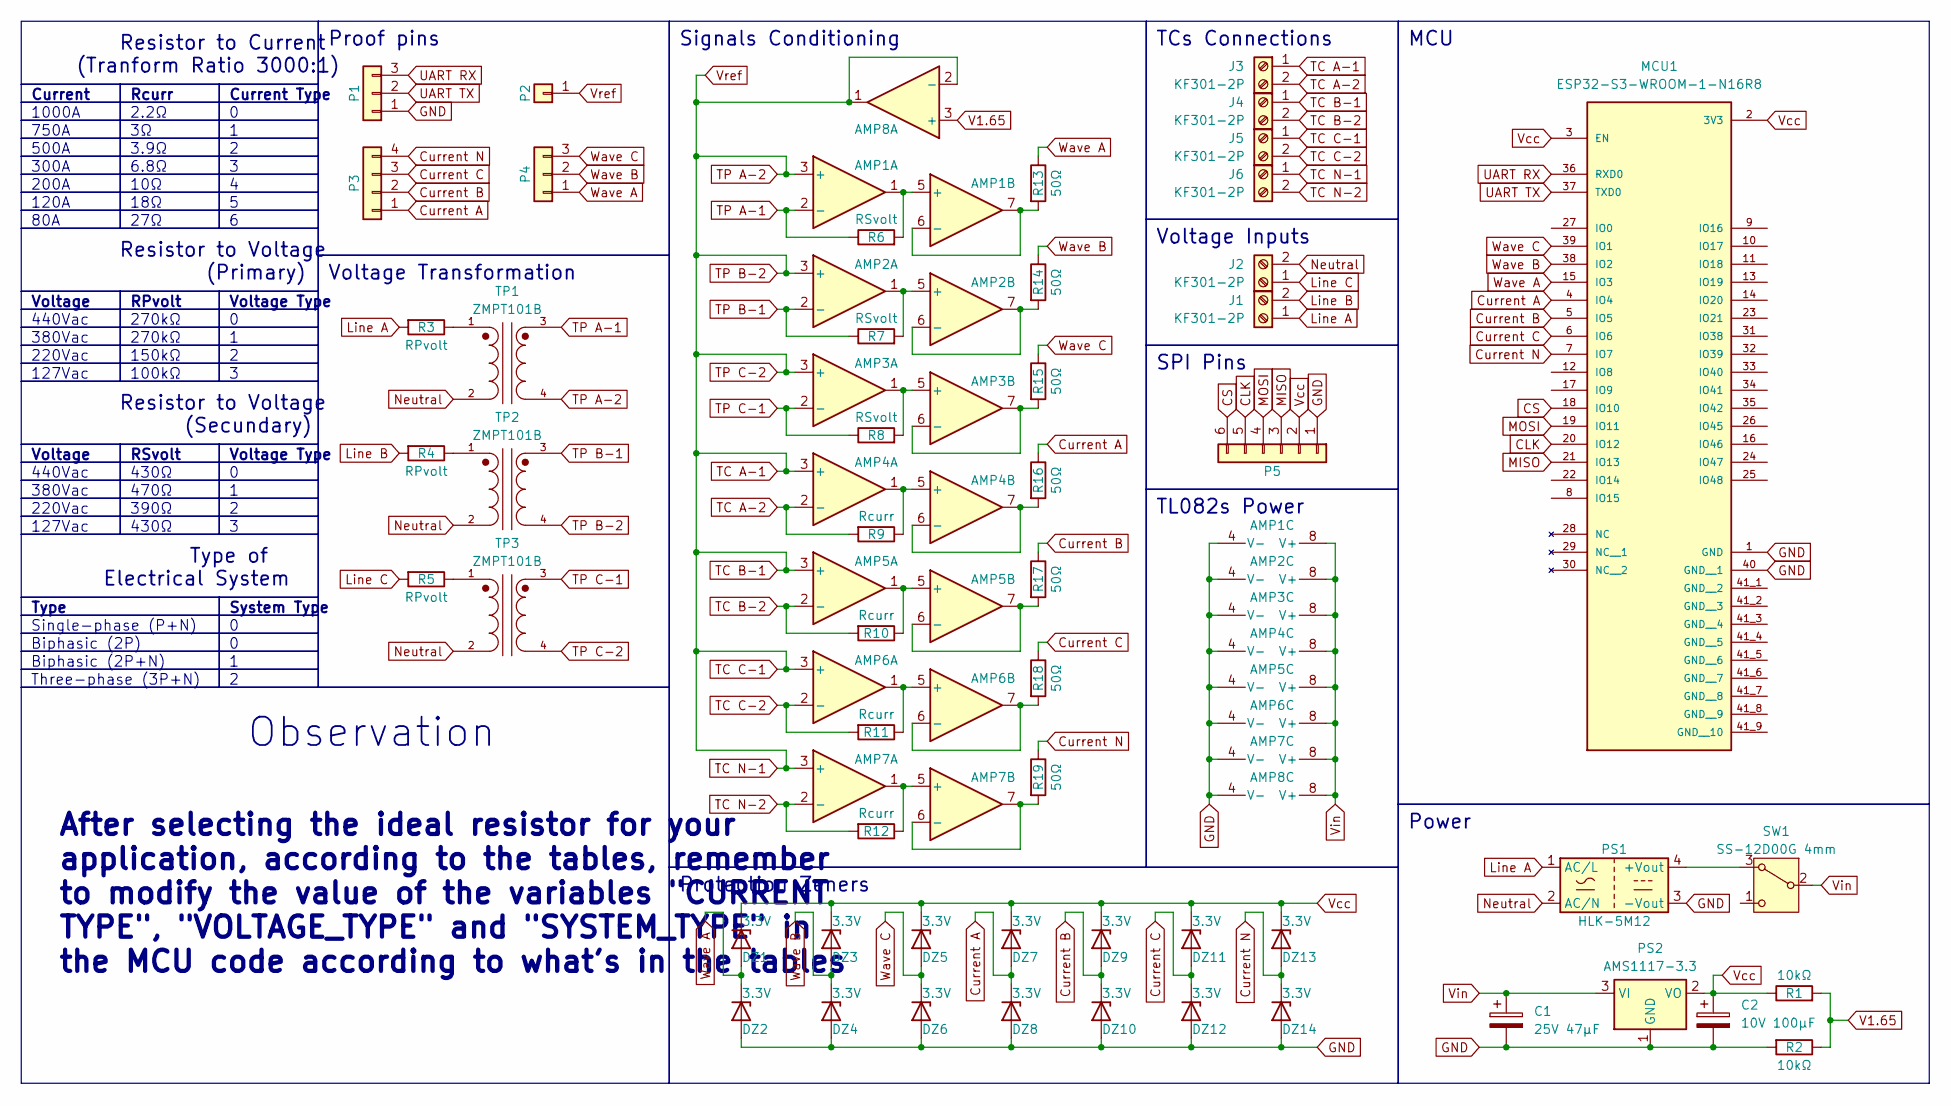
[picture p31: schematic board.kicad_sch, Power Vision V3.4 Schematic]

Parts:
AMP1, AMP2, AMP3, AMP4, AMP5, AMP6, AMP7, AMP8: TL082; SO-8_3.9x4.9mm_P1.27mm
C1: 25V 47µF; CP_EIA-6032-20_AVX-F
C2: 10V 100µF; CP_EIA-3528-15_AVX-H
DZ1, DZ2, DZ3, DZ4, DZ5, DZ6, DZ7, DZ8, DZ9, DZ10, DZ11, DZ12, DZ13, DZ14: 3.3V; D_MELF
J1, J2, J3, J4, J5, J6: KF301-2P; TerminalBlock_bornier-2_P5.08mm
MCU1: ESP32-S3-WROOM-1-N16R8; XCVR_ESP32-S3-WROOM-2-N32R8V; PARTREV 1.0
P1, P4: Pin Header; PinHeader_1x03_P2.54mm_Vertical
P2: Pin Header; PinHeader_1x01_P2.54mm_Vertical
P3: Pin Header; PinHeader_1x04_P2.54mm_Vertical
P5: Pin Header; PinHeader_1x06_P2.54mm_Vertical
PS1: HLK-5M12; Converter_ACDC_HiLink_HLK-5Mxx
PS2: AMS1117-3.3; SOT-223-3_TabPin2
R1, R2: 10kΩ; R_1210_3225Metric
R3, R4, R5: RPvolt; R_1210_3225Metric
R6, R7, R8: RSvolt; R_1210_3225Metric
R9, R10, R11, R12: Rcurr; R_1210_3225Metric
R13, R14, R15, R16, R17, R18, R19: 50Ω; R_1210_3225Metric
SW1: SS-12D00G 4mm; PinHeader_1x03_P2.54mm_Vertical
TP1, TP2, TP3: ZMPT101B; XFMR_ZMPT101B; PARTREV NA

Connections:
CLK: MCU1.20 (IO12), P5.5
CS: MCU1.18 (IO10), P5.6
Current A: DZ7.2 (A), DZ8.1 (K), MCU1.4 (IO4), P3.1, R16.1
Current B: DZ9.2 (A), DZ10.1 (K), MCU1.5 (IO5), P3.2, R17.1
Current C: DZ11.2 (A), DZ12.1 (K), MCU1.6 (IO6), P3.3, R18.1
Current N: DZ13.2 (A), DZ14.1 (K), MCU1.7 (IO7), P3.4, R19.1
GND: AMP1.4 (V-), AMP2.4 (V-), AMP3.4 (V-), AMP4.4 (V-), AMP5.4 (V-), AMP6.4 (V-), AMP7.4 (V-), AMP8.4 (V-), C1.2, C2.2, DZ2.2 (A), DZ4.2 (A), DZ6.2 (A), DZ8.2 (A), DZ10.2 (A), DZ12.2 (A), DZ14.2 (A), MCU1.1 (GND), MCU1.40 (GND__1), P1.1, P5.1, PS1.3 (-Vout), PS2.1 (GND), R2.2
Line A: J1.1, PS1.1 (AC/L), R3.2
Line B: J1.2, R4.2
Line C: J2.1, R5.2
MISO: MCU1.21 (IO13), P5.3
MOSI: MCU1.19 (IO11), P5.4
unnamed: AMP1.1, AMP1.5 (+), R6.2
unnamed: AMP1.6 (-), AMP1.7, R13.2
unnamed: AMP2.1, AMP2.5 (+), R7.2
unnamed: AMP2.6 (-), AMP2.7, R14.2
unnamed: AMP3.1, AMP3.5 (+), R8.2
unnamed: AMP3.6 (-), AMP3.7, R15.2
unnamed: AMP4.1, AMP4.5 (+), R9.1
unnamed: AMP4.6 (-), AMP4.7, R16.2
unnamed: AMP5.1, AMP5.5 (+), R10.1
unnamed: AMP5.6 (-), AMP5.7, R17.2
unnamed: AMP6.1, AMP6.5 (+), R11.1
unnamed: AMP6.6 (-), AMP6.7, R18.2
unnamed: AMP7.1, AMP7.5 (+), R12.1
unnamed: AMP7.6 (-), AMP7.7, R19.2
unnamed: PS1.4 (+Vout), SW1.3 (A)
unnamed: R3.1, TP1.1
unnamed: R4.1, TP2.1
unnamed: R5.1, TP3.1
Neutral: J2.2, PS1.2 (AC/N), TP1.2, TP2.2, TP3.2
TC A-1: AMP1.3 (+), AMP2.3 (+), AMP3.3 (+), AMP4.3 (+), AMP5.3 (+), AMP6.3 (+), AMP7.3 (+), AMP8.1, AMP8.2 (-), J3.1, J4.1, J5.1, J6.1, P2.1, TP1.4, TP2.4, TP3.4
TC A-2: AMP4.2 (-), J3.2, R9.2
TC B-2: AMP5.2 (-), J4.2, R10.2
TC C-2: AMP6.2 (-), J5.2, R11.2
TC N-2: AMP7.2 (-), J6.2, R12.2
TP A-1: AMP1.2 (-), R6.1, TP1.3
TP B-1: AMP2.2 (-), R7.1, TP2.3
TP C-1: AMP3.2 (-), R8.1, TP3.3
UART RX: MCU1.36 (RXD0), P1.3
UART TX: MCU1.37 (TXD0), P1.2
V1.65: AMP8.3 (+), R1.2, R2.1
Vcc: C2.1, DZ1.1 (K), DZ3.1 (K), DZ5.1 (K), DZ7.1 (K), DZ9.1 (K), DZ11.1 (K), DZ13.1 (K), MCU1.2 (3V3), MCU1.3 (EN), P5.2, PS2.2 (VO), R1.1
Vin: AMP1.8 (V+), AMP2.8 (V+), AMP3.8 (V+), AMP4.8 (V+), AMP5.8 (V+), AMP6.8 (V+), AMP7.8 (V+), AMP8.8 (V+), C1.1, PS2.3 (VI), SW1.2 (B)
Wave A: DZ1.2 (A), DZ2.1 (K), MCU1.15 (IO3), P4.1, R13.1
Wave B: DZ3.2 (A), DZ4.1 (K), MCU1.38 (IO2), P4.2, R14.1
Wave C: DZ5.2 (A), DZ6.1 (K), MCU1.39 (IO1), P4.3, R15.1

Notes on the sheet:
27Ω
Resistor to Voltage (Secundary)
Type
10Ω
220Vac
380Vac
Biphasic (2P)
470Ω
RSvolt
500A
Type of Electrical System
Voltage Type
Current
300A
MCU
750A
440Vac
3.9Ω
RPvolt
Power
270kΩ
100kΩ
Voltage
Voltage Inputs
System Type
18Ω
6.8Ω
390Ω
Resistor to Voltage (Primary)
After selecting the ideal resistor for your application, according to the tables, remember to modify the value of the variables "CURRENT TYPE", "VOLTAGE_TYPE" and "SYSTEM_TYPE" in the MCU code according to what's in the tables
120A
Protection Zeners
127Vac
TL082s Power
150kΩ
Signals Conditioning
1000A
Current Type
Voltage Transformation
200A

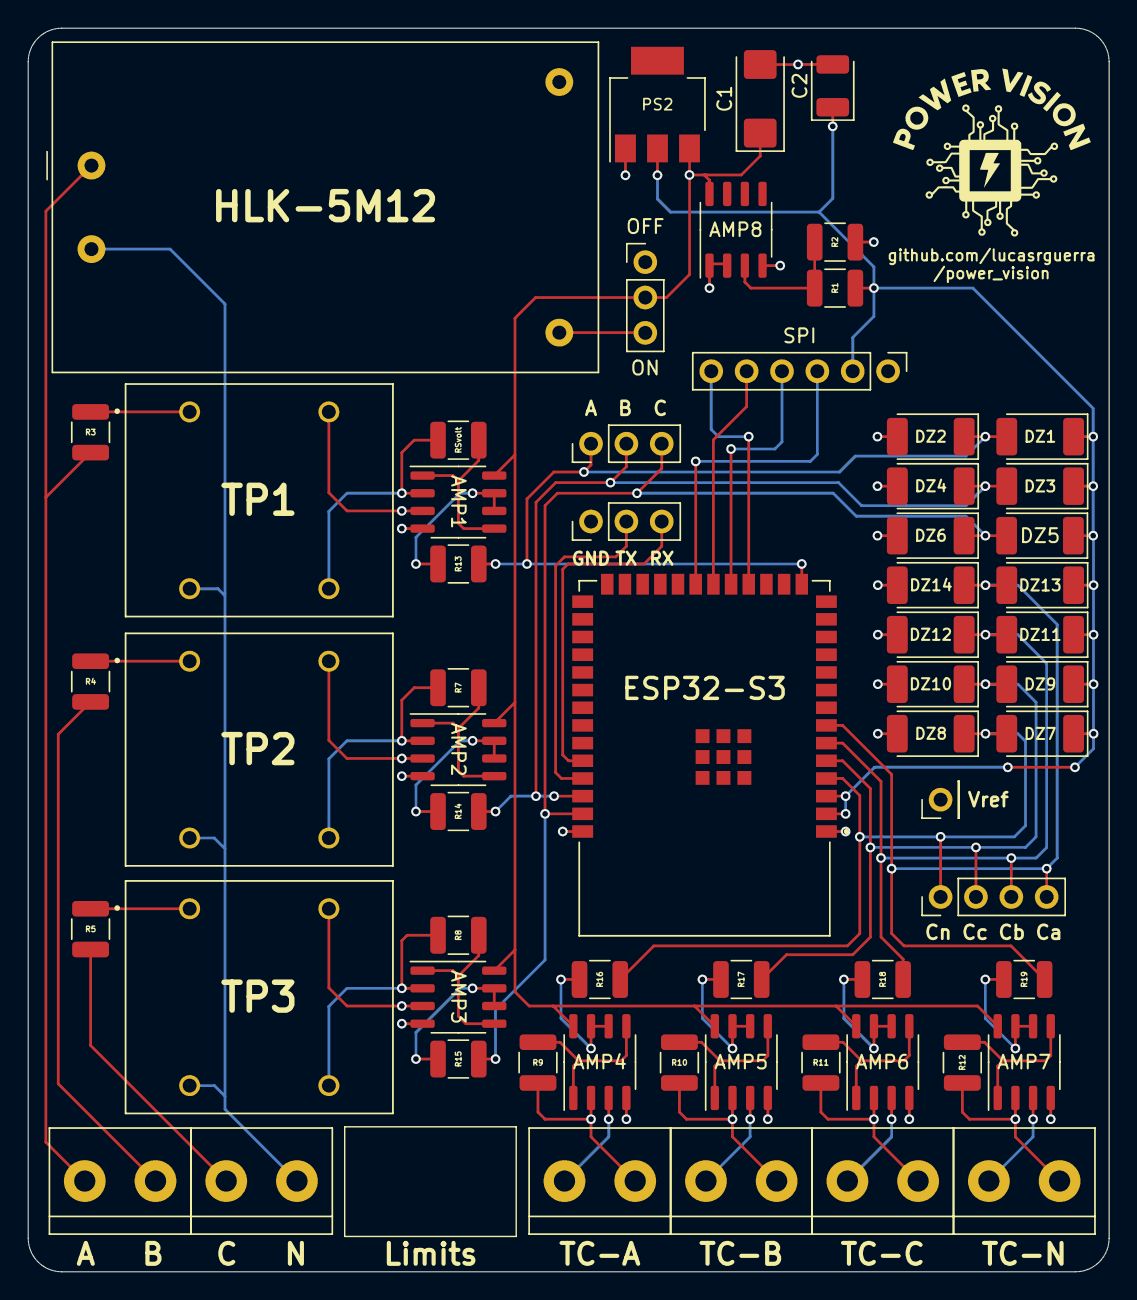
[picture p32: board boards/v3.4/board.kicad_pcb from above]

Board: 4 copper layers, 77.6 x 89.3 mm, 61 parts (0 on the bottom side), 47 nets.

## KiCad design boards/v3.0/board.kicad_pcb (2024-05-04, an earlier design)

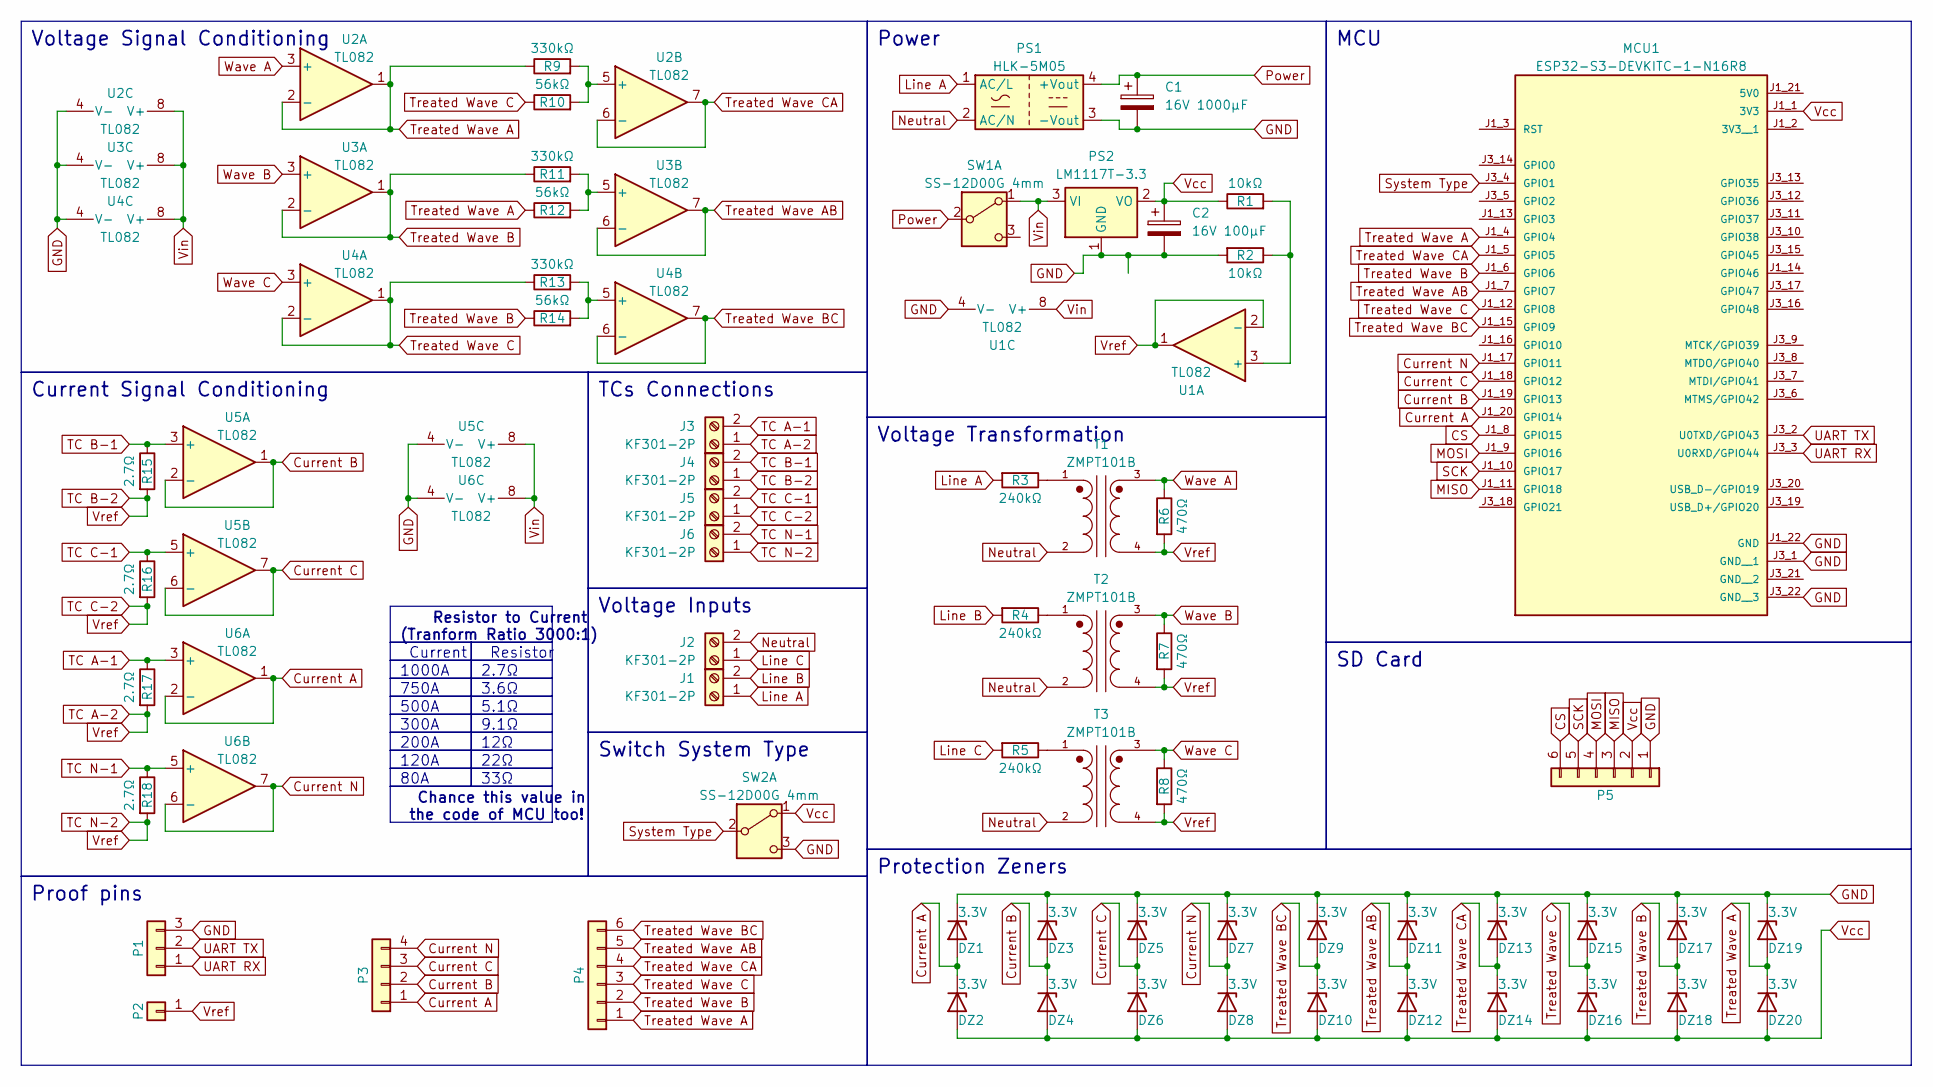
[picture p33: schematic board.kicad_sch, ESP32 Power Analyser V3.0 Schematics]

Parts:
C1: 16V 1000µF; CP_Radial_D6.3mm_P2.50mm
C2: 16V 100µF; CP_Radial_D5.0mm_P2.00mm
DZ1, DZ2, DZ3, DZ4, DZ5, DZ6, DZ7, DZ8, DZ9, DZ10, DZ11, DZ12, DZ13, DZ14, DZ15, DZ16, DZ17, DZ18, DZ19, DZ20: 3.3V; D_DO-34_SOD68_P7.62mm_Horizontal
J1, J2, J3, J4, J5, J6: KF301-2P; TerminalBlock_bornier-2_P5.08mm
MCU1: ESP32-S3-DEVKITC-1-N16R8; XCVR_ESP32-S3-DEVKITC-1-N8R2; PARTREV V1
P1: Pin Header; PinHeader_1x03_P2.54mm_Vertical
P2: Pin Header; PinHeader_1x01_P2.54mm_Vertical
P3: Pin Header; PinHeader_1x04_P2.54mm_Vertical
P4, P5: Pin Header; PinHeader_1x06_P2.54mm_Vertical
PS1: HLK-5M05; Converter_ACDC_HiLink_HLK-5Mxx
PS2: LM1117T-3.3; TO-220-3_Vertical
R1, R2: 10kΩ; R_Axial_DIN0207_L6.3mm_D2.5mm_P10.16mm_Horizontal
R3, R4, R5: 240kΩ; R_Axial_DIN0207_L6.3mm_D2.5mm_P10.16mm_Horizontal
R6, R7, R8: 470Ω; R_Axial_DIN0207_L6.3mm_D2.5mm_P10.16mm_Horizontal
R9, R11, R13: 330kΩ; R_Axial_DIN0207_L6.3mm_D2.5mm_P10.16mm_Horizontal
R10, R12, R14: 56kΩ; R_Axial_DIN0207_L6.3mm_D2.5mm_P10.16mm_Horizontal
R15, R16, R17, R18: 2.7Ω; R_Axial_DIN0207_L6.3mm_D2.5mm_P10.16mm_Horizontal
SW1, SW2: SS-12D00G 4mm; PinHeader_1x03_P2.54mm_Vertical
T1, T2, T3: ZMPT101B; XFMR_ZMPT101B; PARTREV NA
U1, U2, U3, U4, U5, U6: TL082; DIP-8_W7.62mm_Socket

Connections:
CS: MCU1.J1_8 (GPIO15), P5.6
Current A: DZ1.2 (A), DZ2.1 (K), MCU1.J1_20 (GPIO14), P3.1, U6.1, U6.2 (-)
Current B: DZ3.2 (A), DZ4.1 (K), MCU1.J1_19 (GPIO13), P3.2, U5.1, U5.2 (-)
Current C: DZ5.2 (A), DZ6.1 (K), MCU1.J1_18 (GPIO12), P3.3, U5.6 (-), U5.7
Current N: DZ7.2 (A), DZ8.1 (K), MCU1.J1_17 (GPIO11), P3.4, U6.6 (-), U6.7
GND: C1.2, C2.2, DZ1.1 (K), DZ3.1 (K), DZ5.1 (K), DZ7.1 (K), DZ9.1 (K), DZ11.1 (K), DZ13.1 (K), DZ15.1 (K), DZ17.1 (K), DZ19.1 (K), MCU1.J1_22 (GND), MCU1.J3_1 (GND__1), MCU1.J3_22 (GND__3), P1.3, P5.1, PS1.3 (-Vout), PS2.1 (GND), R2.2, SW2.3 (C), U1.4 (V-), U2.4 (V-), U3.4 (V-), U4.4 (V-), U5.4 (V-), U6.4 (V-)
Line A: J1.1, PS1.1 (AC/L), R3.2
Line B: J1.2, R4.2
Line C: J2.1, R5.2
MISO: MCU1.J1_11 (GPIO18), P5.3
MOSI: MCU1.J1_9 (GPIO16), P5.4
unnamed: R3.1, T1.1
unnamed: R4.1, T2.1
unnamed: R5.1, T3.1
unnamed: R1.2, R2.1, U1.3 (+)
unnamed: R9.2, R10.2, U2.5 (+)
unnamed: R11.2, R12.2, U3.5 (+)
unnamed: R13.2, R14.2, U4.5 (+)
Neutral: J2.2, PS1.2 (AC/N), T1.2, T2.2, T3.2
Power: C1.1, PS1.4 (+Vout), SW1.2 (B)
SCK: MCU1.J1_10 (GPIO17), P5.5
System Type: MCU1.J3_4 (GPIO1), SW2.2 (B)
TC A-1: J3.2, R17.1, U6.3 (+)
TC A-2: J3.1, J4.1, J5.1, J6.1, P2.1, R6.2, R7.2, R8.2, R15.2, R16.2, R17.2, R18.2, T1.4, T2.4, T3.4, U1.1, U1.2 (-)
TC B-1: J4.2, R15.1, U5.3 (+)
TC C-1: J5.2, R16.1, U5.5 (+)
TC N-1: J6.2, R18.1, U6.5 (+)
Treated Wave A: DZ19.2 (A), DZ20.1 (K), MCU1.J1_4 (GPIO4), P4.1, R9.1, R12.1, U2.1, U2.2 (-)
Treated Wave AB: DZ11.2 (A), DZ12.1 (K), MCU1.J1_7 (GPIO7), P4.5, U3.6 (-), U3.7
Treated Wave B: DZ17.2 (A), DZ18.1 (K), MCU1.J1_6 (GPIO6), P4.2, R11.1, R14.1, U3.1, U3.2 (-)
Treated Wave BC: DZ9.2 (A), DZ10.1 (K), MCU1.J1_15 (GPIO9), P4.6, U4.6 (-), U4.7
Treated Wave C: DZ15.2 (A), DZ16.1 (K), MCU1.J1_12 (GPIO8), P4.3, R10.1, R13.1, U4.1, U4.2 (-)
Treated Wave CA: DZ13.2 (A), DZ14.1 (K), MCU1.J1_5 (GPIO5), P4.4, U2.6 (-), U2.7
UART RX: MCU1.J3_3 (U0RXD/GPIO44), P1.1
UART TX: MCU1.J3_2 (U0TXD/GPIO43), P1.2
Vcc: C2.1, DZ2.2 (A), DZ4.2 (A), DZ6.2 (A), DZ8.2 (A), DZ10.2 (A), DZ12.2 (A), DZ14.2 (A), DZ16.2 (A), DZ18.2 (A), DZ20.2 (A), MCU1.J1_1 (3V3), P5.2, PS2.2 (VO), R1.1, SW2.1 (A)
Vin: PS2.3 (VI), SW1.1 (A), U1.8 (V+), U2.8 (V+), U3.8 (V+), U4.8 (V+), U5.8 (V+), U6.8 (V+)
Wave A: R6.1, T1.3, U2.3 (+)
Wave B: R7.1, T2.3, U3.3 (+)
Wave C: R8.1, T3.3, U4.3 (+)

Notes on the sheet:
33Ω
12Ω
500A
Chance this value in the code of MCU too!
Current
300A
MCU
3.6Ω
750A
5.1Ω
Power
Voltage Inputs
22Ω
9.1Ω
120A
Protection Zeners
Current Signal Conditioning
1000A
Voltage Transformation
200A
Switch System Type
80A
SD Card
Resistor
2.7Ω
Resistor to Current (Tranform Ratio 3000:1)
TCs Connections
Proof pins
Voltage Signal Conditioning

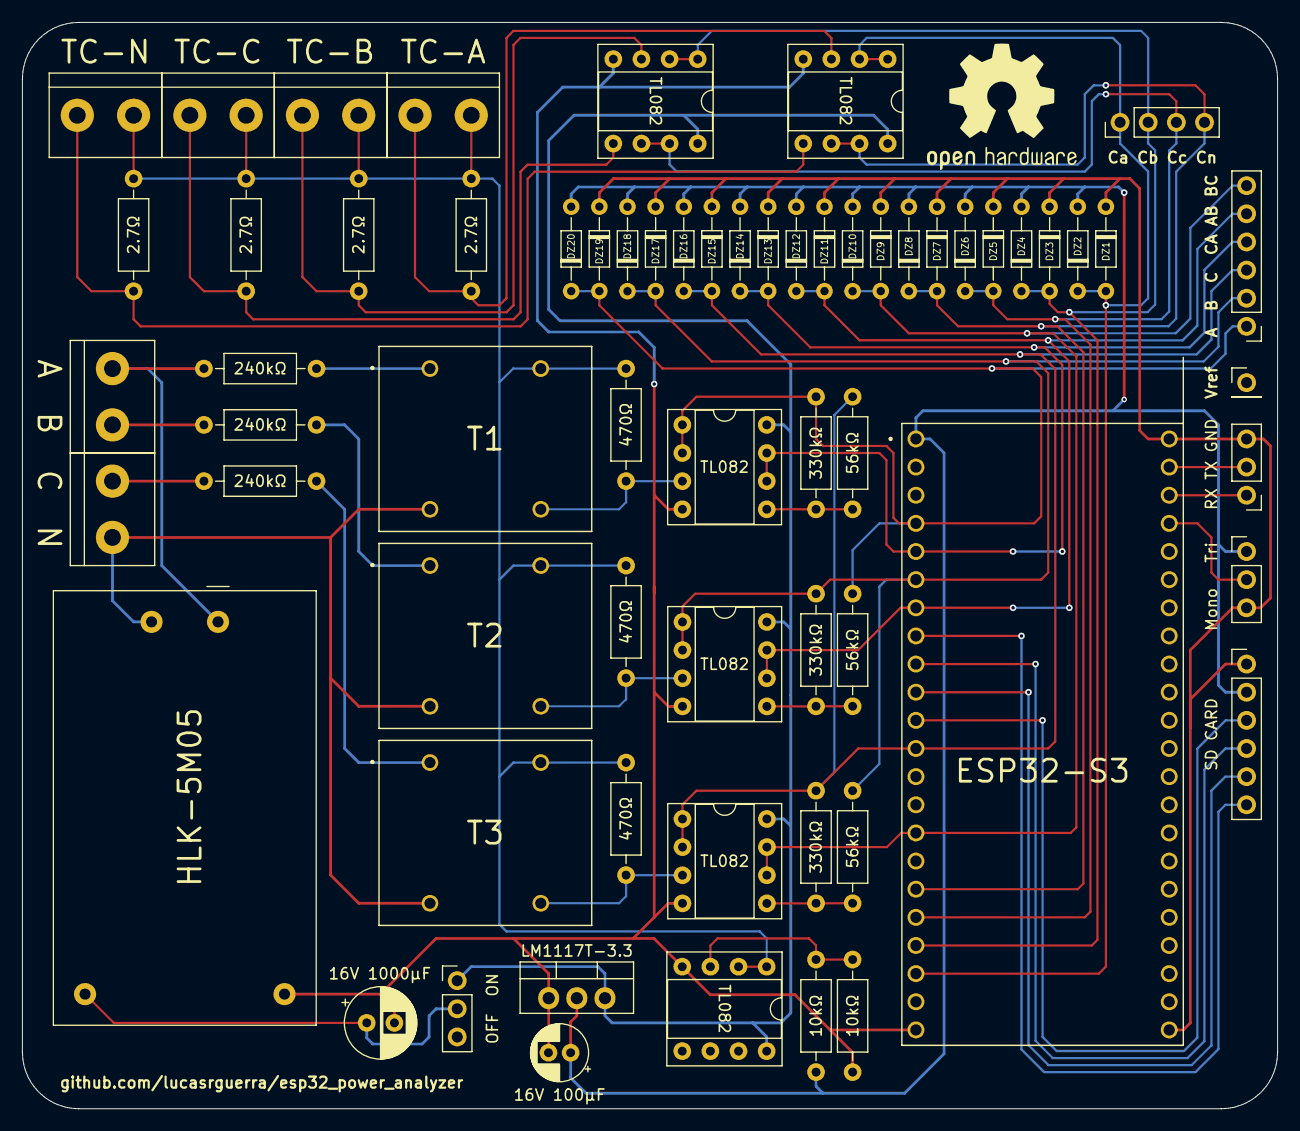
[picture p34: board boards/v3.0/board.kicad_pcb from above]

Board: 2 copper layers, 113.3 x 98.0 mm, 65 parts (0 on the bottom side), 40 nets.

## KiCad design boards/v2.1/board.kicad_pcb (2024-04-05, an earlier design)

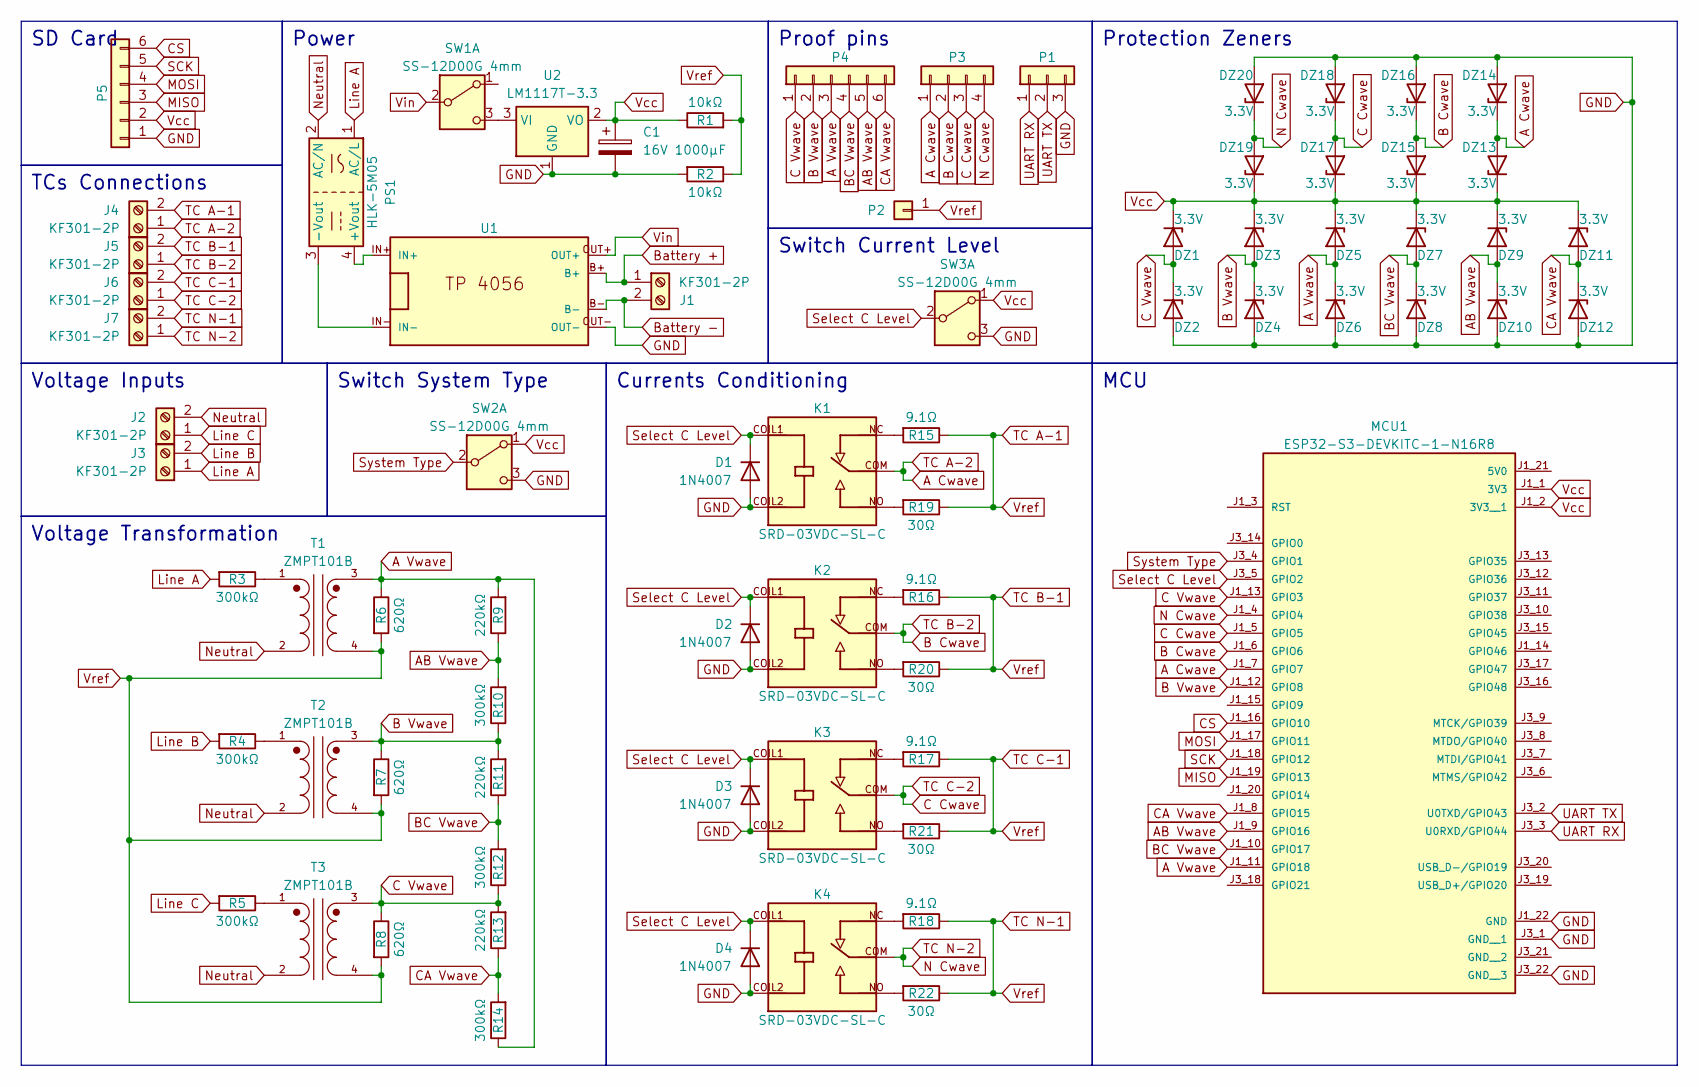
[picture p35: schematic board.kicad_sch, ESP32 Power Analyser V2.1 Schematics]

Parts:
C1: 16V 1000µF; CP_Radial_D6.3mm_P2.50mm
D1, D2, D3, D4: 1N4007; D_DO-41_SOD81_P10.16mm_Horizontal
DZ1, DZ2, DZ3, DZ4, DZ5, DZ6, DZ7, DZ8, DZ9, DZ10, DZ11, DZ12, DZ13, DZ14, DZ15, DZ16, DZ17, DZ18, DZ19, DZ20: 3.3V; D_DO-34_SOD68_P7.62mm_Horizontal
J1, J2, J3, J4, J5, J6, J7: KF301-2P; TerminalBlock_bornier-2_P5.08mm
K1, K2, K3, K4: SRD-03VDC-SL-C; RELAY_SRD-03VDC-SL-C; PARTREV 20161104
MCU1: ESP32-S3-DEVKITC-1-N16R8; XCVR_ESP32-S3-DEVKITC-1-N8R2; PARTREV V1
P1: Pin Header; PinHeader_1x03_P2.54mm_Vertical
P2: Pin Header; PinHeader_1x01_P2.54mm_Vertical
P3: Pin Header; PinHeader_1x04_P2.54mm_Vertical
P4, P5: Pin Header; PinHeader_1x06_P2.54mm_Vertical
PS1: HLK-5M05; Converter_ACDC_HiLink_HLK-5Mxx
R1, R2: 10kΩ; R_Axial_DIN0207_L6.3mm_D2.5mm_P10.16mm_Horizontal
R3, R4, R5, R10, R12, R14: 300kΩ; R_Axial_DIN0207_L6.3mm_D2.5mm_P10.16mm_Horizontal
R6, R7, R8: 620Ω; R_Axial_DIN0207_L6.3mm_D2.5mm_P10.16mm_Horizontal
R9, R11, R13: 220kΩ; R_Axial_DIN0207_L6.3mm_D2.5mm_P10.16mm_Horizontal
R15, R16, R17, R18: 9.1Ω; R_Axial_DIN0207_L6.3mm_D2.5mm_P10.16mm_Horizontal
R19, R20, R21, R22: 30Ω; R_Axial_DIN0207_L6.3mm_D2.5mm_P10.16mm_Horizontal
SW1, SW2, SW3: SS-12D00G 4mm; PinHeader_1x03_P2.54mm_Vertical
T1, T2, T3: ZMPT101B; XFMR_ZMPT101B; PARTREV NA
U1: TP4056
U2: LM1117T-3.3; TO-220-3_Vertical

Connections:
A Cwave: DZ13.2 (A), DZ14.1 (K), J4.1, K1.COM, MCU1.J1_7 (GPIO7), P3.1
A Vwave: DZ5.2 (A), DZ6.1 (K), MCU1.J1_11 (GPIO18), P4.3, R6.1, R9.2, R14.1, T1.3
AB Vwave: DZ9.2 (A), DZ10.1 (K), MCU1.J1_9 (GPIO16), P4.5, R9.1, R10.2
B Cwave: DZ15.2 (A), DZ16.1 (K), J5.1, K2.COM, MCU1.J1_6 (GPIO6), P3.2
B Vwave: DZ3.2 (A), DZ4.1 (K), MCU1.J1_12 (GPIO8), P4.2, R7.1, R10.1, R11.2, T2.3
BC Vwave: DZ7.2 (A), DZ8.1 (K), MCU1.J1_10 (GPIO17), P4.4, R11.1, R12.2
Battery +: J1.1, U1.B+
Battery -: J1.2, U1.B-
C Cwave: DZ17.2 (A), DZ18.1 (K), J6.1, K3.COM, MCU1.J1_5 (GPIO5), P3.3
C Vwave: DZ1.2 (A), DZ2.1 (K), MCU1.J1_13 (GPIO3), P4.1, R8.1, R12.1, R13.2, T3.3
CA Vwave: DZ11.2 (A), DZ12.1 (K), MCU1.J1_8 (GPIO15), P4.6, R13.1, R14.2
CS: MCU1.J1_16 (GPIO10), P5.6
GND: C1.2, D1.2 (A), D2.2 (A), D3.2 (A), D4.2 (A), DZ2.2 (A), DZ4.2 (A), DZ6.2 (A), DZ8.2 (A), DZ10.2 (A), DZ12.2 (A), DZ14.2 (A), DZ16.2 (A), DZ18.2 (A), DZ20.2 (A), K1.COIL2, K2.COIL2, K3.COIL2, K4.COIL2, MCU1.J1_22 (GND), MCU1.J3_1 (GND__1), MCU1.J3_22 (GND__3), P1.3, P5.1, R2.2, SW2.3 (C), SW3.3 (C), U1.OUT-, U2.1 (GND)
Line A: J3.1, PS1.1 (AC/L), R3.2
Line B: J3.2, R4.2
Line C: J2.1, R5.2
MISO: MCU1.J1_19 (GPIO13), P5.3
MOSI: MCU1.J1_17 (GPIO11), P5.4
N Cwave: DZ19.2 (A), DZ20.1 (K), J7.1, K4.COM, MCU1.J1_4 (GPIO4), P3.4
unnamed: K1.NC, R15.2
unnamed: K1.NO, R19.2
unnamed: K2.NC, R16.2
unnamed: K2.NO, R20.2
unnamed: K3.NC, R17.2
unnamed: K3.NO, R21.2
unnamed: K4.NC, R18.2
unnamed: K4.NO, R22.2
unnamed: PS1.4 (+Vout), U1.IN+
unnamed: PS1.3 (-Vout), U1.IN-
unnamed: R3.1, T1.1
unnamed: R4.1, T2.1
unnamed: R5.1, T3.1
unnamed: SW1.3 (C), U2.3 (VI)
Neutral: J2.2, PS1.2 (AC/N), T1.2, T2.2, T3.2
SCK: MCU1.J1_18 (GPIO12), P5.5
Select C Level: D1.1 (K), D2.1 (K), D3.1 (K), D4.1 (K), K1.COIL1, K2.COIL1, K3.COIL1, K4.COIL1, MCU1.J3_5 (GPIO2), SW3.2 (B)
System Type: MCU1.J3_4 (GPIO1), SW2.2 (B)
TC A-1: J4.2, J5.2, J6.2, J7.2, P2.1, R1.2, R2.1, R6.2, R7.2, R8.2, R15.1, R16.1, R17.1, R18.1, R19.1, R20.1, R21.1, R22.1, T1.4, T2.4, T3.4
UART RX: MCU1.J3_3 (U0RXD/GPIO44), P1.1
UART TX: MCU1.J3_2 (U0TXD/GPIO43), P1.2
Vcc: C1.1, DZ1.1 (K), DZ3.1 (K), DZ5.1 (K), DZ7.1 (K), DZ9.1 (K), DZ11.1 (K), DZ13.1 (K), DZ15.1 (K), DZ17.1 (K), DZ19.1 (K), MCU1.J1_1 (3V3), MCU1.J1_2 (3V3__1), P5.2, R1.1, SW2.1 (A), SW3.1 (A), U2.2 (VO)
Vin: SW1.2 (B), U1.OUT+

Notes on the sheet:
Switch Current Level
MCU
Power
Voltage Inputs
Protection Zeners
Voltage Transformation
Switch System Type
SD Card
TCs Connections
Proof pins
Currents Conditioning

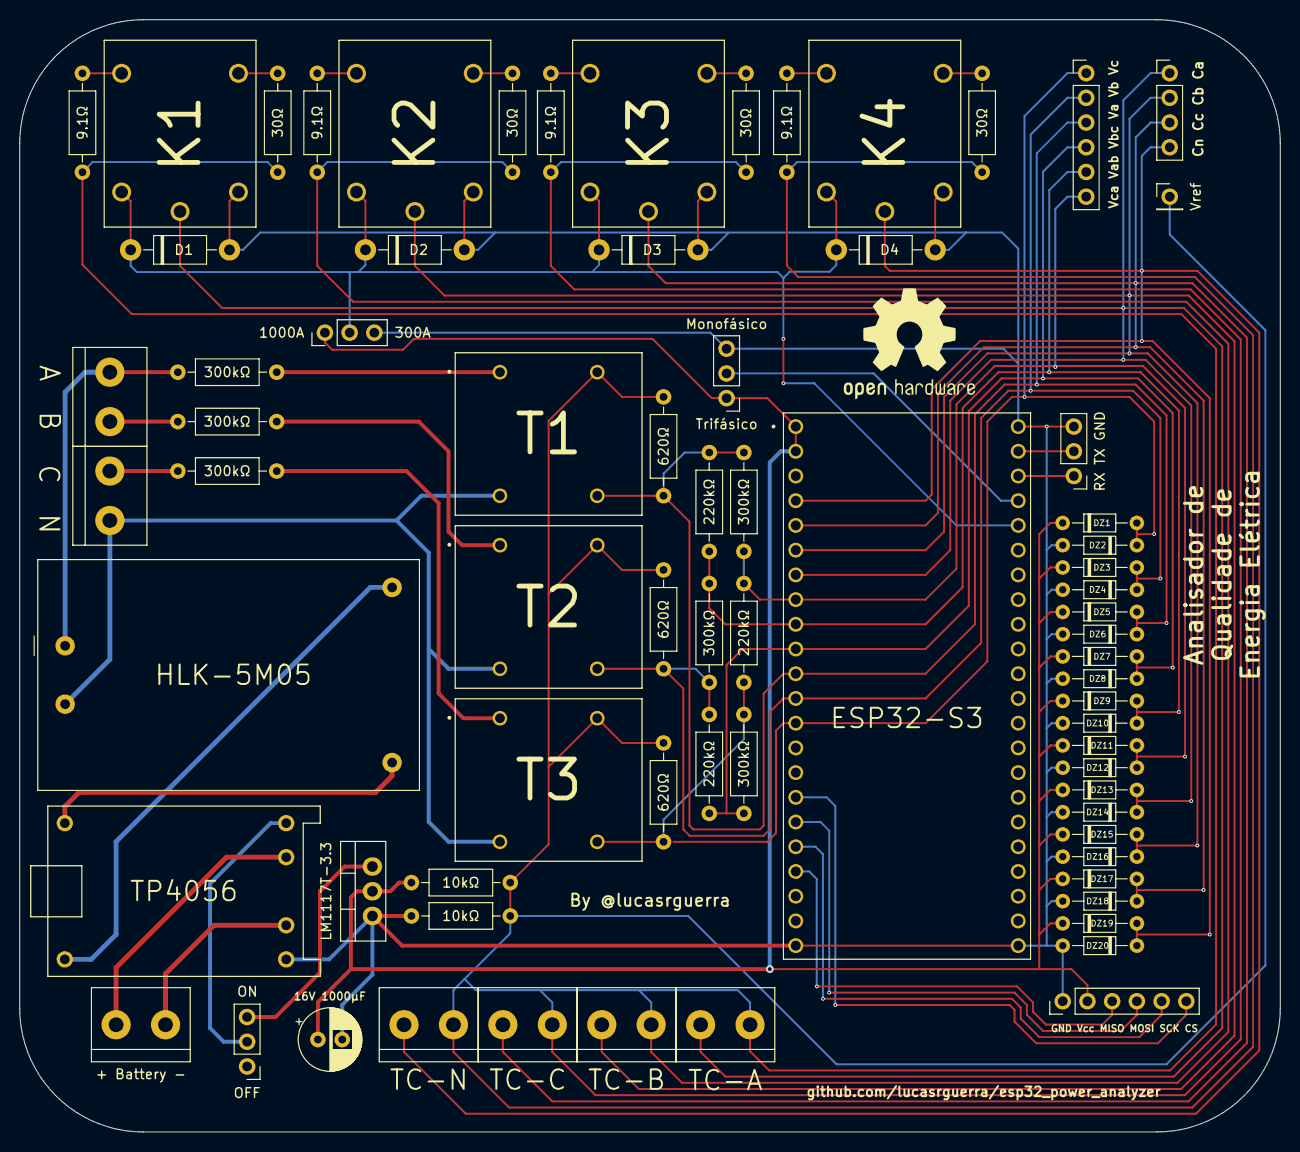
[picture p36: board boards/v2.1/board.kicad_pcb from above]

Board: 2 copper layers, 129.5 x 114.3 mm, 73 parts (0 on the bottom side), 42 nets.

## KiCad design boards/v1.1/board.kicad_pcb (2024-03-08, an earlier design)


Board: 2 copper layers, 143.5 x 73.0 mm, 72 parts (0 on the bottom side), 33 nets.

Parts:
D1: 1N4007; D_DO-34_SOD68_P7.62mm_Horizontal
DZ1, DZ2, DZ3, DZ4, DZ5, DZ6, DZ7, DZ8, DZ9, DZ10, DZ11, DZ12, DZ13, DZ14, DZ15, DZ16, DZ17, DZ18, DZ19, DZ20, DZ21, DZ22, DZ23, DZ24, DZ25, DZ26, DZ27, DZ28: 3.3v; D_DO-34_SOD68_P7.62mm_Horizontal
ESP32-S3_BACK1, ESP32-S3_FRONT1: Conn_01x22_Socket; PinSocket_1x22_P2.54mm_Vertical
K1, K1#2, K1#3, K1#4: FINDER-36.11; Relay_SPDT_Finder_36.11
R1, R2, R3, R4, R5, R6, R7, R8, R9, R10, R11, R12, R13, R14, R15, R16, R17, R18, R19, R20, R21, R22, R23, R24: R_Axial_DIN0207_L6.3mm_D2.5mm_P10.16mm_Horizontal
ST1, ST1#2, ST1#3, ST1#4, ST1#5, ST2: WJ127-5.0-2P; TerminalBlock_bornier-2_P5.08mm
SW1: TerminalBlock_bornier-2_P5.08mm; PinSocket_1x03_P2.54mm_Vertical
TP1, TP2, TP3, TP4, TP5, TP6: ZMPT101B; XFMR_ZMPT101B

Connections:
Current_A: K1.11, ST1#4.2
Current_A_30A: DZ15.1 (K), DZ16.2 (A), ESP32-S3_FRONT1.10, K1.14, R16.1
Current_A_100A: DZ13.1 (K), DZ14.2 (A), ESP32-S3_FRONT1.9, K1.12, R15.1
Current_B: K1#2.11, ST1#5.2
Current_B_30A: DZ19.1 (K), DZ20.2 (A), ESP32-S3_FRONT1.12, K1#2.14, R18.1
Current_B_100A: DZ17.1 (K), DZ18.2 (A), ESP32-S3_FRONT1.11, K1#2.12, R17.1
Current_C: K1#3.11, ST1#2.2
Current_C_30A: DZ23.1 (K), DZ24.2 (A), ESP32-S3_FRONT1.14, K1#3.14, R21.1
Current_C_100A: DZ21.1 (K), DZ22.2 (A), ESP32-S3_FRONT1.13, K1#3.12, R22.1
Current_N: K1#4.11, ST1#3.2
Current_N_90A: DZ27.1 (K), DZ28.2 (A), ESP32-S3_FRONT1.16, K1#4.14, R19.1
Current_N_300A: DZ25.1 (K), DZ26.2 (A), ESP32-S3_FRONT1.15, K1#4.12, R20.1
GND: D1.2 (A), DZ1.2 (A), DZ3.2 (A), DZ5.2 (A), DZ7.2 (A), DZ9.2 (A), DZ11.2 (A), DZ13.2 (A), DZ15.2 (A), DZ17.2 (A), DZ19.2 (A), DZ21.2 (A), DZ23.2 (A), DZ25.2 (A), DZ27.2 (A), ESP32-S3_BACK1.1, ESP32-S3_BACK1.22, ESP32-S3_FRONT1.1, K1.A2, K1#2.A2, K1#3.A1, K1#4.A1, R13.1, R24.2, SW1.3 (C)
Line_A: R1.1, R7.1, R8.1, ST1.1
Line_AB_Load: R7.2, TP4.1
Line_AB_Wave: DZ11.1 (K), DZ12.2 (A), ESP32-S3_FRONT1.6, R10.2, TP4.4
Line_AC_Load: R8.2, TP5.1
Line_AC_Wave: DZ9.1 (K), DZ10.2 (A), ESP32-S3_FRONT1.7, R11.2, TP5.4
Line_A_Load: R1.2, TP1.1
Line_A_Wave: DZ1.1 (K), DZ2.2 (A), ESP32-S3_FRONT1.5, R4.2, TP1.4
Line_B: R2.1, R9.1, ST1.2, TP4.2
Line_BC_Load: R9.2, TP6.1
Line_BC_Wave: DZ7.1 (K), DZ8.2 (A), ESP32-S3_FRONT1.8, R12.2, TP6.4
Line_B_Load: R2.2, TP2.1
Line_B_Wave: DZ3.1 (K), DZ4.2 (A), ESP32-S3_FRONT1.4, R5.2, TP2.4
Line_C: R3.1, ST2.1, TP5.2, TP6.2
Line_C_Load: R3.2, TP3.1
Line_C_Wave: DZ5.1 (K), DZ6.2 (A), ESP32-S3_FRONT1.3, R6.2, TP3.4
Neutral: ST2.2, TP1.2, TP2.2, TP3.2
Select_Current: D1.1 (K), ESP32-S3_FRONT1.17, K1.A1, K1#2.A1, K1#3.A2, K1#4.A2, SW1.2 (B)
VCC: DZ2.1 (K), DZ4.1 (K), DZ6.1 (K), DZ8.1 (K), DZ10.1 (K), DZ12.1 (K), DZ14.1 (K), DZ16.1 (K), DZ18.1 (K), DZ20.1 (K), DZ22.1 (K), DZ24.1 (K), DZ26.1 (K), DZ28.1 (K), ESP32-S3_FRONT1.22, R14.1, R23.2, SW1.1 (A)
V_Ref_Current: R15.2, R16.2, R17.2, R18.2, R19.2, R20.2, R21.2, R22.2, R23.1, R24.1, ST1#2.1, ST1#3.1, ST1#4.1, ST1#5.1
V_Ref_Voltage: R4.1, R5.1, R6.1, R10.1, R11.1, R12.1, R13.2, R14.2, TP1.3, TP2.3, TP3.3, TP4.3, TP5.3, TP6.3

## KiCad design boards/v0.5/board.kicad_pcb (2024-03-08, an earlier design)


Board: 2 copper layers, 119.4 x 116.8 mm, 71 parts (0 on the bottom side), 33 nets.

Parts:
B  A: Screw_Terminal_01x02; TerminalBlock_bornier-2_P5.08mm
Current A: Screw_Terminal_01x02; TerminalBlock_bornier-2_P5.08mm
Current B: Screw_Terminal_01x02; TerminalBlock_bornier-2_P5.08mm
Current C: Screw_Terminal_01x02; TerminalBlock_bornier-2_P5.08mm
Current Level: 50A / 200A; PinSocket_1x03_P2.54mm_Vertical
Current N: Screw_Terminal_01x02; TerminalBlock_bornier-2_P5.08mm
DZ1, DZ2, DZ3, DZ4, DZ5, DZ6, DZ7, DZ8, DZ9, DZ10, DZ11, DZ12, DZ13, DZ14, DZ15, DZ16, DZ17, DZ18, DZ19, DZ20, DZ21, DZ22, DZ23, DZ24, DZ25, DZ26, DZ27, DZ28: 3.3v; D_DO-34_SOD68_P7.62mm_Horizontal
ESP32-S3_BACK1, ESP32-S3_FRONT1: Conn_01x22_Socket; PinSocket_1x22_P2.54mm_Vertical
K1, K2, K3, K4: FINDER-36.11; Relay_SPDT_Finder_36.11
N  C: Screw_Terminal_01x02; TerminalBlock_bornier-2_P5.08mm
R1, R3, R5: 150kΩ; R_Axial_DIN0207_L6.3mm_D2.5mm_P10.16mm_Horizontal
R2, R4, R6, R8, R10, R12: 680Ω; R_Axial_DIN0207_L6.3mm_D2.5mm_P10.16mm_Horizontal
R7, R9, R11: 270kΩ; R_Axial_DIN0207_L6.3mm_D2.5mm_P10.16mm_Horizontal
R13, R15, R17: 43Ω; R_Axial_DIN0207_L6.3mm_D2.5mm_P10.16mm_Horizontal
R14, R16, R18: 10Ω; R_Axial_DIN0207_L6.3mm_D2.5mm_P10.16mm_Horizontal
R19: 15Ω; R_Axial_DIN0207_L6.3mm_D2.5mm_P10.16mm_Horizontal
R20: 3.3Ω; R_Axial_DIN0207_L6.3mm_D2.5mm_P10.16mm_Horizontal
R21, R22, R23, R24: 10kΩ; R_Axial_DIN0207_L6.3mm_D2.5mm_P10.16mm_Horizontal
T1, T2, T3, T4, T5, T6: ZMPT101B; XFMR_ZMPT101B

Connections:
A_Current: Current A.2, K1.11
B_Current: Current B.2, K2.11
C_Current: Current C.2, K3.11
Current_A_50A: DZ13.1 (K), DZ14.2 (A), ESP32-S3_FRONT1.16, K1.14, R13.2
Current_A_200A: DZ15.1 (K), DZ16.2 (A), ESP32-S3_FRONT1.15, K1.12, R14.1
Current_B_50A: DZ17.1 (K), DZ18.2 (A), ESP32-S3_FRONT1.14, K2.14, R15.2
Current_B_200A: DZ19.1 (K), DZ20.2 (A), ESP32-S3_FRONT1.13, K2.12, R16.1
Current_C_50A: DZ21.1 (K), DZ22.2 (A), ESP32-S3_FRONT1.12, K3.14, R17.2
Current_C_200A: DZ23.1 (K), DZ24.2 (A), ESP32-S3_FRONT1.11, K3.12, R18.1
Current_N_150A: DZ25.1 (K), DZ26.2 (A), ESP32-S3_FRONT1.10, K4.14, R19.2
Current_N_600A: DZ27.1 (K), DZ28.2 (A), ESP32-S3_FRONT1.9, K4.12, R20.1
GND: Current Level.1 (A), DZ1.2 (A), DZ3.2 (A), DZ5.2 (A), DZ7.2 (A), DZ9.2 (A), DZ11.2 (A), DZ13.2 (A), DZ15.2 (A), DZ17.2 (A), DZ19.2 (A), DZ21.2 (A), DZ23.2 (A), DZ25.2 (A), DZ27.2 (A), ESP32-S3_FRONT1.1, K1.A2, K2.A2, K3.A2, K4.A2, R22.2, R24.1
Line_A: B A.2, R1.1, R7.1, T6.2
Line_AB_Load: R7.2, T4.1
Line_AB_Wave: DZ7.1 (K), DZ8.2 (A), ESP32-S3_FRONT1.5, R8.2, T4.4
Line_AC_Load: R11.2, T6.1
Line_AC_Wave: DZ11.1 (K), DZ12.2 (A), ESP32-S3_FRONT1.3, R12.2, T6.4
Line_A_Load: R1.2, T1.1
Line_A_Wave: DZ1.1 (K), DZ2.2 (A), ESP32-S3_FRONT1.8, R2.2, T1.4
Line_B: B A.1, R3.1, R9.1, T4.2
Line_BC_Load: R9.2, T5.1
Line_BC_Wave: DZ9.1 (K), DZ10.2 (A), ESP32-S3_FRONT1.4, R10.2, T5.4
Line_B_Load: R3.2, T2.1
Line_B_Wave: DZ3.1 (K), DZ4.2 (A), ESP32-S3_FRONT1.7, R4.2, T2.4
Line_C: N C.2, R5.1, R11.1, T5.2
Line_C_Load: R5.2, T3.1
Line_C_Wave: DZ5.1 (K), DZ6.2 (A), ESP32-S3_FRONT1.6, R6.2, T3.4
N_Current: Current N.2, K4.11
Neutral: N C.1, T1.2, T2.2, T3.2
Select_Current: Current Level.2 (B), K1.A1, K2.A1, K3.A1, K4.A1
VCC: Current Level.3 (C), DZ2.1 (K), DZ4.1 (K), DZ6.1 (K), DZ8.1 (K), DZ10.1 (K), DZ12.1 (K), DZ14.1 (K), DZ16.1 (K), DZ18.1 (K), DZ20.1 (K), DZ22.1 (K), DZ24.1 (K), DZ26.1 (K), DZ28.1 (K), ESP32-S3_FRONT1.22, R21.2, R23.1
V_Ref_C: Current A.1, Current B.1, Current C.1, Current N.1, R13.1, R14.2, R15.1, R16.2, R17.1, R18.2, R19.1, R20.2, R23.2, R24.2
V_Ref_V: R2.1, R4.1, R6.1, R8.1, R10.1, R12.1, R21.1, R22.1, T1.3, T2.3, T3.3, T4.3, T5.3, T6.3

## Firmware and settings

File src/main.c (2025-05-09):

/* C includes */
#include <inttypes.h>
#include <stdlib.h>
#include <string.h>
#include <stdio.h>



/* ESP32 includes */
#include <freertos/FreeRTOS.h>
#include <freertos/queue.h>
#include <freertos/task.h>
#include <esp_timer.h>



/* Project includes */
#include "wifi/main.h"
#include "uart/main.h"
#include "adc/main.h"
#include "nvs/main.h"



/* Measurement definitions */
#define SENOIDE_SAMPLE_RATE         2160											// Number of samples to be taken from the sine wave SIGNAL
#define SENOIDE_SAMPLE_PERIOD       (1000000 / SENOIDE_SAMPLE_RATE)					// Period of the sine wave SIGNAL	
#define PULSE_PIN					GPIO_NUM_9										// Pin to be used as pulse pin



/* Global variables */
uint64_t last_time = 0;

static TaskHandle_t calculateData_handle = NULL;
static QueueHandle_t pulse_queue = NULL;



/* Function prototypes */
static void IRAM_ATTR pulseInterrupt(void *parameters);
static void IRAM_ATTR readInterrupt(void *parameters);
static void calculateData(void *parameters);



/* Configurations */
gpio_config_t pulse_pin_config = {
	.mode = GPIO_MODE_INPUT,
	.intr_type = GPIO_INTR_POSEDGE,
	.pull_up_en = 0,
	.pull_down_en = 1,
	.pin_bit_mask = (1ULL << PULSE_PIN),
};
esp_timer_create_args_t timer_readings_args = {
	.callback = &readInterrupt,
	.arg = NULL,
	.dispatch_method = ESP_TIMER_TASK,
	.name = "readInterrupt",
};




void app_main(void)
{
    // Configure board
	initializeUART();
	initializeNVS();
	calibrateADC();

	// Configure pulse interrupt
	gpio_config(&pulse_pin_config);
    gpio_install_isr_service(0);
    gpio_isr_handler_add(PULSE_PIN, pulseInterrupt, NULL);
    pulse_queue = xQueueCreate(10, sizeof(uint32_t));

	// Create and configure timer
	esp_timer_handle_t timer_readings;
	esp_timer_create(&timer_readings_args, &timer_readings);
	esp_timer_start_periodic(timer_readings, SENOIDE_SAMPLE_PERIOD);

	// Create tasks
    xTaskCreate(calculateData, "calculateData", 4096, NULL, 1, &calculateData_handle);
}



/*
  * Function to handle the pulse interrupt
  * 
  * @param arguments: The arguments to be passed
*/
void pulseInterrupt(void *arguments) {
	uint64_t current_time = esp_timer_get_time();
	uint64_t cycle_duration = current_time - last_time;
	last_time = current_time;
    xQueueSendFromISR(pulse_queue, &cycle_duration, NULL);
}



/*
  * Function to read the interrupt
  * 
  * @param arguments: The arguments to be passed
*/
void readInterrupt(void *arguments) {
	uint16_t sample_voltage_a = getSample(WAVE_A_VOLTAGE_CHANNEL);
	uint16_t sample_current_a = getSample(WAVE_A_CURRENT_CHANNEL);

	char samples_string[24];
	sprintf(samples_string, "samples: %d %d\n", sample_voltage_a, sample_current_a);
	uart_write_bytes(UART_PORT, samples_string, strlen(samples_string));
}



/*
  * Function to calculate the data
  * 
  * @param arguments: The arguments to be passed
*/
void calculateData(void *arguments) {
	uint64_t cycle_duration;
    while (1) {
        if (xQueueReceive(pulse_queue, &cycle_duration, portMAX_DELAY)) {
			float frequency = 1000000.0 / cycle_duration;

			char frequency_string[20];
			sprintf(frequency_string, "frequency: %.5f\n", frequency);
			uart_write_bytes(UART_PORT, frequency_string, strlen(frequency_string));
        }
		vTaskDelay(1);
    }
}

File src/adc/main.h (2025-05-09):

/* ADC Main Header */
#pragma once



/* includes */
#include <esp_adc/adc_cali_scheme.h>
#include <esp_adc/adc_cali.h>
#include <driver/gpio.h>
#include <driver/adc.h>



/* Pins definitions */
#define WAVE_A_VOLTAGE_PIN          GPIO_NUM_1
#define WAVE_B_VOLTAGE_PIN          GPIO_NUM_2
#define WAVE_C_VOLTAGE_PIN          GPIO_NUM_3
#define WAVE_A_CURRENT_PIN          GPIO_NUM_4
#define WAVE_B_CURRENT_PIN          GPIO_NUM_5
#define WAVE_C_CURRENT_PIN          GPIO_NUM_6
#define WAVE_N_CURRENT_PIN          GPIO_NUM_7
#define WAVE_A_VOLTAGE_CHANNEL      ADC1_CHANNEL_0
#define WAVE_B_VOLTAGE_CHANNEL      ADC1_CHANNEL_1
#define WAVE_C_VOLTAGE_CHANNEL      ADC1_CHANNEL_2
#define WAVE_A_CURRENT_CHANNEL      ADC1_CHANNEL_3
#define WAVE_B_CURRENT_CHANNEL      ADC1_CHANNEL_4
#define WAVE_C_CURRENT_CHANNEL      ADC1_CHANNEL_5
#define WAVE_N_CURRENT_CHANNEL      ADC1_CHANNEL_6



/* Definitions */
#define ADC_UNIT                    ADC_UNIT_1
#define ADC_ATTENUATION             ADC_ATTEN_DB_12
#define ADC_BITWIDTH                ADC_BITWIDTH_12
#define ADC_DEFAULT_VREF            1100



/* Global Variables */
extern adc_cali_handle_t calibration_handle;
extern adc_cali_curve_fitting_config_t calibration_config;



/* Function Prototypes */
void calibrateADC();
uint16_t getSample(adc1_channel_t channel);

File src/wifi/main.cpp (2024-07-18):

extern "C" {
    void initializeWiFi();
    void initializeWiFiAP();
}



#include "main.h"



/* WiFi Configures */
char WIFI_SSID[WIFI_STRING_SIZE] = "";
char WIFI_PASSWORD[WIFI_STRING_SIZE] = "";
char mac_address_string[18];

wifi_init_config_t wifi_initial_configures;
wifi_config_t wifi_configures = {
    .sta = {
        .ssid = "",
        .password = "",
    },
};
uint8_t wifi_retry_counter = 0;

bool wifi_connected = false;
bool wifi_ap_started = false;
bool wifi_connect_error = false;



/*
    * Function to handle the WiFi events
    * 
    * @param event_handler_arg: The event handler arguments
    * @param event_base: The event base
    * @param event_id: The event ID
    * @param event_data: The event data
*/
void wifiEventHandler(void *event_handler_arg, esp_event_base_t event_base, int32_t event_id,void *event_data) {
    if (event_id == WIFI_EVENT_STA_START) {
        printf("Connecting to %s\n", WIFI_SSID);
    } else if (event_id == WIFI_EVENT_STA_CONNECTED) {
        wifi_retry_counter = 0;
        printf("Connected to %s\n", WIFI_SSID);
    } else if (event_id == WIFI_EVENT_STA_DISCONNECTED) {
        if (wifi_retry_counter < WIFI_MAXIMUM_RETRY) {
            esp_wifi_connect();
            wifi_retry_counter++;
            printf("Connection to %s failed. Retrying...\n", WIFI_SSID);
        } else {
            wifi_connect_error = true;
            printf("Connection to %s failed. Maximum retries reached\n", WIFI_SSID);
        }
    } else if (event_id == IP_EVENT_STA_GOT_IP) {
        wifi_connected = true;
        ip_event_got_ip_t *event = (ip_event_got_ip_t *) event_data;
        printf("Got IP: %s\n", ip4addr_ntoa((const ip4_addr_t*)&event->ip_info.ip));
    }
}



/*
  * Function to get the MAC address
*/
void getMacAddress() {
  uint8_t mac_address[6];
  esp_wifi_get_mac(WIFI_IF_STA, mac_address);
  sprintf(mac_address_string, "%02x:%02x:%02x:%02x:%02x:%02x", mac_address[0], mac_address[1], mac_address[2], mac_address[3], mac_address[4], mac_address[5]);
}



/*
    * Function to initialize the WiFi
*/
void initializeWiFi() {
    esp_netif_init();
    esp_event_loop_create_default();
    esp_netif_create_default_wifi_sta();

    wifi_initial_configures = WIFI_INIT_CONFIG_DEFAULT();
    esp_wifi_init(&wifi_initial_configures);
    esp_event_handler_register(WIFI_EVENT, ESP_EVENT_ANY_ID, &wifiEventHandler, NULL);
    esp_event_handler_register(IP_EVENT, IP_EVENT_STA_GOT_IP, &wifiEventHandler, NULL);

    strcpy((char *) wifi_configures.sta.ssid, WIFI_SSID);
    strcpy((char *) wifi_configures.sta.password, WIFI_PASSWORD);
    esp_wifi_set_config(WIFI_IF_STA, &wifi_configures);
    esp_wifi_set_mode(WIFI_MODE_STA);
    esp_wifi_start();
    getMacAddress();
    
    esp_wifi_connect();
}



/*
    * Function to initialize the WiFi AP
*/
void initializeWiFiAP() {
    esp_netif_init();
    esp_event_loop_create_default();
    esp_netif_create_default_wifi_ap();

    wifi_initial_configures = WIFI_INIT_CONFIG_DEFAULT();
    esp_wifi_init(&wifi_initial_configures);
    
    wifi_config_t wifi_ap_configures = {
        .ap = {
        .ssid = "Power Vision",
        .password = "12345678",
        .max_connection = 5,
        },
    };
    esp_wifi_set_config(WIFI_IF_AP, &wifi_ap_configures);
    esp_wifi_set_mode(WIFI_MODE_AP);
    esp_wifi_start();
    wifi_ap_started = true;
}

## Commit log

2024-02-16 Update algorithms to power analysis and create an base MCU code to ESP32-S3
2024-03-01 Calculate the true rms voltage with ESP32-S3 DevKitC
    [board.kicad_pcb, board.kicad_sch]
2024-03-08 Update of boards
    [board-B_Cu.gbr, board-B_Mask.gbr, board-B_Paste.gbr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]
2024-03-08 Nova versão da placa
    [board-B_Cu.gbr, board-B_Mask.gbr, board-B_Paste.gbr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]
2024-03-12 Começo do desenvolvimento da placa v2.0
    [board.kicad_pcb, board.kicad_sch]
2024-03-25 Início do desenvolvimento da placa V2.0
    [board.kicad_pcb, board.kicad_sch]
2024-04-01 New version of board
    [board-B_Cu.gbr, board-B_Mask.gbr, board-B_Paste.gbr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]
2024-04-05 Atualização da placa V2.1
    [board-B_Cu.gbr, board-B_Mask.gbr, board-B_Paste.gbr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]
2024-04-29 Update all readmes and start development of board v3.0
    [board.kicad_pcb, board.kicad_sch]
2024-05-02 Finish of board v3.0 development and code update
    [board-B_Cu.gbr, board-B_Mask.gbr, board-B_Paste.gbr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]
2024-05-04 Revision of the v3.0 board
    [board-B_Cu.gbr, board-B_Mask.gbr, board-B_Paste.gbr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]
2024-05-04 Reduction in the size of v3.0 board
    [board-B_Cu.gbr, board-B_Mask.gbr, board-B_Paste.gbr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]
2024-05-04 Revision in the v3.0 board
    [board-B_Cu.gbr, board-B_Mask.gbr, board-B_Paste.gbr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]
2024-05-12 Update firmware and boards
    [board-B_Cu.gbr, board-B_Mask.gbr, board-B_Paste.gbr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]
2024-05-27 update all parts of project
    [board-B_Cu.gbr, board-B_Mask.gbr, board-B_Paste.gbr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]
2024-06-01 The last board and documentation update
    [board-B_Cu.gbr, board-B_Mask.gbr, board-B_Paste.gbr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]
2024-06-01 Update the list of components and calcs
    [board-B_Cu.gbr, board-B_Mask.gbr, board-B_Paste.gbr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]
2024-06-02 Update board v3.3
    [board-B_Cu.gbr, board-B_Mask.gbr, board-B_Paste.gbr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]
2024-06-02 Add the earth plan in the v3.3 board
    [board-B_Cu.gbr, board-B_Mask.gbr, board-B_Paste.gbr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]
2024-06-02 Recalculation of load resistors
    [board-B_Cu.gbr, board-B_Mask.gbr, board-B_Paste.gbr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]
2024-06-03 Correction on the board v3.3 silkscreen
    [board-B_Cu.gbr, board-B_Mask.gbr, board-B_Paste.gbr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]
2024-06-04 Update calcs of resistors
2024-06-04 Update and correct calcs of the signals
    [board.kicad_sch]
2024-06-27 General Update
    [board-B_Cu.gbr, board-B_Mask.gbr, board-B_Silkscreen.gbr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]
2024-06-27 Board IDs Correction and update documentation
    [board-B_Cu.gbr, board-B_Mask.gbr, board-B_Silkscreen.gbr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]
2024-07-03 Initial tests of microcontroller code
    [board-B_Cu.gbr, board-B_Mask.gbr, board-B_Silkscreen.gbr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]
2024-07-09 Initial tests of board
2024-07-09 Tests and results
    [3600-voltage_a_rms-20240708-193247.csv, 600-voltage_a_rms-20240705-165500.csv, voltage_a_rms-20240705-165130.csv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]
2024-07-12 Web App interface
    [18000-voltage_a_rms-20240710-022802.csv, 3600-voltage_a_rms-20240708-193247.csv, 600-voltage_a_rms-20240705-165500.csv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]
2024-07-12 Update the Web Application and Device WiFi Settings
2024-07-18 Code update
    [ESP32-S3_N16R8.csv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]
2024-09-28 Start V5.0 development
    [3600-voltage_a_rms-20240831-153822.csv, Microcomputer.kicad_sch, Microcontroller.kicad_sch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]
2024-09-28 Update board v5.0 docs
    [Microcomputer.kicad_sch, Microcontroller.kicad_sch, Signals Acquisition.kicad_sch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]
2024-09-29 Update in the V5 board
    [Microcomputer.kicad_sch, Microcontroller.kicad_sch, Power.kicad_sch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]
2025-05-09 Add Jupyter notebook for calculating possible sample rates
    - Introduced a new notebook `possible_sample_rates.ipynb` that calculates sample rates based on a base frequency of 60Hz.
    - The notebook iterates through a range of values to compute and print sample rates, frequencies, microseconds, and remainders for specific conditions.
    [18000-voltage_a_rms-20240710-022802.csv, 3600-voltage_a_rms-20240831-153822.csv, 600-voltage_a_rms-20240710-010727.csv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]
